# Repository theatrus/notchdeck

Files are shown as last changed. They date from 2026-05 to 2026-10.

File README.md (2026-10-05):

# NotchDeck



**NotchDeck One** is a BenchBits train controller project with USB HID and Bluetooth LE HID.
It supports our own Japanese-style **separate power lever and rotary brake**, or a
**combined mascon**. Each handle can use an AS5600 magnetic sensor or a Gray-code
contact cam. The goal is a driverless joystick with host-controlled lighting;
host/game compatibility has not yet been bench-tested.

## Current design: Rev G logic + Rev E button panel

| Assembly | Function | Provisional floorplan |
|---|---|---|
| [Logic / connectors](hardware/notchdeck-one/FLOORPLAN.md) | E73 nRF52840 module, USB/BLE, battery power, handle ports, Select/Start, two solenoids and buzzer | 115×90mm, four layers |
| [Button panel](hardware/notchdeck-buttons/README.md) | STM32G030, detachable 4×4 diode key matrix, 16 RGB LEDs | 86×120mm, two layers, 19mm key pitch |

A six-way 1mm FFC carries power, I²C and interrupt between boards. The selected cable
is Molex **0151670213** (DigiKey **WM13121-ND**); the panel guide records its reversed
connector numbering and remaining fit checks. The STM32G030 **C529330** was selected
from owned JLCPCB inventory.

The [actuator sheet](hardware/notchdeck-one/ACTUATORS.md) adds two PWM low-side
outputs, an active-buzzer output and 3.3V signals for an external 12V driver.
A TPS259461LRPWR electronic limiter protects the full battery input at 5.05A
nominal. The provisional target is two simultaneous 2A strikes of up to 100ms,
then lower PWM hold current. Use a protected ≥6A 1S pack for upstream shorts.
ACT_EN pauses charging during actuation; the PWM inputs default off.

Both hierarchical schematics are wired and pass strict ERC, complete net checks,
schematic/PCB parity and BOM audits. **Both PCBs are unrouted floorplans and are not
ready for fabrication.** The [hardware guide](hardware/README.md) tracks routing,
mechanical, power-budget and assembly work still required.

The nRF firmware builds against NCS v3.3.0, with host tests and six Rev C/D handle
profiles compiled in CI. **Panel firmware, main-board I²C integration and Rev G actuator control are
not implemented.** Keep loads disconnected when using old Rev C/D firmware.
Magnetic handles also require measured detent calibration. No production firmware,
bootloader integration or fabricated-controller validation is claimed.

## Handles and reports

Combined mode sends discrete notch values on HID **Y**: EB=`0x00`, N=`0x80`, P5=`0xFF`.
Separate-handle mode uses **Y=power, X=brake**, with brake priority and neutral
re-arming. Both magnetic and contact backends use absolute positions. See the
[handle interface](docs/06-handle-interfaces.md) for cam codes, calibration and
profiles, and the [own-build guide](docs/07-japanese-handle-build.md) for mechanisms
and the provisional panel layout.

## Checks and exports

Run from the repository root:

```sh
make -C firmware test             # host compiler only
make -C hardware verify           # KiCad 10 + Python with pcbnew
make -C hardware jlc              # separate logic and button assembly ZIPs
```

On Linux, pass `KICAD_PYTHON=python3` to hardware checks with KiCad's Python module
installed. The [hardware guide](hardware/README.md) covers setup and regeneration;
the [firmware guide](firmware/README.md) covers NCS builds and release commands.

Each hardware ZIP contains Gerbers, drill, BOM and pick-and-place (CPL) files.
Exports describe the current unfinished boards; exporting does not approve them
for manufacture. [Sourcing](docs/04-bom-sourcing.md) covers **five complete sets**:
213 installed parts and 44 JLCPCB codes per set, plus the separate cable. Stock
observations are dated snapshots, with private inventory retained outside Git.
The earlier Rev E parts order was placed; the Rev G actuator expansion still
needs a top-up for 20 sets plus 10% spares. See the sourcing guide.

[GitHub Actions](https://github.com/theatrus/notchdeck/actions/workflows/ci.yml)
publishes `notchdeck-boms` (both assembly BOMs) and `notchdeck-one-firmware`
(default nRF52840 DK bring-up UF2/HEX). Handle profiles are compile checks only;
there is no Rev E/F or STM32 image in those artifacts. CI checks floorplan DRC rules
and parity while allowing the documented unrouted connections.

## Documentation

| Guide | Contents |
|---|---|
| [Hardware](hardware/README.md) | KiCad projects, validation, manufacturing exports and open work |
| [Actuators](hardware/notchdeck-one/ACTUATORS.md) | Short protection, connectors, PWM limits and required firmware |
| [Firmware](firmware/README.md) | Build/test commands, CI artifacts and implementation status |
| [Architecture](docs/03-hardware-and-firmware-architecture.md) | Two-board design, buses, power and firmware responsibilities |
| [Sourcing](docs/04-bom-sourcing.md) | Assembly BOMs, five-set stock accounting and external parts |
| [Parts](hardware/PARTS.md) / [net plan](hardware/NETPLAN.md) | Exact selections, footprints, pad assignments and wiring |
| [Handle interfaces](docs/06-handle-interfaces.md) | Magnetic/Gray harnesses, codes, profiles and fault behavior |
| [Japanese-style handle build](docs/07-japanese-handle-build.md) | Own-build mechanics, provisional layout and cam targets |
| [Protocol](docs/02-emulation-protocol-spec.md) | HID reports, notch encoding and planned lighting features |
| [Firmware updates](docs/05-firmware-update.md) | Current artifacts, SWD access and proposed user-update path |
| [Research](docs/01-research-findings.md) | Original Zuiki/Densha de GO! protocol research and references |

## License

TBD; a project-wide license has not yet been selected. Third-party library sources
and licenses are recorded in [attributions](hardware/lib/ATTRIBUTIONS.md).

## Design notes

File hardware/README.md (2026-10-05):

# NotchDeck hardware

**Rev G logic and Rev E panel are two wired KiCad 10 assemblies:** `notchdeck-one` is the logic/handle board; `notchdeck-buttons` is the detachable 4×4 key/RGB board. The button board uses an owned **STM32G030F6P6TR / C529330** to scan a diode matrix and drive RGB locally. A six-way 1mm FFC carries I²C, interrupt and power. Select/Start remain direct inputs on the main board, alongside Reset.

| Project | Provisional PCB | Electrical components | Nets / endpoints | Assembly parts |
|---|---|---:|---|---:|
| [Logic](notchdeck-one/FLOORPLAN.md) | 115×90mm, four layers | 130 | 94 / 409 | 129 |
| [Buttons](notchdeck-buttons/README.md) | 86×120mm, two layers; 19mm key pitch | 85 | 56 / 235 | 84 |

Both have zero native ERC errors/warnings, complete independent net contracts, and matching PCB pad nets, schematic UUIDs and sourcing properties. Both are **unrouted floorplans**, with no tracks/vias/planes. Native DRC has no rule or schematic-parity violations; 323 logic and 211 button connections remain unrouted. Neither is ready to fabricate.

Open `notchdeck-one/notchdeck-one.kicad_pro` and
`notchdeck-buttons/notchdeck-buttons.kicad_pro` in KiCad 10 to inspect the complete
projects, then open each project's root schematic or PCB from its project manager.
The root schematics link the child sheets; symbols/footprints use standard KiCad
libraries plus the shared project-local `lib/` directory.

Magnetic and Gray-coded power/brake or combined mascon interfaces remain electrically unchanged. See [handle interfaces](../docs/06-handle-interfaces.md). U9 separates the two AS5600 address-0x36 channels; MAX17048 remains on another bus. Remove both R37/R38 before using an external power/combined sensor on J10.

Rev G adds [two solenoids, an active buzzer and external PWM](notchdeck-one/ACTUATORS.md). The actuator feed uses electronic current limiting, with no disposable fuse. A protected ≥6A 1S pack is mandatory for upstream battery-lead/PCB shorts. Full battery input protection is set to 5.05A nominal, with a 4.3A operating budget and two provisional 2A/100ms strikes. ACT_EN pauses charging; PWM pulldowns default the loads off.

## Source of truth and build

Edit `scripts/<project>.schgen.py` and each project's `bom/jlcpcb-parts.json`, then generate with the schematic editors closed. `notchdeck_capture.py` supplies shared wire/port capture; `kschgen.py` handles native files. Keep editor changes in those manifests before forcing regeneration. The saved PCBs become the source of truth once placement/routing proceeds; the seed floorplan script refuses to overwrite routed boards.

```sh
# From hardware/; <project> is notchdeck-one or notchdeck-buttons.
KSCHGEN_FORCE=1 make gen-notchdeck-one gen-notchdeck-buttons
make verify                     # both boards: net/ERC, PCB parity and BOM audits
make render-notchdeck-one render-notchdeck-buttons
make docs                       # both boards' images and BOMs
make jlc                        # two separate Gerber/drill/BOM/CPL ZIPs
make jlc-notchdeck-buttons       # or export one PCB
```

Pick-and-place files are `<project>/jlcpcb/<project>-CPL.csv`; ZIPs are `<project>/<project>-jlcpcb.zip`. These commands export the current design, including unfinished floorplans; they do not constitute a manufacturing release. Review rotations in JLCPCB before ordering. Generated exports are ignored by Git. CI audits both projects; on Linux pass `KICAD_PYTHON=python3` with `pcbnew` installed. See [script guide](scripts/README.md).

Use `KICAD_CLI=/Applications/KiCad/KiCad.app/Contents/MacOS/kicad-cli` on macOS
if the executable is not on PATH; the Makefile's native export targets need it.
The default `KICAD_PYTHON` points to KiCad's bundled macOS Python. Headless Linux
also needs the standard symbol/footprint tables installed, as shown in
[CI setup](../.github/workflows/ci.yml). Rendering PNG sheets requires an SVG
converter listed in the script guide.

CI publishes both generated BOM CSVs as `notchdeck-boms`; it does not publish
assembly ZIPs or CPLs. `make verify` does not include native DRC: CI runs that
separately, rejects rule/parity violations and reports unrouted counts. Before
manufacturing, all unintended unconnected items must also be resolved.

## Sourcing and remaining work

[PARTS.md](PARTS.md) maps all **213 installed parts / 44 JLCPCB codes** per set. [Five-set stock](jlcpcb-five-set-stock.csv) combines both boards’ usage: dated public availability or owned stock covers the five-set requirement; new C3662776 has 110 displayed in stock, with order allocation still to confirm. Private inventory balances remain outside Git. [System BOM](system-bom.csv) adds one DigiKey Molex 0151670213 cable per set. The user placed the earlier Rev E parts order; the shared CSV was refreshed afterward. Rev G additions need a separate top-up, recorded locally in `~/Dropbox-elec/github/notchdeck-actuator-expansion-2026-10-04.csv`. Stock observations do not reserve parts. Handle mechanisms, external sensor carriers, cell, keycaps and enclosure are not yet a sourced kit.

- Implement panel MCU firmware and main I²C integration. Existing Rev C/D direct-GPIO button/RGB firmware does **not** operate this Rev E panel. The [panel guide](notchdeck-buttons/README.md) records pin functions, scan behavior, address and programming requirements.
- Implement Rev G actuator startup/strike/hold, instantaneous current-budget scheduling, undervoltage shutdown, fault latching and timeout handling. No safe actuator image exists yet. Select actual coils/buzzer and a protected pack; qualify short behavior and temperature rise.
- Finalize enclosure, cable fit/retention and tolerances, mounting and connector access. The FFC is nominally compatible; its guaranteed thickness tolerance is wider than the connector drawing. Sample-fit or supplier approval remains required.
- Validate E73 land pattern/antenna region and MAX17048 exposed pad. Review final CPL orientation and assembly eligibility.
- Resolve USB source/current/inrush and the existing 500mA charger setting. RGB is USB-only; a ≤250mA total panel return target is below the 0.5A FFC-contact rating, but still needs firmware enforcement and a whole-system power budget. Review LDO margins and battery choice.
- Finish decoupling placement, USB/ESD routing, reference planes and ground stitching; route and run final DRC/DFM/EMC checks. Magnetic detents need measured calibration; handle hardware and power/thermal behavior need bench testing.

Connectivity and catalog checks establish internal consistency, not complete electrical, mechanical or production validation. No ERC exclusions were added.

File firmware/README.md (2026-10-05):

# NotchDeck One firmware

nRF52840 USB HID + BLE HOGP application using **nRF Connect SDK v3.3.0**, pinned in
[west.yml](west.yml). CI builds the nRF52840 DK bring-up image and six Rev C/D
handle profiles. Host tests exercise report layout and sensor-independent handle
behavior. The application has not been validated on a fabricated controller.

## Rev E panel / Rev G actuator support status

Rev G adds SOL1 P0.20, SOL2 P0.13, BUZZ P0.22, ACT_EN P0.24 and
BAT_nFAULT P1.00. ACT_EN inhibits charging only; stop PWM and keep charging inhibited on a fault. **No actuator backend is implemented.** Do not attach loads
when using the old Rev C/D overlays: these pins have different roles there.
Implement the default-off, strike/hold, 2A/100ms per-channel strike target and 4.3A total input budget, charger interlock/low
battery shutdown, watchdog and fault latch requirements in the
[actuator guide](../hardware/notchdeck-one/ACTUATORS.md) before energizing loads.

Rev E moves the 4×4 keys and RGB to an STM32G030 panel over I²C. **The existing
Rev C/D direct-GPIO overlay and LED driver do not operate that panel.** There is
no Rev E production image or STM32 firmware yet. The [panel guide](../hardware/notchdeck-buttons/README.md)
defines hardware pin functions and the interface requirements still to implement.

Handle decoding supports combined mascon or independent power/brake, with a
magnetic or Gray backend per handle, debounce/hysteresis, brake priority and
neutral re-arming. Magnetic calibration is deliberately empty until real detent
angles are measured. See [handle interfaces](../docs/06-handle-interfaces.md).

## Source layout

| Path | Responsibility |
|---|---|
| `src/hid_descriptor.h`, `src/report.h` | Shared HID descriptor and packed input/output reports |
| `src/handle_decode.c`, `src/handle_calibration.h` | Pure handle behavior and measured calibration inputs |
| `src/lever.c` | Sensor access and handle configuration |
| `src/report_engine.c` | Direct GPIO button input and report assembly; panel/nav/reverser integration pending |
| `src/transport_usb.c`, `src/transport_ble.c` | USB HID and BLE HIDS transports |
| `src/leds.c` | Legacy direct-strip lighting skeleton; Rev E panel backend pending |
| `src/main.c`, `src/dfu.c` | Boot-time transport choice, report loop and proposed bootloader-entry request |
| `boards/`, `configs/` | DK overlay and Rev C/D handle build profiles |
| `test/` | Host report and handle tests |

## Build

Use an NCS v3.3.0 toolchain environment with `west`, CMake/Ninja and the SDK's
Python dependencies installed. From the repository root, initialize a **new**
workspace with the local manifest if this checkout is not already in one:

```sh
west init -l firmware
west update
west zephyr-export
```

Do not reinitialize an existing SDK workspace. CI's exact environment is recorded
in [ci.yml](../.github/workflows/ci.yml). The default target is the DK bring-up
configuration, with placeholder peripheral pins and the DK flash layout:

```sh
# From the repository root:
make -C firmware test
make -C firmware build
make -C firmware uf2
make -C firmware release
```

The wrapper explicitly uses sysbuild. Default outputs are
`firmware/build/firmware/zephyr/zephyr.{uf2,hex}`; release copies them to
`firmware/dist/notchdeck-one-vX.Y.Z.{uf2,hex}`. Override `BOARD` or `BUILD` as needed;
relative `BUILD` paths are resolved from `firmware/`. Use a fresh build directory
when changing boards or moving an old non-sysbuild build to this wrapper.

Equivalent direct build from the repository root:

```sh
west build --sysbuild -b nrf52840dk/nrf52840 firmware -d build
# Outputs: build/firmware/zephyr/zephyr.uf2 and zephyr.hex
```

`make -C firmware flash` builds and flashes the selected target over SWD;
`make -C firmware menuconfig` opens the application's Kconfig. The default target
is for a connected DK, not a production Rev E flash recipe. For Rev C/D handle
compile profiles, use the [profile command](../docs/06-handle-interfaces.md#firmware-profiles-and-output).
Handle assignments survive into Rev E, but the panel needs a new integration.

## Tests and CI artifacts

`make -C firmware test` requires only a host C compiler. It checks seven-byte
report layouts, IDs, offsets and the DFU combo mask, plus Gray patterns,
calibration validation, angle wrapping, hysteresis, debounce, stale-input faults,
brake priority and re-arming.

[GitHub Actions](https://github.com/theatrus/notchdeck/actions/workflows/ci.yml) runs:

- `host-test`: both host tests and mechanical drawing/cam-table consistency.
- `firmware-build`: default DK sysbuild plus all six Rev C/D profiles.
- `hardware-checks`: both PCBs' net/ERC, schematic/PCB, BOM and floorplan DRC checks.

Download `notchdeck-one-firmware` for `notchdeck-one.uf2` and `notchdeck-one.hex`
from the **default DK build**. Profile builds are compile checks and are not
uploaded. `notchdeck-boms` contains both PCB assembly CSVs. Missing artifact files
fail CI; assembly ZIPs/CPLs are generated locally with `make -C hardware jlc`.

## Updates and versioning

UF2 output is enabled, but generating a UF2 file does **not** install or validate
an on-device bootloader. Double-tap Reset and Select+Start entry are proposed user
flows dependent on the final board/bootloader/flash layout. There is no OTA package
or tested update path yet; see [firmware updates](../docs/05-firmware-update.md).

`VERSION` supplies Zephyr's application version and release filenames.
`CONFIG_BT_DIS_FW_REV_STR` in `prj.conf` is currently a separate literal: update it
with `VERSION`. The release target copies files; it does not synchronize that
string, sign images, build a bootloader or publish a GitHub release.

## Remaining implementation

- Implement STM32 scanning/RGB firmware, a versioned I²C contract, and the main
  Rev E backend/overlay, including Select/Start merging and disconnect handling.
- Measure magnetic detent calibration and bench-test sensors, harnesses and faults.
- Implement panel navigation/hat conversion, reverser sampling and button debounce.
- Enforce the panel/USB current budget; finish output-report rendering and timeout
  behavior with the panel backend.
- Add live VBUS transport switching and MAX17048 battery-service updates.
- Finalize a production board definition, USB IDs, bootloader and flash partitions;
  implement feature-report handlers if retained. Validate USB/BLE behavior on hosts.

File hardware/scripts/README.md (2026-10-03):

# hardware/scripts

Tooling for the BenchBits KiCad projects. Driven via the `Makefile` (preferred)
or run directly. All locate `kicad-cli` via `$KICAD_CLI`, then `PATH`, then the
macOS app bundle (`/Applications/KiCad/KiCad.app/...`).

| Script | Make target | What it does |
|---|---|---|
| `<project>.schgen.py` | `make gen-<project>` | Regenerate the hierarchical schematic from a data manifest. |
| `kschgen.py` | — | Generic generation engine imported by the `*.schgen.py` manifests. |
| `kicad-sch-check.py` | `make check-<project>` | Sanity-check a schematic: component count, missing footprints, duplicate refs, ERC tally. Exits non-zero on a structural problem. |
| `kicad-sch-render.sh` | `make render-<project>` | Render schematic sheet(s) to PNG for a quick visual review. |
| `notchdeck-netcheck.py` | `make verify-notchdeck-one` | Independent complete pin/net contract and strict native ERC. |
| `notchdeck-panelcheck.py` | `make verify-notchdeck-buttons` | Complete panel pin/net contract, FFC reversal and strict ERC. |
| `notchdeck-boardcheck.py` | `make verify-pcb-<project>` | Compare every PCB pad, footprint identity and schematic UUID path to the native netlist. |
| `notchdeck-bomcheck.py` | `make verify-bom-<project>` | Compare native assembly BOM identity, quantities, footprints and exclusions to reviewed JLCPCB selections. |
| `notchdeck-floorplan.py` | — | Seed the selected board's provisional placement; subsequent edits belong in the saved PCB. |
| `jlcpcb-package.sh` | `make jlc-<project>` | Gerbers + drill + BOM + CPL → JLCPCB zip. |

## Generating a schematic from a manifest

`scripts/<project>.schgen.py` is **data**: it registers the symbol libraries the
board uses, lists the components per hierarchical sheet (ref / lib_id / value /
footprint / LCSC / MPN / ...), and adds a free-text wiring note per sheet. The
reusable logic lives in `kschgen.py`, which hand-authors KiCad-10 schematic files
in the format used across the BenchBits projects (root sheet of hierarchical
sheet symbols + one child `.kicad_sch` per block, every part resolving to a real
library symbol + footprint, `extends`-derived symbols handled).

```sh
# From hardware/; use either project name for individual targets.
make gen-notchdeck-one gen-notchdeck-buttons  # missing sheets only
make verify                                  # strict audits on both boards
make render-notchdeck-one render-notchdeck-buttons
```

NotchDeck's manifest now captures **components, wiring, hierarchical ports and
layout**. The `Capture` helper groups local circuits and checks that every pin is
wired or explicitly NC. The logic root connects MCU, Power, Lever and Controls; the button root connects Controller and Buttons. `notchdeck_capture.py` shares the Capture helper.
By default, `gen` keeps existing sheets intact. Close the NotchDeck schematic editor,
then use `KSCHGEN_FORCE=1 make gen-<project>` to apply manifest changes.
Manual editor changes must be reflected in the manifest before a forced rebuild.
The wired-sheet writer retains placed-symbol UUIDs by reference so forced rebuilds
keep existing PCB footprint associations. Root sheet instances include explicit
page numbers and the project records the actual root UUID.

`make verify-notchdeck-one` exports KiCad XML and compares **every endpoint** to
`scripts/notchdeck-netcheck.py`, then requires zero ERC violations. This independent
contract checks rail isolation, MCU pads, both I2C buses, USB pairs, the power path,
SWD/reset, all switches, reverser and the panel link; the panel contract covers the matrix and LEDs. Set `NETCHECK_OUT` to a
local directory to retain netlist/JSON reports. It checks both opens and extra pins
(shorts), not just whether an expected pair happens to share a net.

The engine supports component rotation and field offsets. Derived-library symbols
are flattened with property overrides, matching KiCad's library resolver.
Notes render in a fixed-width font; use `K.note_block()` and `K.pin_table()` in
manifests when writing pin maps or wiring tables that need alignment.

Each project’s `bom/jlcpcb-parts.json` holds reviewed sourcing assignments. The
manifest writes its LCSC/MPN/Manufacturer/Datasheet and hidden BOM review properties
onto each symbol; the engine also supports generic hidden `properties` dictionaries.
The assembly export groups by sourcing identity as well as value/footprint and
disables compressed reference ranges. `make verify-bom-<project>` checks this
native export; `--bom <csv>` can inspect a saved snapshot. It does not query live stock.
Refresh the tracked `bom/jlcpcb-bom.csv` and BOM-skill `bom/bom.csv` after sourcing
changes pass verification. PCB consistency also checks sourcing properties and
BOM/placement exclusions, including bare logic J4 and panel J2 programming contacts.

**A new board:** copy an existing `*.schgen.py`, change the `register_*` calls,
the component lists and the notes, then add the project to `PROJECTS` in the
`Makefile`. No engine changes needed.

## PCB placement and consistency

`make verify-pcb-notchdeck-one` requires a Python interpreter with KiCad's `pcbnew`
module. The Makefile defaults to the macOS KiCad bundled Python; override
`KICAD_PYTHON` elsewhere. Both new PCB tools respect `KICAD_CLI` (default
`kicad-cli` on PATH). The audit loads a temporary board copy to keep project
settings read-only. Native DRC remains a separate check:

```sh
make verify-pcb-notchdeck-one
kicad-cli pcb drc --schematic-parity notchdeck-one/notchdeck-one.kicad_pcb
```

`notchdeck-floorplan.py` is a seed script, **not a round-trip PCB generator**.
It refuses to overwrite a populated board unless explicitly passed
`--replace-unrouted`, and always refuses boards containing tracks, vias or copper
pours. Close the PCB editor before using it. SaveBoard runs in a temporary
directory and copies only the PCB back, preserving project design rules.
Normal `make gen` never runs it. Edit the saved board in KiCad from this point on.

## Notes

- `kicad-sch-render.sh` converts SVG→PNG with the first available of
  `rsvg-convert` / `inkscape` / `cairosvg` / macOS `qlmanage`. Output goes to a
  temp dir (override with `$RENDER_OUT`); pass sheet name(s) to render a subset.
- Derived symbols are now flattened correctly, including their overridden properties;
  no library-mismatch ERC warnings are expected for this project.

## Rev E two-board exports

`make verify` covers both projects. PCB/BOM audit scripts accept `--project notchdeck-one|notchdeck-buttons`. The floorplan script accepts the same selector. `make jlc` builds separate ZIPs, each with Gerbers, drill, BOM and `<project>-CPL.csv`. It does not gate fabrication readiness; both saved boards are still unrouted. One Molex FFC per system is listed separately in `hardware/system-bom.csv`. Consolidated stock in `hardware/jlcpcb-five-set-stock.csv` counts both boards.

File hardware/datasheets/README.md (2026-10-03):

# Local datasheet cache

`manifest.json` records manufacturer PDFs for the reviewed JLCPCB selections in
both projects’ `bom/jlcpcb-parts.json` files. Cached PDFs use their `C<number>.pdf`
catalog codes and remain git-ignored. References are board-qualified to avoid U1/J1 collisions. Download each manifest URL to its listed
filename to rebuild the cache.

Catalog matching and document drawing checks are described in
[`../notchdeck-one/bom/README.md`](../notchdeck-one/bom/README.md). A downloaded PDF
does not mean every electrical or mechanical parameter has been verified.

The initial automated MPN search returned unrelated parts for several connectors.
Those results were rejected; this manifest uses the exact selected catalog codes
and URLs instead. Do not accept a fuzzy distributor-search result without checking
its manufacturer, MPN and package. Older local PDFs outside this manifest are not
authoritative selections.

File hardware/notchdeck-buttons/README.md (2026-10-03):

# NotchDeck Buttons — Rev E

An independent 4×4 key/RGB assembly driven by **STM32G030F6P6TR (C529330)** from owned JLCPCB stock. It connects to the logic board through a six-conductor FFC. The schematic is wired and checked; the 86×120mm two-layer PCB is an **unrouted floorplan**. Panel firmware and main-controller integration are not implemented yet.

## Connector and cable

Both connectors are **JUSHUO AFA07-S06FCA-00 / C262712**, 6 contacts, 1mm pitch, bottom contact, nominal 0.30mm FFC ends. Use **Molex 0151670213**, DigiKey **WM13121-ND**, Type A same-side exposed contacts, 177.8mm long. Five cables are listed in the [system BOM](../system-bom.csv); the assembly BOMs contain only the PCB connectors.

Identical bottom-contact connectors at opposite ends of a Type A cable reverse connector numbering. The schematic compensates deliberately: **main pin n connects to button pin 7−n**. Insert exposed contacts toward each PCB; power off for insertion/removal. This is an internal enclosure interconnect.

| Main J15 | Signal | Button J1 |
|---:|---|---:|
| 1 | GND | 6 |
| 2 | 3V3 — MCU and keys, including battery operation | 5 |
| 3 | SDA — I2C0 on main, I2C1 PB7 AF6 on panel | 4 |
| 4 | SCL — I2C0 on main, I2C1 PB6 AF6 on panel | 3 |
| 5 | IRQ_N — PC15 open drain to E73 P1.11 | 2 |
| 6 | USB_VBUS — RGB only | 1 |

The [JUSHUO family specification](https://datasheet.lcsc.com/datasheet/pdf/8c3225c8bd3c5aba9addae56ddc79a88.pdf?productCode=C262714) explicitly covers AFA07-S**FCA-00 and rates contacts at 0.5A. The [Molex family specification](https://www.molex.com/content/dam/molex/molex-dot-com/products/automated/en-us/productspecificationpdf/151/15167/PS-15167-001-001.pdf) rates the cable at 0.8A per conductor at 23°C; the connector limits this link. Target **≤250mA total panel return current**, including 3V3 and LED loads, subject to the main USB/charger budget. This is a firmware/current-budget requirement, not an implemented hardware limit. Full-white unrestricted LEDs are not supported by this budget.

Pitch, contact side and nominal end thickness agree with the drawings. JUSHUO specifies 0.30±0.03mm cable thickness; Molex guarantees 0.30±0.05mm ends, so worst-case tolerance compatibility is **not established**. Validate insertion, retention and contact resistance on samples, or obtain supplier approval before production. Confirm end-to-end pin numbering with a continuity check before first power. Stock: JLCPCB 31,746 available connectors; DigiKey 139 cables on 2026-10-03, before reservations/attrition.

## MCU pin plan

| U1 pad | Selected GPIO/function | Net |
|---:|---|---|
| 1 | PB7 / I2C1_SDA AF6 | SDA |
| 3 | PC15 open drain | IRQ_N |
| 4 / 5 | VDD / VSS | 3V3 / GND |
| 6 | NRST | 10k pull-up, 100nF, J2 reset |
| 7–10 | PA0–PA3 | ROW0–ROW3 |
| 11–14 | PA4–PA7 | COL0–COL3, external 10k pull-ups |
| 15 | PA8 / TIM1_CH1 AF2 | RGB_PWM → AHCT U8 |
| 17 | PA12 / ADC_IN16 | VBUS_SENSE, 100k/100k divider and 100nF |
| 18 / 19 | PA13 / PA14 | SWDIO / SWCLK |
| 20 | PB6 / I2C1_SCL AF6 | SCL |

Pads 2 and 16 are intentionally unused. On internally bonded pads, leave the unused PB8, PB3/PB4/PB5, PB0/PB1/PB2, PA10 and PA15 aliases analog/high impedance. SWD must remain enabled, and boot option bytes must select user flash without sacrificing PA14 SWCLK. Use HSI/PLL; no crystal or external flash is required. Evidence: [ST DS12991](https://www.st.com/resource/en/datasheet/stm32g030f6.pdf), pin/alternate-function and package tables. Stock identity/footprint checked against the selected TSSOP-20 ordering code.

Each key has a 1N4148W: column → switch → diode anode → cathode → row. Pull one row low, leave the other rows high impedance, wait for settling, then read four active-low columns. This orientation supports simultaneous keys without ghost paths. SW1–SW12 retain BTN1–BTN12; SW13–SW16 are Up, Down, Left, Right. Physical button pitch is 19mm.

The local AHCT buffer and RGB chain use USB_VBUS. The MCU uses 3V3, so key input works on battery. Use the VBUS divider as an ADC input, not a digital threshold. Hold RGB_PWM low whenever USB is absent and at reset; R26 provides the default pull-down. J2 is bare TC2030-NL SWD access, excluded from assembly: 1=3V3, 2=SWDIO, 3=NRST, 4=SWCLK, 5=GND, 6=NC. Program the MCU via SWD; there is no panel USB connector or implemented I²C bootloader.

## Firmware interface to implement

Use I²C target address **0x20** on the upstream main I2C0 bus at 100kHz. Main R9/R10 provide its only pull-ups. The handle mux remains 0x70 and selected magnetic sensor 0x36; the fuel gauge remains on separate I2C1. Start with a 1kHz complete matrix scan, roughly 10ms stable-state debounce, and an atomic 16-bit pressed-key bitmap with a sequence counter. Assert IRQ until the latest stable state is acknowledged, avoiding a lost update when a key changes during a read. Retain a periodic poll as a fallback.

Define a versioned register/packet contract before implementing either side. Include LED frame/brightness commands and status (VBUS, firmware version, faults); use timer/DMA so RGB generation does not block I²C service. On communications loss, main releases panel keys and panel turns LEDs off. OR main SW18/SW19 into Select/Start so either physical location works. Define low-power scanning/wake behavior for BLE use and test rollover, debounce, reset during transfer, cable disconnect, brownout and USB removal. No wire protocol or executable panel firmware is claimed by this hardware revision.

## Checks

`make -C hardware verify` verifies both assemblies. Panel audit covers 85 components, 56 nets, 235 endpoints, four intentional NCs and every FFC conductor; native ERC has zero errors/warnings. BOM/CPL contains 84 parts (13 catalog codes). See [floorplan](FLOORPLAN.md) for placement/routing status.

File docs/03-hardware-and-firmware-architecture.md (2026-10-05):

# Hardware and firmware architecture — Rev G logic / Rev E panel

Rev E separates the controller's logic/handle connectors from its 4×4 button panel.
Both schematics are wired and checked; both PCBs remain unrouted. This describes
the captured design and identifies firmware that still needs implementing.
See [hardware status](../hardware/README.md) for validation and remaining work.

## Board responsibilities

| Logic: `notchdeck-one` | Panel: `notchdeck-buttons` |
|---|---|
| Ebyte E73-2G4M08S1C, nRF52840, JLCPCB C356849 | STM32G030F6P6TR, JLCPCB C529330 from owned inventory |
| USB HID and BLE HOGP, report engine and handle decoding | 4×4 diode matrix scan/debounce and local RGB generation |
| USB-C, charger, battery power path, 3V3 and fuel gauge | 3V3 MCU/key power and USB-only RGB power from FFC |
| Magnetic and Gray handle ports, optional reverser input | 16 keys at 19mm pitch and 16 addressable RGB LEDs |
| Local Select/Start plus Reset; SWD access | Separate TC2030 SWD access |
| 115×90mm, four layers | 86×120mm, two layers |

The nRF52840 supplies USB and BLE on one device. The second MCU keeps matrix/RGB
wiring local to the removable panel and reduces the interconnect to six conductors.
Its scan and I²C-target firmware is **not implemented yet**.

```text
USB host <--> E73 nRF52840 <--> BLE host
                  |
                  +-- I2C0 --+-- STM32 panel (planned address 0x20)
                  |          |      +-- 4x4 diode key matrix
                  |          |      +-- AHCT buffer --> 16 RGB LEDs
                  |          +-- TCA9543A mux (0x70)
                  |                 +-- channel 0: power / combined AS5600 (0x36)
                  |                 +-- channel 1: brake AS5600 (0x36)
                  +-- I2C1 ------ MAX17048 fuel gauge (0x36)
                  +-- GPIO ------ Gray handle ports, Select/Start, panel IRQ
                  +-- ADC ------- optional reverser
```

## Inputs and panel link

The [handle interface](06-handle-interfaces.md) supports a combined 15-position
mascon, or independent power Off/P1–P5 and brake Release/B1–B8/EB. Each active
handle independently selects magnetic or Gray-code sensing. Existing nRF code
implements calibrated angle hysteresis, Gray debounce, brake priority, stale-input
fault handling and neutral re-arming. Magnetic calibration arrays are intentionally
empty until actual detent angles are measured.

Both AS5600 channels use address 0x36. The mux selects one channel at a time;
the MAX17048 with the same address uses a separate nRF I²C controller. Remove
**both R37 and R38** to isolate onboard U5 before connecting an external
power/combined sensor at J10. J11 always needs an external brake sensor.

The six-way FFC carries GND, 3V3, SDA, SCL, IRQ and USB_VBUS. Two identical
bottom-contact connectors and the specified Type A cable use **main J15 pin n →
panel J1 pin 7−n**. The [panel guide](../hardware/notchdeck-buttons/README.md)
defines the exact cable, connector pinout, MCU aliases and scan requirements.
I²C runs at 100kHz; its versioned panel register/packet protocol remains to be
defined. The main firmware must merge panel input with local Select/Start,
release panel keys on communications loss, and send bounded RGB commands.

Rev G assigns five of the former direct button/RGB GPIOs to actuators and leaves nine spare GPIOs, including NFC pins. No external LF
crystal is populated; retain the nRF RC LFCLK and P0.18 reset/UICR configuration.
The [net plan](../hardware/NETPLAN.md) is the pad-level reference. Rev C/D firmware
overlays do not support the new panel despite unchanged handle pin assignments.

## HID and transport behavior

USB and BLE use the same descriptor and seven-byte input/output payloads; USB
includes a report-ID prefix. Combined handles emit the canonical Y-notch values;
dual profiles use Y=power and X=brake, or can select combined output with brake
priority. See the [protocol spec](02-emulation-protocol-spec.md).

Current `main.c` selects USB when VBUS is present **at boot**, otherwise BLE.
Live USB plug/unplug arbitration is still TODO. BLE includes HIDS, Battery Service,
Device Information and settings/bond storage, but live fuel-gauge updates are not
implemented. Host/game compatibility needs device testing. Feature report 3 is
declared in the descriptor without implemented handlers or a finalized layout.

## Power and lighting

USB_VBUS feeds the USB regulator, MCP73832 charger and panel RGB rail. A Schottky
USB feed and AO3401A battery power path supply VSYS, then AP2112K-3.3 supplies both
MCUs and key/sensor circuitry. MAX17048 monitors BAT+. This is the discrete power
path captured in the schematics; the earlier nPM1300 proposal is not populated.

The RGB chain and SN74AHCT1G125 level shifter are on the button board and powered
only from USB. The STM32 must hold RGB output low without VBUS and use timer/DMA
to avoid blocking I²C. Target **≤250mA total panel return current**, including
3V3 and LED loads. This limit is not yet enforced. The existing 500mA charger
setting, USB source allowance/inrush, battery choice and LDO margins require a
complete power review before fabrication. USB presence does not authorize
unrestricted full-white LEDs.

The current nRF `leds.c` is an older direct-strip skeleton: its host override,
warning lamps, speed/status rendering and timeout behavior are incomplete. Rev E
needs a panel transport backend. There is no selected display. Rev G provides an external active-buzzer driver, but the buzzer and solenoid assemblies are not yet selected.

## Rev G actuators and protection

Two battery-voltage solenoids and an active buzzer use owned ZXMS6005DGTA
low-side drivers and B360A flyback diodes. J19 provides 3.3V commands for an
external 12V booster/driver. Rev G puts TPS259461LRPWR protection ahead of
**all battery-fed functional branches**, with 5.05A nominal current limiting
and latched thermal shutdown. Two simultaneous 2A strikes (≤100ms provisional)
fit a 4.3A input budget; hold current is lower and calibrated. J2 is an owned
Micro-Fit 2+2 battery inlet. ACT_EN operates Q5/Q6 charger inhibit only; on a
fault firmware must stop PWM while keeping charging inhibited. A protected
≥6A 1S pack is required for upstream shorts. No disposable fuse is used.

Actuator firmware is pending. The [actuator guide](../hardware/notchdeck-one/ACTUATORS.md) defines pinouts, protection boundaries, timed strike/500Hz hold PWM, fault behavior and bench checks. Duty control does not measure individual coil current; external 12V drivers need their own protection.

## Implementation and validation

NCS is pinned to v3.3.0 in `firmware/west.yml`. CI runs host report/handle tests,
checks generated mechanical drawings, and compiles the DK bring-up image plus six
Rev C/D handle profiles. The [firmware guide](../firmware/README.md) documents
commands and exact artifact paths. These checks do not establish Rev E firmware
support or a production bootloader/flash layout.

Hardware CI verifies both schematics' nets/ERC, PCB identity/pad nets, BOMs and
native DRC. Unconnected items are allowed only because the saved PCBs are
floorplans. Routing, final mechanical fit, power/thermal review, assembly checks
and bench validation remain open. Current selections and dated stock records
are linked from [sourcing](04-bom-sourcing.md).

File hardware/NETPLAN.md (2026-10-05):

# NotchDeck One — net plan (E73 pad → peripheral)

Pad-level reference for the captured schematic. Pad numbers are the
**E73-2G4M08S1C** module pads (per `lib/symbols/notchdeck:E73-2G4M08S1C`, confirmed against
Ebyte's pin table). Parts/refs follow [`PARTS.md`](PARTS.md). GPIO assignments are the captured Rev G
default; change the manifest, independent net contract, saved PCB and firmware
together when reassigning them.

> **Two design constraints baked in here:**
> 1. **AS5600 and MAX17048 share I²C address `0x36`** → they go on **two separate I²C buses**
>    (nRF52840 TWIM0 + TWIM1), not one shared bus.
> 2. **P0.18** remains nRESET; enable reset in UICR. No LF crystal is populated, so retain RC LFCLK. Rev E frees the former NFC/LFXO button pins; old Rev C/D GPIO button firmware does not apply to the split panel.

## Full E73 pad assignment

| Pad | E73 signal | Net / function | Notes |
|---|---|---|---|
| 19 | VDD | **+3V3** | main supply |
| 23 | VDDH | **+3V3** | tie to VDD (normal-voltage mode) |
| 25 | DCCH | **NC** | high-voltage DC/DC node — leave open when VDD=VDDH=3V3 |
| 27 | VBUS | **USB_VBUS (5V)** | feeds nRF USB regulator + on-chip VBUS-detect (no GPIO needed) |
| 5, 21, 24 | GND | **GND** | |
| 29 | USB_D− | **USB_DM** | to USB-C D− pair |
| 31 | USB_D+ | **USB_DP** | to USB-C D+ pair |
| 26 | P0.18/RESET | **nRESET** | RESET button + SWD; double-tap DFU requires the planned bootloader |
| 37 | SWDIO | **SWDIO** | SWD header |
| 39 | SWDCLK | **SWDCLK** | SWD header |
| 12 | P0.26 | **I2C0_SDA** | → handle mux + button panel (bus 0) |
| 14 | P0.06 | **I2C0_SCL** | → handle mux + button panel (bus 0) |
| 20 | P0.12 | **I2C1_SDA** | → MAX17048 (bus 1) |
| 22 | P0.07 | **I2C1_SCL** | → MAX17048 (bus 1) |
| 16 | P0.08 | **NC** | Former direct button/RGB input; intentionally unused in Rev E |
| 7 | P0.02/AIN0 | **REVERSER_AIN** | 3-pos reverser via resistor divider (ADC); or 2 GPIO |
| 28 | P0.15 | **FG_ALRT** | MAX17048 ALRT (open-drain in, pull-up) |
| 30 | P0.17 | **CHG_STAT** | MCP73832 STAT (open-drain in / LED) |
| 1 | P1.11 | **PANEL_INT** | Button-board IRQ_N, active-low open drain; R42 10k pull-up |
| 2 | P1.10 | **NC** | Former direct button/RGB input; intentionally unused in Rev E |
| 6 | P1.13 | **NC** | Former direct button/RGB input; intentionally unused in Rev E |
| 17 | P1.09 | **NC** | Former direct button/RGB input; intentionally unused in Rev E |
| 32 | P0.20 | **SOL1_PWM** | Q2 solenoid 1 input and J19.2 via series resistors |
| 33 | P0.13 | **SOL2_PWM** | Q3 solenoid 2 input and J19.3 via series resistors |
| 40 | P1.04 | BTN7 select | |
| 42 | P1.06 | BTN8 start | |
| 34 | P0.22 | **BUZZ_PWM** | Q4 active buzzer input and J19.4 via series resistors |
| 35 | P0.24 | **ACT_EN** | Charger inhibit only; high pauses charging; keep high on a fault |
| 36 | P1.00 | **BAT_nFAULT** | U13 overcurrent/thermal fault, active-low open drain; 10k pull-up |
| 38 | P1.02 | **NC** | Former direct button/RGB input; intentionally unused in Rev E |
| 41 | P0.09/NFC1 | **NC** | Former direct button/RGB input; intentionally unused in Rev E |
| 43 | P0.10/NFC2 | **NC** | Former direct button/RGB input; intentionally unused in Rev E |
| 11 | P0.00/XL1 | **NC** | Former direct button/RGB input; intentionally unused in Rev E |
| 13 | P0.01/XL2 | **NC** | Former direct button/RGB input; intentionally unused in Rev E |
| 3 | P0.03/AIN1 | **LEVER_S0** | coded-switch bit 0 (J5.2); GPIO in, ext 10k pull-up + RC debounce |
| 4 | P0.28/AIN4 | **LEVER_S1** | coded-switch bit 1 (J5.3); GPIO in, ext 10k pull-up + RC debounce |
| 8 | P0.29/AIN5 | **POWER_S0** | power Gray bit 0, J12.2, external pull-up + RC |
| 9 | P0.31/AIN7 | **POWER_S1** | power Gray bit 1, J12.3, external pull-up + RC |
| 10 | P0.30/AIN6 | **POWER_S2** | power Gray bit 2, J12.4, external pull-up + RC |
| 15 | P0.05/AIN3 | **LEVER_S3** | coded-switch bit 3 (J5.5); GPIO in, ext 10k pull-up + RC debounce |
| 18 | P0.04/AIN2 | **LEVER_S2** | coded-switch bit 2 (J5.4); GPIO in, ext 10k pull-up + RC debounce |

Rev E moves all 16 panel keys and RGB output to the button MCU. Main retains BTN7 (SW18 Select) and BTN8 (SW19 Start); future firmware must combine the panel's corresponding keys with these. Rev G reuses five former GPIOs for the actuator bank, leaving nine spare GPIOs intentionally NC. Gray handle inputs and magnetic buses remain independent and unchanged.

## Rev E button interconnect

Main J15 is a six-way 1mm FFC, using Molex 0151670213 Type A. Pin1 GND, pin2 3V3, pin3 I2C0_SDA, pin4 I2C0_SCL, pin5 PANEL_INT, pin6 USB_VBUS. Button J1 reverses the assignment: **main n → button 7−n**. R42 pulls IRQ up; U12 protects SDA/SCL and C44 bypasses 3V3. Existing R9/R10 are the only upstream I²C pull-ups. Use 100kHz; panel target address is 0x20. The main logic board remains the I²C controller.

Button U1 is STM32G030F6P6TR, scanning PA0–3 rows and PA4–7 columns with one isolation diode per key. PB6/PB7 AF6 provide I2C1; PC15 is open-drain IRQ; PA8 TIM1_CH1 AF2 drives local U8 AHCT and the RGB chain; PA12 ADC_IN16 measures divided VBUS. Key power is 3V3 including battery; RGB is USB-only. See [panel pin plan, cable ratings and firmware requirements](notchdeck-buttons/README.md). Both MCUs require separately programmed firmware; the Rev C/D overlay is not a Rev E firmware solution.

## Power architecture

```
USB-C VBUS (5V) ──[TVS/ESD]──┬─────────────► E73 VBUS (pad 27)   ; USB regulator + VBUS-detect
                             │
                             ├─► MCP73832 VDD (charge in)
                             │      MCP73832 VBAT ─► BAT_PROT   ; PROG R sets I_chg
                             │      MCP73832 STAT ─► CHG_STAT (P0.17) + LED
                             │
                             └─► [power-path OR-ing] ─► VSYS ─► AP2112K-3.3 ─► +3V3
   BAT → U13 → BAT_PROT ───────► [power-path OR-ing] ─┘                        │
                                                                    ┌──────────┴───────────┐
                                                            E73 VDD (19) + VDDH (23)   panel MCU / sensors
```

- **+3V3 rail:** AP2112K-3.3 LDO from `VSYS`. Feeds E73 `VDD`(19) **and** `VDDH`(23) tied
  together (normal-voltage mode — the module's internal DC/DC inductor handles REG1; `DCCH`(25)
  stays open). Decouple VDD/VDDH with 100 nF + 1 µF each, plus a 4.7–10 µF bulk on +3V3.
  AP2112K `EN` → tie to `VIN` (always-on); 1 µF in/out caps.
- **VBUS to the module:** USB-C `VBUS` → E73 `VBUS`(27). The nRF52840's internal USB regulator
  uses this, and firmware reads VBUS-present from it (no GPIO needed — `vbus_present()` in
  `main.c`).
- **Charger:** MCP73832-2-OT, 1-cell Li-ion. `PROG` resistor sets charge current (e.g. 2 kΩ ≈
  500 mA, 10 kΩ ≈ 100 mA — match the battery). Rev G places Q6 in R3's return so the actuator-enable interlock can float PROG and suspend charging. `STAT` → CHG_STAT (P0.17) + a charge LED.
- **Power-path:** Q1 AO3401A **drain (3) → BAT_PROT, source (2) → VSYS**;
  its body diode conducts BAT_PROT toward VSYS and blocks VSYS-to-battery backfeed.
  Gate (1) → R4 100k → GND, and USB_VBUS → R5 1k → gate. D19 B5819W anode (2)
  → USB_VBUS, cathode (1) → VSYS. USB raises the gate and disconnects the battery
  from the load; R4 turns Q1 on when USB is absent.
- **Fuel gauge:** MAX17048 `VDD`(3) → BAT_PROT (it senses its own supply); `CELL`(2) → BAT_PROT per the ADI pin table (internally unconnected in MAX17048); `CTG`(1), `GND`(4), `EP`(9), `QSTRT`(6) → GND; `ALRT`(5) → FG_ALRT
  (P0.15) with pull-up. See the verified sources below.

## Rev G battery protection and actuators

BAT_RAW is local to the battery-protection sheet. J2 is now a Molex Micro-Fit
430450401, pins 1+2 positive and 3+4 GND. U13 TPS259461LRPWR has IN5 on
BAT_RAW and OUT6 on BAT_PROT. **All battery-fed functional branches** connect
to BAT_PROT: Q1 logic path, U3 charger, U4 gauge and the three actuator ports.
R52/R53 bias EN1 from BAT_RAW; OVLO2 and GND8 are grounded. FLT4 goes to
P1.00 as BAT_nFAULT; SPLYGD3 and ITIMER10 are intentionally NC. ILM9 sees
R56+R58=660Ω, setting 5.05A nominal; DVDT7 sees R60=100Ω then C48=100nF.
D24 has cathode at BAT_RAW and anode at BAT_PROT for charge recovery; it cannot
bypass protection in the battery-discharge direction. Normal charging returns
through U13's bidirectional on-state path. ACT_EN drives Q5/Q6 charger inhibit
only; individual 100k input pulldowns keep drivers off during reset.

J16/J17/J18 pin1 is BAT_PROT and pin2 is the low-side switched return. J19
pins1–4 are GND, SOL1_PWM_EXT, SOL2_PWM_EXT, BUZZ_PWM_EXT, **3.3V logic only**.
Target two simultaneous 2A strikes, ≤100ms initially, with a 4.3A total input
budget and calibrated lower PWM hold current. See [actuator and full-input
protection requirements](notchdeck-one/ACTUATORS.md). A protected ≥6A pack
handles raw-input and battery-lead shorts; no disposable fuse is used.

## USB-C (J1, HRO TYPE-C-31-M-12)

- `VBUS` (A4/A9/B4/B9) → USB_VBUS net.
- `CC1`, `CC2` → 5.1 kΩ each to GND (UFP/sink — device role).
- `D+` (A6/B6 tied) → USB_DP → E73 pad 31; `D−` (A7/B7 tied) → USB_DM → E73 pad 29.
- `SBU1/SBU2` → NC. `Shield` → GND (optionally via a 1 MΩ ∥ 4.7 nF / bead).
- **ESD:** add a low-cap TVS array on D+/D−/VBUS (e.g. USBLC6-2 / SRV05 class) near the
  connector. (U7 is populated.)

## I²C buses and independent handle inputs (Rev E)

- **TWIM0:** SDA=P0.26 (pad12), SCL=P0.06 (pad14), R9/R10 4.7k pull-ups. Button MCU target 0x20 shares this upstream bus.
  U9 TCA9543APWR at 0x70 isolates two AS5600 address-0x36 channels. A0/A1 are
  grounded, RESET follows nRESET with R39 10k pull-up; INT0/INT1 have 10k pull-ups
  and INT output is deliberately unconnected. C38 bypasses its 3V3 supply.
- **Channel 0:** POWER_MAG_SDA/SCL, R27/R28 4.7k pull-ups, J10 power/combined
  sensor. Onboard U5 connects through R37/R38 (0Ω0603). **Remove BOTH links before
  attaching an external AS5600 to J10.** U5 remains powered but isolated.
- **Channel 1:** BRAKE_MAG_SDA/SCL, R29/R30 4.7k pull-ups, J11 external brake sensor.
- **J10/J11:** pin1=3V3, pin2=GND, pin3=SDA, pin4=SCL. U10/U11 USBLC6-2SC6
  protect data lines; C39/C40 bypass the ports. Use 3.3V sensors with local
  decoupling, short internal harnesses (≤20cm target), 100kHz and verify rise times.
  Do not hot-plug or add harness pull-ups without recalculating bus loading.
- **U5:** VDD5V(1)+VDD3V3(2) to3V3, C11/C12 local decoupling, DIR(8) and GND(4)
  grounded, OUT(3)/PGO(5) deliberately NC. Diametric magnet above package center.
- **TWIM1:** MAX17048 U4 at 0x36, SDA=P0.12 (pad20), SCL=P0.07 (pad22).
  It remains physically independent of both magnetic handles.

Firmware enables only one U9 channel at a time (write 0x01 or 0x02), reads the
sensor, then deselects both (0x00). Never select 0x03: identical sensor addresses
would collide. A stuck downstream bus may still require reset or power cycling;
this is an internal harness interface, not an industrial long-cable link.

Rev E retains the Rev D Gray inputs on J5 (six pins) and J12 (five pins). Pin1=GND, then
S0 upward; the final pin is 3V3 and is left unwired in passive contact harnesses.
This consolidates seven Rev C connectors without changing any MCU assignments:

| Role | Connectors | Nets / GPIOs | Input circuits |
|---|---|---|---|
| Brake or combined | J5.2–J5.5, S0–S3 | LEVER_S0–S3; P0.03/P0.28/P0.04/P0.05 | R14–17 10k pull-ups, R18–21 1k series, C14–17 100nF |
| Power | J12.2–J12.4, S0–S2 | POWER_S0–S2; P0.29/P0.31/P0.30 | R31–33 10k pull-ups, R34–36 1k series, C41–43 100nF |

Use contacts rated for microloads around **3.3V / 0.33mA**. A high-current switch
may not reliably conduct such a small current. RC time constants are about1.1ms
on release and0.1ms on closure; firmware adds16ms stability filtering. Open=1,
closed=0. The new cam maps reserve all-open as invalid and **supersede the earlier
Rev B table**. See [handle guide](../docs/06-handle-interfaces.md) for every pattern,
calibration, profile selection and fault behavior. External cams/switches/sensor
boards and harnesses are separate from the main PCB assembly BOM.

## Programming / reset (see `../docs/05-firmware-update.md`)

- **Main SWD**: SWDIO(37), SWDCLK(39), nRESET(26/P0.18), +3V3, GND at
  J3 keyed 2×5 header and bare J4 TC2030 contacts; use only one probe connection.
- **RESET SW17** → nRESET (P0.18) to GND; 100nF on nRESET. Double-tap DFU
  requires a compatible bootloader, which is not integrated yet.
- **Panel SWD** is separate at bare J2 TC2030. No panel USB or I²C updater exists.
- USB-C UF2 mass-storage is the proposed main-board user-upgrade path; see
  [update status](../docs/05-firmware-update.md) before using build artifacts.

## Decoupling & misc

- Per-supply: 100 nF close to each VDD/VDDH pad; 1 µF + 4.7–10 µF bulk on +3V3.
- **On the button board**, RGB array D1–D16: VDD → USB_VBUS, GND → GND. It is **USB-powered only**.
  U8 SN74AHCT1G125DBVR: VCC→VBUS, /OE→GND, input→RGB_PWM (STM32 PA8), output→R11 330Ω→D1 DIN.
  DOUT chains to the next DIN; D16 DOUT is NC. R26 100k holds DIN low during MCU reset.
  C20 is the buffer bypass; C21–C36 are 100nF per LED. C13 is 1uF bulk (10V or higher).
  Firmware must hold DIN low without USB and cap brightness to the source-current budget.
- Reverser J9: pin 1→3V3, pin 2→external SPDT common, pin 3→GND. The switch is
  center-off. R23/R24 (100k each) bias common to 1.65V in neutral. R25 (1k) feeds
  REVERSER_AIN; C37 (100nF) filters at the ADC. Forward/reverse select 3.3V/0V.
- D17/R12 show 3V3 power; D18/R13 run from 3V3 to CHG_STAT (active-low). R22 100k
  pulls CHG_STAT up to 3V3. U3 must be the open-drain MCP73832 variant.
- LFXO note: P0.00/P0.01 are now intentionally NC; no crystal is populated. Keep internal RC LFCLK unless hardware and firmware are deliberately revised together.

## Support parts (now specified in PARTS.md)

The power-path P-FET (AO3401A) + Schottky (B5819W), USB ESD (USBLC6-2SC6), reset button, SWD
header, populated WS2812 level shifter (74AHCT1G125), and the pull-up/gate/decoupling passives are
all listed in [`PARTS.md`](PARTS.md), with exact catalog codes and footprints.
Some parts use project-local symbols/footprints and lack dedicated 3D models;
see [attributions](lib/ATTRIBUTIONS.md). Stock observations are dated in the BOM files.

## Verified capture references (2026-10-02)

- [Microchip AN1149](https://ww1.microchip.com/downloads/en/AppNotes/01149c.pdf),
  load-sharing PMOS and Schottky topology.
- [Microchip MCP73831/2 datasheet](https://ww1.microchip.com/downloads/en/DeviceDoc/20001984g.pdf),
  STAT behavior: MCP73831 drives high at charge completion; MCP73832 releases its open drain.
- [ADI MAX17048/49 datasheet](https://www.analog.com/media/en/technical-documentation/data-sheets/max17048-max17049.pdf),
  pin table: CELL and VDD to the positive battery terminal; CTG/QSTRT/EP to ground.
- [TI SN74AHCT1G125](https://www.ti.com/lit/ds/symlink/sn74ahct1g125.pdf),
  4.5–5.5V supply and TTL-compatible input threshold.
- [ams AS5600 datasheet](https://look.ams-osram.com/m/7059eac7531a86fd/original/AS5600-DS000365.pdf),
  3.3V supply mode and sensor pinout.

Run `make verify` from `hardware/` for a strict net and ERC check.
The expected endpoint sets live in `scripts/notchdeck-netcheck.py`, independently
of the wiring manifest. See `README.md` for remaining pre-fabrication checks.

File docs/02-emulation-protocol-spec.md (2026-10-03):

# Emulation Protocol Spec — NotchDeck

Defines the on-wire HID contract our device presents over **both** transports. Design goals:

1. **Driverless** standard HID joystick on Windows / macOS / Linux / Android / iOS.
2. **One report descriptor** shared by USB and BLE; only framing differs (report-ID prefix).
3. **Lever = one 8-bit axis** carrying discrete notch bytes — bit-compatible with the Zuiki/SDL
   convention (lever on **Y**), so existing tooling (BRMascon, SDL passthrough, sim native support)
   can map the same notch values. Actual host/game compatibility needs testing.
4. A clean **host→device output report** for LEDs / lamps / instrument data.

**Implementation status (Rev E):** input/output report layouts exist in firmware,
and six handle profiles compile. Dual handles use the same report with Y=power
and X=brake. Panel key/nav integration and most lighting behavior remain unfinished.
Feature report 3 is declared in the descriptor but has no implemented handlers;
its layout below is reserved. See [firmware status](../firmware/README.md).

## 0. Identity

| Field | USB | BLE |
|---|---|---|
| Vendor/Product ID | **allocate our own** — e.g. [pid.codes](https://pid.codes) test VID `0x1209` + a sub-PID, or a real assigned VID. **Never** ship Zuiki's `0x33DD`. | n/a (GATT) |
| Product string | `NotchDeck One` | same, as GAP Device Name |
| Appearance | — | `0x03C4` (Gamepad) |
| HID version | `bcdHID 0x0111` | HID Information char |

> Compatibility note: if you *deliberately* want SDL's dedicated `SDL_HIDAPI_DriverZUIKI` to bind
> (rather than generic HID parsing), you must advertise `0x33DD/0x0006` *and* match the USB
> "old state packet" offsets exactly (no report ID). We **do not** do this by default — generic HID
> parsing uses our own descriptor. No Zuiki-identity compatibility profile is
> implemented; shipping IDs must be allocated to this project.

## 1. Unified HID Report Descriptor

One Application Collection (Joystick). **Input = Report ID 1**, **LED/lamp Output = Report ID 2**,
optional **instrument Feature = Report ID 3**.

```c
static const uint8_t HID_REPORT_DESCRIPTOR[] = {
    0x05, 0x01,        // Usage Page (Generic Desktop)
    0x09, 0x04,        // Usage (Joystick)
    0xA1, 0x01,        // Collection (Application)

    // ---------- INPUT REPORT (ID 1) ----------
    0x85, 0x01,        //   Report ID (1)

    // 16 buttons
    0x05, 0x09,        //   Usage Page (Button)
    0x19, 0x01,        //   Usage Minimum (Button 1)
    0x29, 0x10,        //   Usage Maximum (Button 16)
    0x15, 0x00,        //   Logical Minimum (0)
    0x25, 0x01,        //   Logical Maximum (1)
    0x75, 0x01,        //   Report Size (1)
    0x95, 0x10,        //   Report Count (16)
    0x81, 0x02,        //   Input (Data,Var,Abs)            -> 2 bytes

    // Hat switch (4-bit) + 4-bit padding
    0x05, 0x01,        //   Usage Page (Generic Desktop)
    0x09, 0x39,        //   Usage (Hat switch)
    0x15, 0x00,        //   Logical Minimum (0)
    0x25, 0x07,        //   Logical Maximum (7)
    0x35, 0x00,        //   Physical Minimum (0)
    0x46, 0x3B, 0x01,  //   Physical Maximum (315)
    0x65, 0x14,        //   Unit (Eng Rot: Degrees)
    0x75, 0x04,        //   Report Size (4)
    0x95, 0x01,        //   Report Count (1)
    0x81, 0x42,        //   Input (Data,Var,Abs,Null)       -> 0.5 byte
    0x65, 0x00,        //   Unit (None)
    0x75, 0x04,        //   Report Size (4)
    0x95, 0x01,        //   Report Count (1)
    0x81, 0x03,        //   Input (Const,Var,Abs) padding   -> 0.5 byte

    // 4 axes: X, Y(=lever), Z, Rz  each 0..255
    0x05, 0x01,        //   Usage Page (Generic Desktop)
    0x09, 0x30,        //   Usage (X)
    0x09, 0x31,        //   Usage (Y)        <-- POWER/BRAKE LEVER (notch axis)
    0x09, 0x32,        //   Usage (Z)        <-- reserved (reverser, optional)
    0x09, 0x35,        //   Usage (Rz)       <-- reserved (aux dial, optional)
    0x15, 0x00,        //   Logical Minimum (0)
    0x26, 0xFF, 0x00,  //   Logical Maximum (255)
    0x75, 0x08,        //   Report Size (8)
    0x95, 0x04,        //   Report Count (4)
    0x81, 0x02,        //   Input (Data,Var,Abs)            -> 4 bytes

    // ---------- OUTPUT REPORT (ID 2): LEDs / lamps ----------
    0x85, 0x02,        //   Report ID (2)
    // 8 standard indicator bits (notch/usage LEDs)
    0x05, 0x08,        //   Usage Page (LEDs)
    0x19, 0x01,        //   Usage Minimum (1)
    0x29, 0x08,        //   Usage Maximum (8)
    0x75, 0x01,        //   Report Size (1)
    0x95, 0x08,        //   Report Count (8)
    0x91, 0x02,        //   Output (Data,Var,Abs)           -> 1 byte
    // Vendor block: RGB status (R,G,B) + master brightness + speed + flags + warn
    0x06, 0x00, 0xFF,  //   Usage Page (Vendor-Defined 0xFF00)
    0x09, 0x01,        //   Usage (vendor)
    0x15, 0x00,        //   Logical Minimum (0)
    0x26, 0xFF, 0x00,  //   Logical Maximum (255)
    0x75, 0x08,        //   Report Size (8)
    0x95, 0x06,        //   Report Count (6)
    0x91, 0x02,        //   Output (Data,Var,Abs)           -> 6 bytes

    // ---------- FEATURE REPORT (ID 3): instrument / config (optional) ----------
    0x85, 0x03,        //   Report ID (3)
    0x06, 0x00, 0xFF,  //   Usage Page (Vendor-Defined)
    0x09, 0x02,        //   Usage (vendor)
    0x75, 0x08,        //   Report Size (8)
    0x95, 0x07,        //   Report Count (7)
    0xB1, 0x02,        //   Feature (Data,Var,Abs)          -> 7 bytes

    0xC0               // End Collection
};
```

## 2. INPUT report (device → host), Report ID 1

**7 payload bytes.** Offsets shown two ways because the report-ID prefix differs by transport.

| Payload byte / BLE value offset | USB report offset (including ID) | Field | Notes |
|---|---|---|---|
| 0 | byte 1 | Buttons 1–8 | bit0=B1 … bit7=B8 |
| 1 | byte 2 | Buttons 9–16 | |
| 2 | byte 3 | Hat (low nibble) + pad | `0..7` = N,NE,E,SE,S,SW,W,NW; `0x0F`/`8` = centered (null) |
| 3 | byte 4 | **X** axis | combined: center `0x80`; dual: brake `0..255` |
| **4** | byte 5 | **Y axis** | combined: discrete notch bytes (§4); dual: power `0..255` |
| 5 | byte 6 | **Z** axis | reserved: reverser (3-pos) or center `0x80` |
| 6 | byte 7 | **Rz** axis | reserved: aux dial or center `0x80` |

The current USB implementation prefixes the seven-byte payload with report ID 1.
BLE HIDS identifies it through the Report Reference and sends the seven-byte
payload without that prefix. Payload offsets remain identical. This is not the
Zuiki USB packet without report IDs; its notch values inform our encoding.

## 3. Button & hat map

Mirror the SDL/Zuiki gamepad-button assignment so existing remappers line up, then extend.

| Button | Suggested cab function | Maps to (gamepad sense) |
|---|---|---|
| 1 | Confirm / Horn-high | South (A) |
| 2 | Horn-low / Bell | East (B) |
| 3 | Door close | West (X) |
| 4 | Door open | North (Y) |
| 5 | ATS / ATC reset | L-shoulder |
| 6 | Cab / view | R-shoulder |
| 7 | Select | Back |
| 8 | Start / Pause | Start |
| 9–16 | Pantograph, headlight, sander, wiper, etc. | extension |
| Hat | Menu / camera / lookaround | D-pad |

Buttons are momentary (1=pressed). The host (or an adapter like BRMascon) decides whether to treat
them as held or as edge-triggered taps.

Rev E physically provides panel keys BTN1–BTN12 plus Up/Down/Left/Right; the last
four feed the hat once panel integration is implemented. Main Select/Start must
be ORed with panel buttons 7/8. HID button slots 13–16 remain available for future
inputs; the descriptor capacity is not a count of dedicated button switches.

## 4. Notch-lever axis encoding (Y axis) — **canonical**

Combined mode adopts the Zuiki ZKNS-001 notch values. This alone does not establish
drop-in compatibility with host software. **Snap directly between values — emit
no transition bytes.** The implemented Gray backend uses 16ms stable-state debounce;
magnetic sensing uses calibrated centers and hysteresis.

| Notch | Y byte | Normalized (host, [−1,+1]) |
|---|---|---|
| Emergency (EB) | `0x00` | −1.00 |
| B8 | `0x05` | −0.96 |
| B7 | `0x13` | −0.85 |
| B6 | `0x20` | −0.75 |
| B5 | `0x2E` | −0.64 |
| B4 | `0x3C` | −0.53 |
| B3 | `0x49` | −0.43 |
| B2 | `0x57` | −0.32 |
| B1 | `0x65` | −0.21 |
| **Neutral (N)** | `0x80` | 0.00 |
| P1 | `0x9F` | +0.24 |
| P2 | `0xB7` | +0.43 |
| P3 | `0xCE` | +0.61 |
| P4 | `0xE6` | +0.80 |
| P5 | `0xFF` | +1.00 |

Notes:
- 15 positions = EB + B8…B1 + N + P1…P5. Runtime notch-count selection is not
  implemented; current profiles use the documented P5/B8 baseline.
- Center: hardware-native neutral is `0x80`; the SDL driver centers at `0x7f`. The 1-LSB difference
  is cosmetic. **Pick `0x80` for neutral** (matches Zuiki docs); hosts that recenter at `0x7f` will
  read neutral as ≈+0.004, negligible.
- **Implemented dual mode:** Y=power Off…P5 and X=brake Release…EB, each scaled
  `0..255`, with brake suppressing power. There are no DGC-255 transition markers
  or runtime profile selector. Build-time `CONFIG_NOTCHDECK_SPLIT_AXES=n` selects
  combined Y encoding. See [handle profiles](06-handle-interfaces.md#firmware-profiles-and-output).

## 5. OUTPUT report (host → device), Report ID 2 — LEDs / lamps

The table defines intended behavior. Transport reception and partial brightness/
ownership logic exist; status overrides, speed/indicator rendering and host timeout
remain TODO. Rev E also needs the I²C panel backend and enforced current limits.

7 payload bytes. This is how a simulator drives our lights (the same role Zuiki's repurposed
"rumble/effect" packet plays — the sim writes an output report; over BLE the host writes the HID
Output Report characteristic; over USB it's a SET_REPORT / interrupt-OUT).

| Payload byte | Field | Meaning |
|---|---|---|
| 0 | Indicator bits | bit0 ATS lamp · bit1 door-open lamp · bit2 EB/buzzer lamp · bit3 overspeed · bit4–7 spare |
| 1 | Status R | RGB status LED red 0–255 (overrides local state color while non-zero, see §7) |
| 2 | Status G | green |
| 3 | Status B | blue |
| 4 | Master brightness | global LED brightness 0–255 (host can dim) |
| 5 | Speed | current train speed, scaled 0–255 → 0–`SPEED_FULL` km/h, drives meter/bargraph |
| 6 | Flags | bit0 notch-bar follow-host · bit1 sleep LEDs · bit2 demo · bit3–7 spare |

If the host never sends an output report, the device runs its **local default** lighting (notch bar
follows the lever, status LED shows connection/battery). Host writes take priority while present and
fall back to local defaults after a timeout.

## 6. FEATURE report (Report ID 3) — config / instrument (optional)

Bidirectional GET/SET for things that aren't per-frame: notch-count profile select, brightness
limits, calibration, firmware/protocol version, display page select. 7 bytes, vendor-defined; layout
TBD as features land.

## 7. Lights & LEDs we can offer

These are proposed behaviors, not completed features. Rev E has a 16-pixel panel
chain; there is no separate display, buzzer or warning-lamp assembly selected.

1. **Notch position indicator** — a linear bar (addressable WS2812B strip, or discrete/charlieplexed
   LEDs) mirroring the lever: brake notches one color (e.g. amber→red toward EB), power another
   (green), neutral a single center pip. Local by default; host can take it over (`flags bit0`).
2. **RGB status LED** — connection/power state: USB-attached = steady cyan; BLE advertising = slow
   blue blink; BLE connected = green; pairing = white blink; battery low = amber; charging = pulsing.
   Host can override color (bytes 1–3) for in-sim signalling.
3. **Instrument / speed display** — host pushes `speed` (byte 5) to drive an LED ring/bargraph
   "speedometer," or (MasconPro-style) a small **SPI OLED/TFT** showing speed + current notch. The
   display is fed by the output (or feature) report; no extra USB/BLE plumbing.
4. **Warning lamps** — discrete ATS/ATC, door-open, EB, overspeed lamps from §5 byte 0 indicator bits
   (plus an optional piezo for the ATS/EB buzzer).
5. **Backlight** — lever scale / button legends, brightness from byte 4.

**Rev E power behavior:** the panel RGB supply is USB-only; keys remain powered
on battery. Firmware must keep RGB output low without VBUS and enforce the panel
return-current target (≤250mA) within the total USB/charger budget. A host brightness
request must not override that limit. See power budget in
[`03-hardware-and-firmware-architecture.md`](03-hardware-and-firmware-architecture.md).

## 8. Report size summary (on the wire)

| Report | ID | Dir | Payload | +ID = total |
|---|---|---|---|---|
| Joystick state | 1 | IN | 7 B | 8 B |
| LED/lamp | 2 | OUT | 7 B | 8 B |
| Config/instrument | 3 | FEATURE | 7 B | 8 B |

The +ID column is the USB report length; BLE input/output characteristic values
carry the seven-byte payload. Feature report 3 remains reserved and unimplemented.

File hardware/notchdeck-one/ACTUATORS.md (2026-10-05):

# Battery protection and impulse outputs — Rev G

Two solenoid outputs target **2A strikes per channel, simultaneously**, followed
by a calibrated lower PWM hold current. This is a schematic and unrouted
floorplan, not a qualified 2A driver or working actuator firmware. No coils,
buzzer or battery pack have been selected. Keep loads disconnected until the
firmware and bench qualification below are complete.

## Full battery input protection

```text
protected 1S pack → J2 / BAT_RAW → U13 → BAT_PROT → Q1 / logic supply
                                          ├────→ fuel gauge
                                          └────→ J16/J17/J18 → loads → Q2/Q3/Q4 → GND
USB → MCP73832 charger ─────────────────────────→ BAT_PROT
                           charging returns through U13 to the battery
BAT_PROT → D24 (anode to cathode) → BAT_RAW: charge recovery while U13 is off
```

U13 is **TPS259461LRPWR / C3662776**, a bidirectional eFuse with a latched
thermal shutdown. **Every battery-fed functional branch is downstream of it**,
including logic, gauge and actuators. Only the input bypass C47, enable divider
and D24 cathode connect to BAT_RAW. D24 is reverse-biased during battery
discharge, so it cannot bypass the battery short protection. No disposable fuse
is fitted. USB VBUS is a separate source and is not protected by U13.

R56+R58 = **330Ω+330Ω = 660Ω** sets `3334/660 = 5.05A` nominal forward
current limit. The estimated range is **4.50–5.61A**, using ±10% IC accuracy and
1% resistors. Normal battery input demand must stay **≤4.3A**: two 2A strikes,
100mA buzzer and 200mA logic/panel/sensor allowance. This is a budget to measure,
not an instantaneous hard ceiling. U13's continuous operating rating is 5.5A;
its fast short threshold is about twice the set limit and brief overshoot is
possible before limiting. Leave ITIMER open for the fastest overcurrent response.

A severe short first triggers fast turn-off, followed by a current-limited
attempt after approximately 30µs. A persistent fault heats the eFuse until it
**latches off thermally**; it does not latch immediately at 5.05A. FLT asserts
for persistent forward overcurrent and thermal faults. Remove the fault, then
disconnect **both battery and USB** to reset the latch. There is no automatic
MCU power-cycling path. R52/R53 bias EN from the raw battery independently of
the MCU, avoiding a startup deadlock. OVLO is grounded; this circuit does not
provide reverse-battery protection or a separate adjustable overvoltage cutoff.

Use a **protected 1S pack rated for at least 6A discharge**, with a protection
cutoff and harness compatible with this load. Pack protection remains essential
for shorts in its leads, J2 and the short raw-input section before U13. Neither
the MCP73832 charger nor MAX17048 gauge supplies cell protection. Require a
usable protected-pack output ≥2.7V; actuator operation has a higher provisional
loaded-battery cutoff of 3.6V.

C47 is 1µF input bypass. C48=100nF with R60=100Ω follows TI's recommendation
for a DVDT capacitor above 10nF; nominal rise time is **210ms at 4.2V**. C45/C46
provide 44µF nominal bulk, reduced by voltage bias. D23 clamps negative output
excursions. The output capacitors can still discharge briefly into a short.
Keep battery leads short (≤10cm target) and qualify input overshoot and output
undershoot with the actual pack and harness.

## Charging and control

The eFuse conducts in both directions when enabled; its overcurrent protection
acts only from IN to OUT. MCP73832 limits charging current nominally to 500mA.
D24, a B360A Schottky, permits limited charging of a depleted/disabled pack until
U13 can turn on. It also means USB can back-power BAT_RAW while the eFuse is off.
Do not treat a latched eFuse as full electrical isolation with USB attached.

**ACT_EN now inhibits charging only. It does not switch U13 or remove voltage
from the actuator connectors.** Q5 pulls CHARGE_ENABLE low, Q6 opens the charger
PROG resistor return, and charging pauses. With ACT_EN low, R59 biases Q6 on
for normal charging. R46–48 hold the individual driver inputs off during reset.
Use ACT_EN for an entire actuation session, not as PWM. Check PROG leakage and
the actual charge current through Q6 on the bench.

Firmware must initialize PWM low, validate the battery and load profile, assert
ACT_EN, allow charging to stop, then permit strikes/hold. On BAT_nFAULT, stop all
PWM and **keep ACT_EN high to inhibit USB charging into the fault**; require an
explicit user reset. On battery-only faults the MCU may lose power, so firmware
cannot replace U13's hardware limiting/latch behavior. J19 follows raw MCU PWM.

The charger and MAX17048 connect to BAT_PROT. The eFuse drop slightly reduces
actual cell charging voltage and biases loaded gauge voltage; take rested
readings for calibration rather than interpreting a strike sag as cell SOC.

## Ports and GPIOs

| Port | Pins | Intended load |
|---|---|---|
| J2 | **1+2 BAT_RAW, 3+4 GND** | Owned Molex **430450401 / C585880** Micro-Fit 3.0, both contacts wired per polarity |
| J16 | 1 BAT_PROT, 2 SOL1_LOW | 1S solenoid 1, 2A strike target |
| J17 | 1 BAT_PROT, 2 SOL2_LOW | 1S solenoid 2, 2A strike target |
| J18 | 1 BAT_PROT, 2 BUZZ_LOW | 1S-rated active buzzer, ≤100mA |
| J19 | 1 GND, 2 SOL1_PWM_EXT, 3 SOL2_PWM_EXT, 4 BUZZ_PWM_EXT | High-impedance 3.3V inputs for a separate driver |

J2 uses the standard 43045-0400 footprint, compatible with the selected -0401
contact finish. Use the matching 43025-series four-circuit receptacle and
appropriate 20AWG crimp contacts; fit both positive and both return wires.
Mating parts remain a harness sourcing item. J16–18 remain JST PH C295747;
2A is the PH contact rating with 24AWG wire, so do not exceed it. J19 is JST PH
C265102. The larger battery connector prevents confusing it with a load port.

| E73 pad / GPIO | Signal | Circuit |
|---|---|---|
| 32 / P0.20 | SOL1_PWM | R43 330Ω → Q2 IN; R46 100kΩ to ground |
| 33 / P0.13 | SOL2_PWM | R44 330Ω → Q3 IN; R47 100kΩ to ground |
| 34 / P0.22 | BUZZ_PWM | R45 330Ω → Q4 IN; R48 100kΩ to ground |
| 35 / P0.24 | ACT_EN | R54 → Q5/Q6 charger inhibit; no connection to U13 EN |
| 36 / P1.00 | BAT_nFAULT | U13 FLT4, open drain; R57 10kΩ pull-up to 3V3 |

J19 branches through R49–51, 1kΩ each. A 12V booster/driver needs its own
supply protection, current control, flyback and default-off inputs. Use common
ground; no 5V/12V pull-ups or 12V on J16–19. These are short internal harnesses,
not qualified hot-plug ports.

## Provisional strike and hold profile

Q2–4 remain owned **ZXMS6005DGTA / C174045**: IN1, drain2/tab, source3. The
3V-input specification includes a 2.2A minimum internal limiting threshold and
250mΩ maximum RDS(on) at 1A/25°C. Its published 5A pulsed absolute maximum at
3.3V is not a continuous rating. A 2A pulse suggests approximately 1W conduction
loss using 250mΩ; resistance increases with temperature and the 1A test point
is not a guarantee of that loss at 2A. Thermal/SOA qualification is required.

Initial bench profile: **2A peak target, ≤100ms strike, no more than one full
100ms strike per second per channel**, then hold at **≤0.7A average and ≤1A RMS**
per coil. Apply the repetition limit to sliding one-second windows. Start at a
shorter pulse and increase only as measurements justify. These are provisional
limits, not implemented firmware settings. Two simultaneous strikes fit the
4.3A input budget; stagger them if battery sag or measured demand requires it.

Start hold PWM at **500Hz**. The FET's switching delays make 20kHz a poor default.
Duty cycle alone does not regulate current: select and measure each coil at
maximum battery voltage/cold resistance, calibrate strike and hold profiles,
and include flyback-current decay. There is no per-channel current sensor.
Enforce pulse duration, RMS/average hold budgets, maximum session duration,
watchdog, communication timeout and fault shutdown. Confirm driver IN ≥3.0V
using suitable nRF GPIO drive strength and the loaded 3.6V actuation cutoff.

D20–22 are B360A flyback diodes, cathodes on BAT_PROT and anodes on switched
returns. Measure release time; a simple freewheel diode slows mechanical release.
Q4 drives an active buzzer on/off, not an unspecified passive audio transducer.

## Layout and validation

Reserve substantial drain-tab copper for Q2/Q3; the datasheet's 1.4A continuous
rating at 3V/25°C assumes 15×15mm of 1oz copper and derates with temperature.
Use short flyback loops and battery returns away from sensor/radio paths.
The provisional Battery net class uses 2mm tracks and Actuator branches use 1mm;
route planes/pours and verify temperature rise and fault capacity before fab.

U13 uses project-authored **TI_RPW0010A**, transcribed from TI's 4225183/A
land/stencil drawings. Pins 5/6 are the long IN/OUT power bars; **there is no
central ground EP**. Do not put ground vias through those bars. Corner lands
use joined pad sections. Final paste, rotation and thermal copper need assembler
review. J2's 3mm grid, 1.02mm signal drills and 3mm locating hole match Molex's
SD-43045-001 drawing; -0400/-0401 differ in finish.

KiCad 10.0.6: **zero ERC errors/warnings**, independent contract for **130
components, 94 nets, 409 endpoints and 22 intentional NCs**. PCB nets, UUID paths
and BOM fields agree. Native DRC has **zero rule/parity issues and 323 unrouted
connections**. These are consistency checks, not measured electrical performance.
The schematic/PCB analyzers and EMC screen were rerun. Remaining layout findings
include no ground planes/stitching, USB bypass placement, fiducials and test
access. The schematic analyzer reports missing U5 pull-ups across R37/R38 and
split 3V3 rails; the independent KiCad netlist verifies those 0Ω links and the
single sourced global 3V3 net. These analyzer findings are not additional ERC
failures. Manufacturer pin/land checks above are manual, datasheet-backed;
current/pulse/thermal limits remain engineering estimates pending measurement.

Qualification still includes startup/running shorts at battery extremes, USB
insertion, charging recovery/interlock, latch reset, temperature, coil release,
and EMC. No SPICE simulator or coil R/L model is available locally.

Sources: [TI TPS25946, sections 8.3/9 and RPW drawings](https://www.ti.com/lit/ds/symlink/tps25946.pdf),
[Diodes ZXMS6005DG](https://www.diodes.com/datasheet/download/ZXMS6005DG.pdf),
[Microchip MCP73831/2](https://ww1.microchip.com/downloads/en/DeviceDoc/20001984g.pdf),
[Molex 43045 drawing](https://datasheet.lcsc.com/datasheet/pdf/b6e3df063c26f8567b294b4b1d02bfdf.pdf?productCode=C585880),
[JST PH rating](https://www.jst-mfg.com/product/pdf/eng/ePH.pdf).

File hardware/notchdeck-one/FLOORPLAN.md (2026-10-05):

# Logic board — Rev G floorplan

2026-10-04, KiCad 10.0.6. **Unrouted placement study**, 115×90mm from (50,50) to (165,140), four copper layers, provisional 1.6mm thickness. All parts are on top; four 3.2mm mounting holes are 5mm from the corners. There are 130 electrical footprints and four board-only holes.

The button matrix, RGB LEDs, AHCT buffer and their local passives moved to [notchdeck-buttons](../notchdeck-buttons/FLOORPLAN.md). Main SW18 Select at (130,104) and SW19 Start at (147,104) retain direct BTN7/BTN8 inputs; SW17 remains Reset. J15 FFC at (135,54.2), facing the top, connects the button MCU; U12/C44 protect and bypass its I²C/3V3 port. R42 pulls IRQ up.

USB and power remain upper left. E73 is at (93,66), rotated 90°, antenna overhanging the top edge by about 2mm. The all-layer rule area at x81…105/y43…51.3 prohibits copper/pads/vias; enclosure-metal clearance and exact module footprint remain review items. Main SWD and Tag-Connect remain below the radio. J12 power Gray faces left at (55.8,115); J5 brake/mascon Gray faces right at (159.2,109). J10/J11 magnetic ports face down at (119,134.2)/(145,134.2); J9 reverser is at (79,134.2). U5 remains at (81,113), with both R37/R38 removable for an external J10 sensor. No shaft hole or validated magnet envelope is provided.

Rev G adds J16/J17 solenoid connectors on the right edge, J18 buzzer on top and J19 external 3.3V PWM on the left. Q2/Q3 sit near the solenoid ports with D20/D21 and C45/C46; Q4/D22 sit below the buzzer. U13 electronic current limiter, Q5/Q6 charger interlock, C47/C48 and R52–60 occupy the battery/SWD region. See [actuator limits, protection and routing requirements](ACTUATORS.md). J2 is replaced with a larger Micro-Fit at (60,79), facing left. C19 and the fuel-gauge cluster move to make room; D24 provides charging recovery and R60 is the DVDT series resistor. Other existing positions are retained.

Native checks: **zero ERC violations**, complete 409-endpoint/94-net contract including 22 intentional NCs, all schematic/PCB nets and UUID paths match, **zero DRC rule/parity issues and 323 unconnected items**. Sourcing fields, 129 assembly parts and bare J4 exclusion match. These checks do not verify routing, mechanical fit or electrical/thermal margins.

The saved PCB is editable in KiCad. `scripts/notchdeck-floorplan.py --project notchdeck-one` records the provisional seed geometry; `--replace-unrouted` is intentionally explicit and must not overwrite subsequent placement work. Do not use it once routing begins.

Before fabrication, resolve [hardware open work](../README.md#sourcing-and-remaining-work), exact E73/MAX17048 land patterns, magnet/handle mechanics, USB/current budget and local decoupling. Route uninterrupted reference planes, USB via its ESD array with short ground return, and keep RGB return current separate from sensor return paths. Add test access, fiducials and ground stitching as needed. Historical Rev B analyzer results are not a Rev G EMC/thermal/DFM approval.

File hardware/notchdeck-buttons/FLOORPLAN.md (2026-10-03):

# Button board — Rev E floorplan

**86×120mm**, two layers, provisional 1.6mm thickness; outline (50,50)…(136,170). All components are on top. Four 3.2mm NPTH holes at (55,55), (131,55), (131,165), (55,165) require enclosure boss/keycap clearance review. There are 85 electrical footprints plus four board-only holes. No tracks, vias or planes are present.

SW1–SW16 are a 4×4 grid on **19mm pitch**: x64.5/83.5/102.5/121.5 and y72/91/110/129. Each RGB LED is 7mm above its switch, with local 100nF. D1–D16 form a serpentine chain; LED ordering by row is `1 2 3 4 / 8 7 6 5 / 9 10 11 12 / 16 15 14 13`. Isolation diodes D20–D35 sit beside their switches. PCB spacing is provisional; keycaps and stems are not selected.

U1 STM32G030 is at (94,147), rotated 90°. Its decoupling, reset, column pull-ups and VBUS divider occupy the lower electronics strip. U8 AHCT at (118,151) drives RGB. J2 Tag-Connect at (66,154) needs unobstructed probe access. J1 six-way FFC at (93,165) faces the lower edge; U2 protects SDA/SCL. Route C1/VDD/GND as a short loop, keep LED return current out of the I²C/MCU reference path, and add ground fill/stitching after signal routing.

Native checks: **zero ERC violations**, 56 nets/235 endpoints/four intentional NCs, all schematic/PCB nets and UUIDs match, **zero DRC rule/parity violations and 211 unconnected items**. The assembly BOM/CPL has 84 parts; bare J2 is excluded. The independent panel audit checks every matrix diode, LED link and the Type A FFC reversal.

See [panel interface](README.md) for the exact cable, pinout, stock, ratings, tolerance caveat and firmware requirements. This is a floorplan, not a production release. Final enclosure/cable fit, current budget, firmware, component orientation and complete routing remain open.

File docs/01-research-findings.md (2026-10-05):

# Research Findings — Zuiki Mascon, MasconPro & the Densha de GO! lineage

Captured from a multi-source, adversarially-verified research pass (24/25 claims confirmed) plus a
direct read of the SDL driver source. This is the factual basis for our emulation spec in
[`02-emulation-protocol-spec.md`](02-emulation-protocol-spec.md).

This records research on commercial controllers, not verified NotchDeck host
support. For the current Rev G logic / Rev E panel design and implementation limits, start with the
[project README](../README.md) and [firmware guide](../firmware/README.md).

## TL;DR

- The Zuiki controllers are **plain USB HID joysticks** — *not* XInput, *not* Switch Pro Controller
  emulation, *not* a custom/vendor protocol. No driver required on Windows / macOS / Linux.
- The **power/brake lever is one 8-bit analog axis** with discrete per-notch byte values and **no
  transition values**. Everything else (buttons, hat) is conventional.
- USB VID/PID is **edition/mode-dependent** — a single unit may enumerate under more than one ID.
- The newer **MasconPro** got a **vendor-authored SDL driver** (`SDL_hidapi_zuiki.c`,
  `Copyright (C) 2025 Zuiki Inc.`) that exposes it on the *joystick* API — SDL maintainers
  explicitly declined to register it under the *gamepad* API ("this isn't a gamepad style
  controller").

## 1. Device class & USB IDs

| Device / edition | VID | PID | Notes |
|---|---|---|---|
| ZKNS-001, Densha de GO! edition | `0x0F0D` (HORI) | `0x00C1` | HORI = licensed Switch peripheral maker; product strings contain "for Nintendo Switch" |
| ZUIKI Switch edition / PC DInput mode | `0x33DD` (ZUIKI) | `0x0001` | |
| 1st Anniversary translucent | `0x33DD` | `0x0002` | |
| Mascon Red / Blue / Black | `0x33DD` | `0x0003` / `0x0004` / `0x0005` | |
| **MasconPro** | `0x33DD` | `0x0006` | wired USB, PC-focused, has an instrument-cluster screen |
| ZUIKI EVOTOP (PC/UWB/BT) | `0x33DD` | (EVOTOP PIDs) | a *conventional gamepad* w/ gyro+accel; the only **Bluetooth** Zuiki HID device |

The ZKNS-001 enumerates as **"HID-compliant joystick: 14 buttons, a hat switch, 4 axes."** On Windows
it is additionally a DirectInput controller (matched by ProductGuid prefix `000133dd` or product
name containing "mascon"). Older Switch variants appear in SDL's `controller_list.h` as
`k_eControllerType_SwitchInputOnlyController`.

> **Do not squat `0x33DD`** for our clone — that's Zuiki's vendor ID. We allocate our own (see spec).

## 2. The notch lever — single-axis encoding (ZKNS-001, native bytes)

Lever = HID **"Axis 2" = Switch left-stick Y (`SWITCH_LY`)**. The other three axes sit fixed at `0x80`.
**No transition values between notches** — it snaps directly to the next discrete value.

| Notch | Byte | | Notch | Byte |
|---|---|---|---|---|
| Emergency (EB) | `0x00` | | Neutral (N) | `0x80` |
| B8 | `0x05` | | P1 | `0x9F` |
| B7 | `0x13` | | P2 | `0xB7` |
| B6 | `0x20` | | P3 | `0xCE` |
| B5 | `0x2E` | | P4 | `0xE6` |
| B4 | `0x3C` | | P5 | `0xFF` |
| B3 | `0x49` | | | |
| B2 | `0x57` | | | |
| B1 | `0x65` | | | |

15 discrete positions (EB + B8..B1 + N + P1..P5). Software re-scales these raw bytes for its own use:
- **pygame**: floats on axis 1 — EB=−1.00, B1=−0.21, N=0.00, P1=+0.24, P5=+1.00
- **wesalvaro gist**: −100..+100 scale
- **BRMascon**: DirectInput 0–65535 thresholds — EB≈640, B8≈3072, N≈36668, P5=65535

⚠️ The 0–65535 / float / ±100 ranges are **software-side rescalings**. The native authoritative
values are the single bytes above. (A claim that the native values were *signed* — P5=−32768,
EB=+32767 — was **refuted** during verification; do not use it.)

## 3. The SDL MasconPro driver (`SDL_hidapi_zuiki.c`) — authoritative wire format

Vendor-contributed (`Copyright (C) 2025 Zuiki Inc.`). Key facts read directly from source:

- MasconPro → `HIDAPI_DriverZUIKI_HandleOldStatePacket`. **`joystick->nbuttons = 11`**, 1 hat, full
  axis set, **no sensors** (only the EVOTOP variants set `sensors_supported`).
- **The driver does NOT decode notches.** The lever is just read as a normal stick axis and
  forwarded; notch interpretation is left to the application.

**USB "old state packet" layout** (offsets are from the start of the report, *no* report-ID prefix):

| Byte | Meaning |
|---|---|
| `data[0]` | Button bitmask #1 — `0x01`=North `0x02`=East `0x04`=South `0x08`=West `0x10`=L-shoulder `0x20`=R-shoulder `0x40`=L-trigger(digital) `0x80`=R-trigger(digital) |
| `data[1]` | Button bitmask #2 — `0x01`=Back `0x02`=Start `0x04`=L-stick `0x08`=R-stick `0x10`=Guide `0x20`=Misc1 |
| `data[2]` | Hat / D-pad: `0..7` → 8 directions, else centered |
| `data[3]` | Left stick **X** |
| `data[4]` | Left stick **Y** ← **the power/brake lever** |
| `data[5]` | Right stick X |
| `data[6]` | Right stick Y |

Axis conversion macro (note the center is **`0x7f`** here, vs the `0x80` neutral in the ZKNS-001
docs — a 1-LSB discrepancy to be aware of):

```c
#define READ_STICK_AXIS(offset) \
    (data[offset] == 0x7f ? 0 : (Sint16)HIDAPI_RemapVal((float)((int)data[offset] - 0x7f), \
        -0x7f, 0xff - 0x7f, SDL_MIN_SINT16, SDL_MAX_SINT16))
```

**Effects / LEDs:** `SetJoystickLED` and sensors return `SDL_Unsupported()` for the MasconPro.
Rumble is an 8-byte packet, `rumble_packet[4]=low>>8, [5]=high>>8`, and `SendJoystickEffect`
forwards raw bytes via `SDL_HIDAPI_SendRumble`. This "repurpose the rumble/effect channel for raw
output packets (LED control)" path is the maintainer-blessed way to push data *to* the device.

**Bluetooth uses a DIFFERENT layout.** The same driver's `Handle_EVOTOP_PCBT_StatePacket` (for the
Bluetooth EVOTOP) shows the BT report is *not* byte-identical to USB: 16-bit little-endian axes at
`data[1..8]`, 10-bit analog triggers at `data[9..12]`, hat at `data[13]`, buttons at `data[14]/[15]`.
Two reasons: a report-ID/framing prefix shifts offsets, and they widened the payload. **Lesson for
us:** the *semantic* protocol transfers cleanly to BLE; exact byte offsets do not — budget for a
report-ID prefix.

## 4. Densha de GO! lineage (for context / optional compat modes)

- **DGC-255** one-handle USB PC controller (Taito `0x0AE4`/`0x0003`): HID joystick, 2 axes, 6 buttons,
  hat. Unlike the Zuiki it **splits brake and power onto two separate axes** and reports **`0xFF`
  during transitions** between notches. Brake axis: EB `0xB9` → B1 `0x8A`; power axis: N `0x81` →
  P5 `0x00`.
- **Classic console controllers** (N64/PS1/Saturn/Dreamcast): native per-console controller protocol,
  notches encoded as **multi-bit button combinations** — 3 bits power, 4 bits brake (Emergency = all
  brake bits released). Not an axis.
- **`ddgo-pnp-controller`** (Marc Riera, Rust): converts the Densha de GO! Plug & Play into a USB
  controller emulating many profiles (Switch one-handle, two-handle PC/PS1/N64/Saturn/Dreamcast/PS2,
  Shinkansen, Multi Train Controller). Shinkansen mode maps power to P2-P4-P7-P10-P13.

## 5. What consuming software does (why notch→axis matters)

- **BRMascon** (C#/.NET 9): reads the mascon over DirectInput (SharpDX), thresholds the Y-axis into
  notches, and emulates a **virtual Xbox 360 pad via ViGEmBus**, translating lever *motion* into
  trigger/bumper **taps** (games expect incremental presses, not absolute notch). Per-train profiles
  for 4–7 power-notch classes. ~100 ms tap-queue latency.
- **ZUIKI_to_JRE** (C#/WinForms, cracrayol): adapts the Switch mascon to *JR EAST Train Simulator*;
  INI-configurable bindings, notch-count profiles ("B1 mode" KiHa 54 vs "B6 mode"). **Now
  deprecated** — JRETS added native Zuiki support.

Common thread: hardware emits the lever as one discrete-byte axis; every consumer (a) thresholds it
back into named notches and (b) re-expresses it (incremental taps / configurable keys / passthrough).

## Sources

- Marc Riera — **Train Controller Database** & **ddgo-controller-docs** (canonical reverse-engineering reference):
  - https://traincontrollerdb.marcriera.cat/hardware/zkns001/
  - https://marcriera.github.io/ddgo-controller-docs/controllers/usb/zkns001/
  - https://marcriera.github.io/ddgo-controller-docs/controllers/usb/dgc255/
  - https://marcriera.github.io/ddgo-controller-docs/controllers/classic/tech/
- **SDL** MasconPro driver: PR https://github.com/libsdl-org/SDL/pull/13770 ·
  source https://github.com/libsdl-org/SDL/blob/main/src/joystick/hidapi/SDL_hidapi_zuiki.c
- GitHub: https://github.com/lmaodick1239/BRMascon · https://github.com/cracrayol/ZUIKI_to_JRE ·
  https://github.com/cracrayol/ConToJREts · https://github.com/marcriera/ddgo-pnp-controller
- Gist (SWITCH_LY mapping): https://gist.github.com/wesalvaro/a4a21fc3d1eebe58878b6516d9357245

## Open questions

- Exact HID report descriptor of the real MasconPro (its lever almost certainly uses the same
  single-byte Y-axis encoding, per the SDL passthrough, but not independently dumped).
- macOS IOKit / Game Controller framework enumeration quirks (inferred from HID-class, not tested).
- Full functional meaning of the 14 ZKNS-001 buttons (only "A = horn" confirmed).

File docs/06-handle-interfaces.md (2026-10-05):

# Magnetic and Gray-coded handles (Rev E/F)

The same PCB supports a combined 15-position mascon, or separate power and brake
handles. Each handle independently uses an AS5600 magnetic sensor or Gray-coded
contacts. Dual-handle ranges are power Off/P1–P5 and brake Release/B1–B8/EB.
Both types are absolute: there is no incremental position count to lose at startup.
Mechanical detents establish the feel and stable positions in either case.
See the [own-build Japanese-style handle plan](07-japanese-handle-build.md) for
mechanical arrangement, harness construction and provisional detent/cam targets.

## Connections

| Handle | Magnetic | Gray contacts |
|---|---|---|
| Power (dual) | J10, mux channel 0; onboard U5 is the default sensor | J12: pins2–4=S0–S2 |
| Brake (dual) | J11, mux channel 1; requires an external sensor board | J5: pins2–5=S0–S3 |
| Combined mascon | J10/U5, mux channel 0 | J5 as above |

J10/J11 are keyed four-pin JST PH: **1=3V3, 2=GND, 3=SDA, 4=SCL**. Use a 3.3V
AS5600 board with local decoupling and no additional pull-ups. This is a short
internal harness interface (≤20cm initial target), operated at 100kHz; measure bus
rise times and noise on the assembled wiring. Power off before changing cables.

**Remove both R37 and R38 before connecting an external power/combined sensor at
J10.** They isolate onboard U5; leaving either connected can interfere with that
bus. Only one AS5600 per mux channel is permitted. J11 has no onboard sensor.
Firmware selects channel 0 (0x01) or channel 1 (0x02) on the TCA9543A at 0x70,
reads status/raw angle at 0x36, then deselects both. The fuel gauge at 0x36 remains
on the independent I2C1 controller. Do not enable both mux channels simultaneously.

Rev E retains the Rev D connector per cam: **J12 power: 1=GND, 2–4=S0–S2, 5=3V3**;
**J5 brake/mascon: 1=GND, 2–5=S0–S3, 6=3V3**. Leave the supply cavity
empty for passive switch harnesses. These replace J5–J8/J12–J14 in Rev C; the
MCU pin map is unchanged. A closed switch pulls its bit low;
open is high. External 10k pull-ups, 1k series resistors and 100nF capacitors are
already populated. Select gold/microload contacts qualified at 3.3V and roughly
0.33mA, or revise the circuit for the selected switch's required current. Do not
assume a mains-rated contact works reliably at this load. Mount and adjust cams
so each detent has a stable code well away from its switching boundary.

## Gray patterns for our cams

These are **electrical voltage levels**, not closure masks: 1=open,0=closed.
Read S3…S0 or S2…S0 left to right. Adjacent detents change exactly one bit. These
are bounded cams with end stops; the last-to-first transition is not supported.
All-open is reserved so an unplugged harness does not decode as a valid notch.
The maps supersede the earlier Rev B table, which used all-open as P1.

| Power position | S2 S1 S0 | Brake position | S3 S2 S1 S0 |
|---|---|---|---|
| Off | 001 | Release | 0000 |
| P1 | 011 | B1 | 0001 |
| P2 | 010 | B2 | 0011 |
| P3 | 110 | B3 | 0010 |
| P4 | 100 | B4 | 0110 |
| P5 | 101 | B5 | 0111 |
| — | — | B6 | 0101 |
| — | — | B7 | 0100 |
| — | — | B8 | 1100 |
| — | — | EB | 1101 |

| Combined position | S3 S2 S1 S0 |
|---|---|
| EB | 1110 |
| B8 | 1010 |
| B7 | 1011 |
| B6 | 1001 |
| B5 | 1000 |
| B4 | 0000 |
| B3 | 0001 |
| B2 | 0011 |
| B1 | 0010 |
| N | 0110 |
| P1 | 0111 |
| P2 | 0101 |
| P3 | 0100 |
| P4 | 1100 |
| P5 | 1101 |

The power map's unused patterns are 000 and 111.
For brake, unused patterns are 1000,1001,1010,1011,1110,1111. Combined reserves1111.
A broken individual wire can still turn one valid code into another; this wiring
is not redundant fault detection. Gray coding reduces ambiguous transitions,
but software debouncing and correct cam geometry are still required.

## Magnetic calibration

Magnetic sensing avoids contact wear, but magnet alignment, gap and mechanical
movement still affect the measured angle. Use a diametrically magnetized magnet
centered on the shaft; check the AS5600 field-status flags throughout travel.

Measure raw 12-bit angles at every assembled detent and populate
[`handle_calibration.h`](../firmware/src/handle_calibration.h). Centers follow
logical order: combined EB through P5, power Off through P5, brake Release through
EB. Decreasing angles and a 4095→0 seam are supported. Set hysteresis in raw counts
(4096 counts per turn); adjacent centers must remain more than twice the hysteresis
apart. Validate margins under shaft load, vibration and temperature before choosing
that value. Do not use invented equally spaced centers for a real handle.

The supplied arrays intentionally have `count=0`: magnetic output stays faulted
until measured calibration is supplied. `lever_set_calibration()` also accepts
validated values for a future UI/persistence layer; no calibration UI or persistent
storage is implemented yet. Calls must be serialized with the report loop.

## Firmware profiles and output

From the repository root in an initialized NCS v3.3.0 workspace. This compiles
the Rev C/D handle configuration; it does not provide Rev E panel support:

```sh
west build --sysbuild -b nrf52840dk/nrf52840 firmware -d build-dual-gray -- \
  -DDTC_OVERLAY_FILE=boards/notchdeck_rev_c.overlay \
  '-DEXTRA_CONF_FILE=configs/rev_c.conf;configs/dual_gray.conf'
```

Replace the final profile with one of:

| Profile | Power/first | Brake |
|---|---|---|
| `combined_magnetic.conf` | Combined magnetic | unused |
| `combined_gray.conf` | Combined Gray | unused |
| `dual_magnetic.conf` | Magnetic | Magnetic |
| `dual_gray.conf` | Gray | Gray |
| `dual_mixed.conf` | Magnetic | Gray |
| `dual_gray_power.conf` | Gray | Magnetic |

The Rev C overlay also applies to Rev D (identical GPIO assignments). It replaces DK pin assignments, disables conflicting DK peripherals,
configures NFC pins as GPIO, reset in UICR and calibrated RC LFCLK. It still uses
the DK platform/flash layout for SDK bring-up, not a production board/bootloader.
The default build without that overlay remains the direct-I2C DK test setup.
Outputs for this example are `build-dual-gray/firmware/zephyr/zephyr.{uf2,hex}`.
Rev E retains these handle assignments, but frees the direct panel GPIOs and
requires new STM32 firmware, a main I²C backend and a matching overlay. See the
[firmware guide](../firmware/README.md) and [panel interface](../hardware/notchdeck-buttons/README.md).

Dual mode defaults to generic HID **Y=power (0…255)**, **X=brake (0…255)**.
Z remains reserved for the reverser. The seven-byte report layout is unchanged.
This is not a claim of exact DGC-255 emulation. Set
`CONFIG_NOTCHDECK_SPLIT_AXES=n` to use the existing combined Y-notch encoding,
with brake taking priority over power. Combined mode retains the original
EB=0x00/N=0x80/P5=0xFF mapping.

Gray samples must be stable for 16ms. Magnetic readings use nearest calibrated
centers with hysteresis; missing/weak/strong-field status is invalid. An invalid
sample holds the last accepted position for less than 100ms; on the next poll at
or beyond that limit, either failed handle produces power-off/emergency-brake
output and clears the arm state. I2C transfer timeouts can delay that poll.
Startup and fault recovery require both handles at neutral (or combined N) before
power is enabled. Any brake notch suppresses traction. Sensor type is explicit;
an unplugged sensor never causes automatic fallback to another backend.

## Verification and remaining work

`make -C firmware test` checks all cam patterns/adjacent transitions, angle wrap and
reversed travel, calibration rejection, hysteresis, debounce, uptime wrap, stale
input, brake priority and neutral re-arming. CI compiles all six profiles using the shared Rev C/D pin map.
Rev G logic / Rev E panel native checks cover both assemblies: logic 130 components/409 endpoints and
panel 85 components/235 endpoints, with 129 and 84 assembly placements respectively.
Both have zero ERC errors/warnings and no DRC rule or parity violations;
323 logic and 211 panel connections remain unrouted. See [hardware status](../hardware/README.md).

Before hardware use: build the cams or sensor carriers, measure/calibrate magnetic
handles, scope the harness signals, verify unplug/reconnect and startup behavior,
and test actual HID mappings. Nav/reverser scanning, RGB power limits, final
bootloader/USB IDs and the broader power/layout reviews remain open. External
sensor boards, magnets, microload switches, cams and mating harnesses are outside
the two PCB assembly BOMs and their five-set stock check.

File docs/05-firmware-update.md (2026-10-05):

# Firmware updates — implementation status and plan

**There is no production update flow yet.** CI emits UF2 and HEX files for the
nRF52840 DK bring-up application. The repository does not build a NotchDeck
bootloader, OTA package or STM32 panel image. Rev E/F needs two separately programmed
MCUs; the existing nRF direct-GPIO application does not operate its panel.

## Current build outputs

See the [firmware guide](../firmware/README.md) for NCS v3.3.0 workspace setup.
From the repository root:

```sh
make -C firmware build
make -C firmware uf2
make -C firmware release
```

| Output | Meaning |
|---|---|
| `firmware/build/firmware/zephyr/zephyr.uf2` | Application UF2 generated by NCS sysbuild with `CONFIG_BUILD_OUTPUT_UF2=y` |
| `firmware/build/firmware/zephyr/zephyr.hex` | Application HEX for the selected build target |
| `firmware/dist/notchdeck-one-vX.Y.Z.{uf2,hex}` | Versioned copies made by `make release` |
| CI `notchdeck-one-firmware` | Default DK build, named `notchdeck-one.uf2` and `.hex`; not a Rev E release |

`VERSION` controls Zephyr's application version and the release filenames.
The BLE DIS revision in `prj.conf` is maintained separately. No target currently
signs images, creates an OTA ZIP or bundles a bootloader. A valid UF2 container
does not establish that its flash addresses match a future production bootloader.

## Main-board user-update plan

The proposed primary experience is USB drag-and-drop: enter a UF2 bootloader,
mount a drive, copy the matching application image, then reboot. An Adafruit
nRF52 bootloader port is a candidate; MCUboot with a suitable update transport
is another option if signed images/recovery slots are required. Neither is
integrated or validated for this board.

The current `dfu.c` writes GPREGRET `0x57` and resets, and `main.c` checks the
Select+Start mask at startup. That is only an entry request for a compatible
bootloader. Double-tap Reset behavior belongs to the bootloader. Rev E must first
implement and verify its local/panel button mapping; an ordinary DK application
build does not create a `NOTCHDECK` USB drive.

Before documenting a user procedure, choose and test the bootloader, board port,
flash partitions/application address, reset behavior and USB identity. Verify a
complete SWD installation, repeated updates, interrupted updates and recovery.
Choose signing and authorization behavior for each enabled update transport.
UF2 is a container format, not itself an authentication policy. BLE OTA remains
future work; HOGP support alone does not provide it.

## Programming access on both boards

| MCU | Access | Signals |
|---|---|---|
| Logic E73 nRF52840 | J3 keyed 10-pin SWD header or bare J4 TC2030 | SWDIO E73 pad37, SWDCLK pad39, reset pad26/P0.18, 3V3 reference, GND |
| Panel STM32G030 | Bare J2 TC2030 | 1=3V3, 2=SWDIO, 3=NRST, 4=SWCLK, 5=GND, 6=NC |

Use one main-board debug connection at a time, observe pin 1 and the target's
3.3V reference, and establish the power/probe setup before flashing. The nRF
requires P0.18 reset configured in UICR and RC LFCLK with the current hardware.
The STM32 must retain SWD and the correct user-flash boot option bytes; see the
[panel pin plan](../hardware/notchdeck-buttons/README.md#mcu-pin-plan).

SWD is the planned development, factory programming and recovery interface.
Recovery depends on the device protection/configuration state and may require
an erase. The panel has no USB connector and no implemented I²C bootloader.
A future coordinated update feature must define panel image compatibility and
recovery before assuming the main USB update also updates the panel.

The [net plan](../hardware/NETPLAN.md) records captured programming/reset wiring.
Both boards remain unrouted; bootloader behavior and hardware access still need
validation on assembled boards.

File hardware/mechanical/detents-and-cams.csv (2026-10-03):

handle | position | provisional_angle_deg | levels_msb_first | switches_closed_to_ground | header | header_pins_connected_to_pin1
power | Off | 0 | 001 | S1 S2 | J12 | 3 4
power | P1 | 10 | 011 | S2 | J12 | 4
power | P2 | 20 | 010 | S0 S2 | J12 | 2 4
power | P3 | 30 | 110 | S0 | J12 | 2
power | P4 | 40 | 100 | S0 S1 | J12 | 2 3
power | P5 | 50 | 101 | S1 | J12 | 3
brake | Release | 0 | 0000 | S0 S1 S2 S3 | J5 | 2 3 4 5
brake | B1 | 12 | 0001 | S1 S2 S3 | J5 | 3 4 5
brake | B2 | 24 | 0011 | S2 S3 | J5 | 4 5
brake | B3 | 36 | 0010 | S0 S2 S3 | J5 | 2 4 5
brake | B4 | 48 | 0110 | S0 S3 | J5 | 2 5
brake | B5 | 60 | 0111 | S3 | J5 | 5
brake | B6 | 72 | 0101 | S1 S3 | J5 | 3 5
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

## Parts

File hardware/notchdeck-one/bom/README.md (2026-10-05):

# notchdeck-one — Rev G sourcing

The logic/actuator board has **129 installed components across 39 JLCPCB codes**.
The [native BOM](jlcpcb-bom.csv), [tracking BOM](bom.csv), [selection JSON](jlcpcb-parts.json)
and [stock observations](jlcpcb-stock.csv) describe the captured schematic. The
JSON drives each symbol's MPN, manufacturer, LCSC code, datasheet and notes.

Use the [combined five-set report](../../jlcpcb-five-set-stock.csv) to avoid
counting shared parts independently on each board. A complete set contains
213 assembly components and 44 JLCPCB codes. Private balances remain in the
shared CSV outside Git. The user placed the earlier Rev E order; Rev G adds
parts that were not included in that order.

The 2026-10-04 PDT JLCPCB checks show 110 C3662776 TPS259461LRPWR
protectors in stock; exact order allocation was not checked. Earlier live checks
show 1,716 orderable C174045 FETs, 17,404 C295747 two-pin connectors and
18,511 C265102 four-pin connectors. J2 uses owned C585880 Micro-Fit stock;
R60 uses C22775; its existing stock is reserved for Tenkiro, so buy 100 for a sensible passive price break. Older rows retain their observation dates. Catalog
category/price snapshots are estimates, not live quotes.

For 20 sets plus 10% spares, the top-up is **36 FETs, 22 C3662776 protectors,
44 C295747 two-pin and 16 C265102 four-pin connectors**. The previous C2155674
protector is no longer selected. C22775 also needs 22 pieces (recommend buying 100); the existing stock is reserved. Other additions fit recorded owned stock after
Tenkiro's allocation. See the local
`~/Dropbox-elec/github/notchdeck-actuator-expansion-2026-10-04.csv` for balances
and source links. No top-up cart or order has been made. Shared inventory does
not expose all live reservations; confirm free allocation before assembly.

[Actuator documentation](../ACTUATORS.md) covers the electronic short limiter,
protected-pack requirement, pin mappings, PWM limits and pending firmware/bench
work. No one-time fuse is selected. Both PCBs remain unrouted placement studies.

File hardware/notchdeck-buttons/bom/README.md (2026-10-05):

# notchdeck-buttons — Rev E sourcing

Checked 2026-10-03. This board has **84 installed components across 13 JLCPCB codes**. The [native BOM](jlcpcb-bom.csv), [tracking BOM](bom.csv), [selection JSON](jlcpcb-parts.json), and [stock observations](jlcpcb-stock.csv) agree with the schematic. The JSON drives the MPN, manufacturer, LCSC, datasheet and notes on each symbol.

Use the [combined five-set stock report](../../jlcpcb-five-set-stock.csv) for purchasing: parts shared between the two boards must be counted together. Public quantities use JLCPCB’s **Available Order Qty** from direct page checks on 2026-10-03. The STM32G030 uses owned private inventory from the shared local CSV; its balance is not published. The shared inventory is a snapshot, with allocation/reservation breakdown unavailable. Confirm allocation and assembly attrition before ordering. The earlier Rev E order was placed and the shared inventory refreshed afterward; the Rev F actuator top-up is separate.

The button MCU is C529330; the new FFC connectors are C262712 (31,746 public available, ten needed), and key isolation diodes are C81598 (4,858,639 available, eighty needed). Older part observations retain their actual timestamps. Public availability covers the combined build; the MCU is covered by the local owned balance. The community JSON category/price snapshots are not live quotes and must not be mistaken for LCSC warehouse stock.

The [Molex cable](../../system-bom.csv) is bought once per complete set from DigiKey, not included in either PCB assembly BOM. Bare programming contacts and mounting holes are excluded from both BOM and CPL. External handle hardware, sensor carriers and enclosure parts are not a complete sourced kit.

Both PCBs are unrouted. Native net/ERC, PCB pad/UUID, BOM identity and package BOM/CPL consistency checks verify the saved design and exports. They do not validate PCB routing, CPL rotation at JLCPCB, electrical/thermal margins or cable/enclosure fit. See [hardware status](../../README.md) and [part constraints](../../PARTS.md). PDFs are cached locally; [manifest](../../datasheets/manifest.json) records sources and board-qualified references.

```sh
make -C hardware verify-notchdeck-buttons verify-pcb-notchdeck-buttons verify-bom-notchdeck-buttons
make -C hardware jlc-notchdeck-buttons
```

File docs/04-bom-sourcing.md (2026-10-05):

# BOM and sourcing — Rev G logic / Rev E panel

The controller has **two separately assembled PCBs**. All installed board components have
selected JLCPCB catalog codes. The following counts and stock observations are
dated in the CSV rows (actuator additions: **2026-10-04 PDT**), not reservations.

| Assembly | Installed parts per board | Unique JLCPCB codes | Tracked assembly BOM |
|---|---:|---:|---|
| Logic / handles / actuators | 129 | 39 | [notchdeck-one](../hardware/notchdeck-one/bom/jlcpcb-bom.csv) |
| Button / RGB panel | 84 | 13 | [notchdeck-buttons](../hardware/notchdeck-buttons/bom/jlcpcb-bom.csv) |
| Complete set | 213 | 44 across both boards | [Five-set stock requirements](../hardware/jlcpcb-five-set-stock.csv) |

Five sets need **1,065 installed parts before assembly attrition**, plus five
interconnect cables. Bare programming contacts and mounting holes are excluded
from BOM/CPL. Shared catalog codes are counted across both boards in the five-set
report; do not independently allocate the same stock balance to each board.

## Selected parts and inventory

The [part map](../hardware/PARTS.md) lists every exact MPN, JLCPCB code and KiCad
footprint. Each project's `bom/jlcpcb-parts.json` drives schematic sourcing
properties; `bom/bom.csv` tracks sourcing and `bom/jlcpcb-stock.csv` records dated
observations. See the [logic BOM notes](../hardware/notchdeck-one/bom/README.md)
and [panel BOM notes](../hardware/notchdeck-buttons/bom/README.md).

- **Main MCU:** Ebyte E73-2G4M08S1C / C356849, with onboard antenna.
- **Panel MCU:** STM32G030F6P6TR / C529330, selected from owned private inventory;
  five required. Its recorded community catalog estimate of about $0.80 is not
  a current quote or the cost paid for owned stock.
- **Power:** MCP73832 / C38066, AP2112K / C51118, MAX17048 / C2682616,
  AO3401A / C15127 and B5819W / C8598. The earlier nPM1300 and MCP73831 options
  are not selected; MCP73832's open-drain STAT matters to this circuit.
- **Panel link:** two JUSHUO AFA07-S06FCA-00 / C262712 connectors per set;
  ten needed for five sets. The snapshot records 31,746 publicly available.
- **Keys:** sixteen 1N4148W / C81598 isolation diodes per panel, with an
  STM32-scanned matrix; two functional buttons and Reset remain on the main PCB.

Dated public availability or owned stock covers five sets. The new C3662776
protector has 110 displayed in stock; exact order allocation remains to confirm.
Private inventory is at `~/Dropbox-elec/github/jlcpcb-private-inventory.csv`,
outside Git. Balances are snapshots; confirm free allocation, attrition and fees
before ordering. Do not count incoming quantities again when already credited.

## Rev G actuator top-up for 20 sets

With 10% spares (22 board-equivalents) and Tenkiro targets held aside, the local
reconciliation currently needs **36 C174045 FETs, 22 C3662776 electronic limiters,
44 C295747 two-pin connectors and 16 C265102 four-pin connectors**. C22775 needs 22 more (recommend buying 100), preserving Tenkiro's reservation. Other added
parts fit the owned balance, including the five B360A diodes per main board and
two 22µF capacitors and the C585880 Micro-Fit inlet. Exact private balances and dated public observations are
in `~/Dropbox-elec/github/notchdeck-actuator-expansion-2026-10-04.csv`, outside Git.
No actuator top-up has been added to a cart or purchased. These are assembly
components only; coils, buzzer, pack and harnesses remain separate.

## Cable and external parts

The [system BOM](../hardware/system-bom.csv) lists one **Molex 0151670213**, DigiKey
**WM13121-ND**, per set: six conductors, 1mm pitch, Type A, 177.8mm. The dated
DigiKey observation was 139 available. It is purchased separately and does not
belong in either PCB assembly BOM.

The [panel guide](../hardware/notchdeck-buttons/README.md) records contact-side
orientation, reversed connector numbering, current limits and the end-thickness
tolerance mismatch still requiring sample-fit or supplier approval. Nominal
dimensions alone do not establish production fit.

Mating handle housings/crimps, external AS5600 carriers, microload switches,
magnets/cams, protected cell, solenoids, active buzzer, keycaps and enclosure are **not a fully sourced kit**.
The PCB stock report does not cover these items. Select exact parts and check
their availability when the mechanical design is finalized.

## Manufacturing exports

From the repository root, with KiCad 10 available:

```sh
make -C hardware verify
make -C hardware jlc
```

Each project produces `<project>/<project>-jlcpcb.zip` under `hardware/`, containing
Gerbers, drill, BOM and `<project>-CPL.csv`. The unzipped files are in
`hardware/<project>/jlcpcb/`. The package script checks that BOM and CPL reference
sets agree. Generated exports are ignored by Git; reviewed BOM snapshots remain
tracked in each `bom/` directory.

**Both boards remain unrouted.** Exporting these files does not release them for
fabrication. Finish the [hardware open work](../hardware/README.md#sourcing-and-remaining-work),
then inspect final assembly eligibility and CPL rotations at JLCPCB. The earlier
May 2026 component-option research has been superseded by these captured selections
and dated stock files; it is not an ordering BOM.

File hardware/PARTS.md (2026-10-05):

# NotchDeck Rev G logic / Rev E panel — selected JLCPCB parts

The logic and button assemblies contain **213 installed parts across 44 JLCPCB codes** per complete set. Stock rows retain their observation dates; actuator additions were checked on **2026-10-04 PDT**; five sets need **1,065 installed parts**, before attrition.

The button MCU is **STM32G030F6P6TR / C529330**, selected from the shared private inventory. Its small TSSOP-20 package, internal oscillator, I²C target and timer/DMA support fit the scanner without external flash or a crystal. The community catalog estimate was about $0.80; owned-stock purchase cost is not recorded. Private balances stay outside this repository.

- [Logic assembly BOM](notchdeck-one/bom/jlcpcb-bom.csv) and [button assembly BOM](notchdeck-buttons/bom/jlcpcb-bom.csv).
- [Combined stock requirement for five sets](jlcpcb-five-set-stock.csv), counting shared parts on both boards.
- [System BOM](system-bom.csv): one DigiKey Molex 0151670213 FFC per set, excluded from PCB assembly BOMs.
- Part selection JSON under each board’s `bom/` drives schematic properties. Dated public stock and tracking exports live beside it.

## Exact selections

References are prefixed L (logic) or B (button). Quantities are per complete set.

| References | Qty | MPN | Manufacturer | JLCPCB | Footprint |
|---|---:|---|---|---|---|
| L: C1… (18; exact list in CSV); B: C21… (21; exact list in CSV) | 39 | CL05B104KO5NNNC | Samsung Electro-Mechanics | [C1525](https://jlcpcb.com/partdetail/C1525) | `Capacitor_SMD:C_0402_1005Metric` |
| L: C18, C19; B: C2 | 3 | CL21A475KAQNNNE | Samsung Electro-Mechanics | [C1779](https://jlcpcb.com/partdetail/C1779) | `Capacitor_SMD:C_0805_2012Metric` |
| L: D18 | 1 | KT-0603R | Hubei KENTO Elec | [C2286](https://jlcpcb.com/partdetail/C2286) | `LED_SMD:LED_0603_1608Metric` |
| L: R3 | 1 | 0402WGF2001TCE | UNI-ROYAL | [C4109](https://jlcpcb.com/partdetail/C4109) | `Resistor_SMD:R_0402_1005Metric` |
| B: U8 | 1 | SN74AHCT1G125DBVR | TI | [C7484](https://jlcpcb.com/partdetail/C7484) | `Package_TO_SOT_SMD:SOT-23-5` |
| L: U7, U10, U11, U12; B: U2 | 5 | USBLC6-2SC6 | ST | [C7519](https://jlcpcb.com/partdetail/C7519) | `Package_TO_SOT_SMD:SOT-23-6` |
| L: Q5, Q6 | 2 | 2N7002 | JSCJ | [C8545](https://jlcpcb.com/partdetail/C8545) | `Package_TO_SOT_SMD:SOT-23` |
| L: D19 | 1 | B5819W SL | JSCJ | [C8598](https://jlcpcb.com/partdetail/C8598) | `Diode_SMD:D_SOD-123` |
| L: R5… (15; exact list in CSV) | 15 | 0402WGF1001TCE | UNI-ROYAL | [C11702](https://jlcpcb.com/partdetail/C11702) | `Resistor_SMD:R_0402_1005Metric` |
| L: Q1 | 1 | AO3401A | AOS | [C15127](https://jlcpcb.com/partdetail/C15127) | `Package_TO_SOT_SMD:SOT-23` |
| L: C5, C9 | 2 | CL21A106KAYNNNE | Samsung Electro-Mechanics | [C15850](https://jlcpcb.com/partdetail/C15850) | `Capacitor_SMD:C_0805_2012Metric` |
| L: R37, R38 | 2 | 0603WAF0000T5E | UNI-ROYAL | [C21189](https://jlcpcb.com/partdetail/C21189) | `Resistor_SMD:R_0603_1608Metric` |
| L: R60 | 1 | 0603WAF1000T5E | UNI-ROYAL | [C22775](https://jlcpcb.com/partdetail/C22775) | `Resistor_SMD:R_0603_1608Metric` |
| L: R43, R44, R45, R58, R56; B: R11 | 6 | 0402WGF3300TCE | UNI-ROYAL | [C25104](https://jlcpcb.com/partdetail/C25104) | `Resistor_SMD:R_0402_1005Metric` |
| L: R4… (12; exact list in CSV); B: R26, R6, R7 | 15 | 0402WGF1003TCE | UNI-ROYAL | [C25741](https://jlcpcb.com/partdetail/C25741) | `Resistor_SMD:R_0402_1005Metric` |
| L: R14… (12; exact list in CSV); B: R1, R2, R3, R4, R5 | 17 | 0402WGF1002TCE | UNI-ROYAL | [C25744](https://jlcpcb.com/partdetail/C25744) | `Resistor_SMD:R_0402_1005Metric` |
| L: R6, R7, R9, R10, R27, R28, R29, R30 | 8 | 0402WGF4701TCE | UNI-ROYAL | [C25900](https://jlcpcb.com/partdetail/C25900) | `Resistor_SMD:R_0402_1005Metric` |
| L: R1, R2 | 2 | 0402WGF5101TCE | UNI-ROYAL | [C25905](https://jlcpcb.com/partdetail/C25905) | `Resistor_SMD:R_0402_1005Metric` |
| B: C13 | 1 | CL21B105KBFNNNE | Samsung Electro-Mechanics | [C28323](https://jlcpcb.com/partdetail/C28323) | `Capacitor_SMD:C_0805_2012Metric` |
| L: U3 | 1 | MCP73832T-2ACI/OT | MICROCHIP | [C38066](https://jlcpcb.com/partdetail/C38066) | `Package_TO_SOT_SMD:SOT-23-5` |
| L: U2 | 1 | AP2112K-3.3TRG1 | DIODES | [C51118](https://jlcpcb.com/partdetail/C51118) | `Package_TO_SOT_SMD:SOT-23-5` |
| L: C3, C4, C7, C8, C12, C47 | 6 | CL05A105KA5NQNC | Samsung Electro-Mechanics | [C52923](https://jlcpcb.com/partdetail/C52923) | `Capacitor_SMD:C_0402_1005Metric` |
| B: D20… (16; exact list in CSV) | 16 | 1N4148W | ST(Semtech) | [C81598](https://jlcpcb.com/partdetail/C81598) | `Diode_SMD:D_SOD-123` |
| L: J1 | 1 | TYPE-C-31-M-12 | Korean Hroparts Elec | [C165948](https://jlcpcb.com/partdetail/C165948) | `Connector_USB:USB_C_Receptacle_HRO_TYPE-C-31-M-12` |
| L: Q2, Q3, Q4 | 3 | ZXMS6005DGTA | DIODES | [C174045](https://jlcpcb.com/partdetail/C174045) | `Package_TO_SOT_SMD:SOT-223-3_TabPin2` |
| L: J15; B: J1 | 2 | AFA07-S06FCA-00 | JUSHUO | [C262712](https://jlcpcb.com/partdetail/C262712) | `Connector_FFC-FPC:JUSHUO_AFA07-S06FCA-00_1x6-1MP_P1.0mm_Horizontal` |
| L: J9 | 1 | S3B-PH-SM4-TB(LF)(SN) | JST | [C265101](https://jlcpcb.com/partdetail/C265101) | `Connector_JST:JST_PH_S3B-PH-SM4-TB_1x03-1MP_P2.00mm_Horizontal` |
| L: J10, J11, J19 | 3 | S4B-PH-SM4-TB(LF)(SN) | JST | [C265102](https://jlcpcb.com/partdetail/C265102) | `Connector_JST:JST_PH_S4B-PH-SM4-TB_1x04-1MP_P2.00mm_Horizontal` |
| L: J12 | 1 | S5B-PH-SM4-TB(LF)(SN) | JST | [C265104](https://jlcpcb.com/partdetail/C265104) | `Connector_JST:JST_PH_S5B-PH-SM4-TB_1x05-1MP_P2.00mm_Horizontal` |
| L: J5 | 1 | S6B-PH-SM4-TB(LF)(SN) | JST | [C265405](https://jlcpcb.com/partdetail/C265405) | `Connector_JST:JST_PH_S6B-PH-SM4-TB_1x06-1MP_P2.00mm_Horizontal` |
| L: J16, J17, J18 | 3 | S2B-PH-SM4-TB(LF)(SN) | JST | [C295747](https://jlcpcb.com/partdetail/C295747) | `Connector_JST:JST_PH_S2B-PH-SM4-TB_1x02-1MP_P2.00mm_Horizontal` |
| L: C45, C46 | 2 | CL32B226KAJNNNE | Samsung Electro-Mechanics | [C309062](https://jlcpcb.com/partdetail/C309062) | `Capacitor_SMD:C_1210_3225Metric` |
| L: SW17, SW18, SW19; B: SW1… (16; exact list in CSV) | 19 | TS-1187A-B-A-B | XKB Connection | [C318884](https://jlcpcb.com/partdetail/C318884) | `Button_Switch_SMD:SW_Push_1P1T_XKB_TS-1187A` |
| L: U1 | 1 | E73-2G4M08S1C | Ebyte | [C356849](https://jlcpcb.com/partdetail/C356849) | `notchdeck:EBYTE_E73-2G4M08S1C` |
| L: J3 | 1 | FTSH-105-01-L-DV-K-TR | Samtec | [C448647](https://jlcpcb.com/partdetail/C448647) | `notchdeck:Samtec_FTSH-105-01-L-DV-K` |
| L: U5 | 1 | AS5600-ASOT | ams | [C499458](https://jlcpcb.com/partdetail/C499458) | `Package_SO:SOIC-8_3.9x4.9mm_P1.27mm` |
| B: U1 | 1 | STM32G030F6P6TR | ST | [C529330](https://jlcpcb.com/partdetail/C529330) | `Package_SO:TSSOP-20_4.4x6.5mm_P0.65mm` |
| L: J2 | 1 | 430450401 | Molex | [C585880](https://jlcpcb.com/partdetail/C585880) | `Connector_Molex:Molex_Micro-Fit_3.0_43045-0400_2x02_P3.00mm_Horizontal` |
| L: D17 | 1 | XL-1608SYGC-06 | XINGLIGHT | [C965805](https://jlcpcb.com/partdetail/C965805) | `LED_SMD:LED_0603_1608Metric` |
| L: U9 | 1 | TCA9543APWR | TI | [C2653307](https://jlcpcb.com/partdetail/C2653307) | `Package_SO:TSSOP-14_4.4x5mm_P0.65mm` |
| L: U4 | 1 | MAX17048G+T10 | MAXIM | [C2682616](https://jlcpcb.com/partdetail/C2682616) | `Package_DFN_QFN:TDFN-8-1EP_2x2mm_P0.5mm_EP0.8x1.2mm` |
| B: D1… (16; exact list in CSV) | 16 | XL-5050RGBC-2812B | XINGLIGHT | [C2843785](https://jlcpcb.com/partdetail/C2843785) | `notchdeck:LED_XINGLIGHT_XL-5050RGBC-2812B` |
| L: U13 | 1 | TPS259461LRPWR | Texas Instruments | [C3662776](https://jlcpcb.com/partdetail/C3662776) | `notchdeck:TI_RPW0010A` |
| L: D20, D21, D22, D23, D24 | 5 | B360A | FUXINSEMI | [C6807778](https://jlcpcb.com/partdetail/C6807778) | `Diode_SMD:D_SMA` |

## Selection constraints

Actuator Q2–4 use owned ZXMS6005DGTA; U13 is TPS259461LRPWR (full battery-input electronic limiter, latched thermal shutdown). No disposable fuse is selected. Five B360A diodes and two 22µF/25V capacitors also use owned stock. See [actuator protection and limits](notchdeck-one/ACTUATORS.md).

Use MCP73832 open-drain STAT, not MCP73831. Retain TI AHCT for the 3V3-to-USB5V RGB buffer; AHC/HC is not equivalent. RGB C2843785 and the keyed Samtec SWD header use project-local footprints transcribed from manufacturer drawings; see [attributions](lib/ATTRIBUTIONS.md). The E73 footprint/antenna clearance and MAX17048 exposed pad still need final package review.

Button U1 uses internally bonded pins in TSSOP-20; configure only the chosen alias and leave other aliases high impedance. See [button-board interface](notchdeck-buttons/README.md). FFC J15/J1 use identical bottom-contact connectors with reversed pin assignment for the specified Type A cable.

Logic J4 and button J2 are bare Tag-Connect contacts, excluded from BOM and CPL. Both boards have four PCB-only holes. External handle mechanisms, magnetic sensor carriers, harnesses, protected battery, keycaps and enclosure remain separate unsourced items.

Run `make -C hardware verify` after changing selections. Both PCBs are unrouted; available parts and clean ERC do not establish fabrication readiness.

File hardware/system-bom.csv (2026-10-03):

Item | Manufacturer | MPN | Distributor | Distributor PN | Qty per set | Build sets | Qty for build | Stock snapshot | Unit price USD snapshot | Checked UTC | URL | Notes
Main-to-button FFC cable | Molex | 0151670213 | DigiKey | WM13121-ND | 1 | 5 | 5 | 139 | 2.31 | 2026-10-03 | https://www.digikey.com/en/products/detail/molex/0151670213/3281466 | 6-way 1mm pitch Type A same-side; 177.8mm; 0.30mm reinforced ends. Main J15 pin n -> button J1 pin 7-n. Separate purchase, excluded from both PCB assembly BOMs.

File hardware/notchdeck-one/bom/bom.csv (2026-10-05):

Reference | Qty | Value | Footprint | MPN | Manufacturer | LCSC | LC_Stock | Chosen_Distributor | Datasheet | Validated | DNP | Notes
C1,C2,C6,C10,C11,C14,C15,C16,C17,C37,C38,C39,C40,C41,C42,C43,C44,C48 | 18 | 100nF | 0402 | CL05B104KO5NNNC | Samsung Electro-Mechanics | C1525 |  | JLCPCB | https://datasheet.lcsc.com/datasheet/pdf/02336ea48ea44ca18c72517dd3cb7b47.pdf?productCode=C1525 | Yes |  | 100nF 16V X7R ±10% 0402 Multilayer Ceramic Capacitors MLCC - SMD/SMT ROHS
C3,C4,C7,C8,C12,C47 | 6 | 1uF | 0402 | CL05A105KA5NQNC | Samsung Electro-Mechanics | C52923 |  | JLCPCB | https://datasheet.lcsc.com/datasheet/pdf/02336ea48ea44ca18c72517dd3cb7b47.pdf?productCode=C52923 | Yes |  | 1uF 25V X5R ±10% 0402 Multilayer Ceramic Capacitors MLCC - SMD/SMT ROHS
C5,C9 | 2 | 10uF | 0805 | CL21A106KAYNNNE | Samsung Electro-Mechanics | C15850 |  | JLCPCB | https://datasheet.lcsc.com/datasheet/pdf/02336ea48ea44ca18c72517dd3cb7b47.pdf?productCode=C15850 | Yes |  | 10uF 25V X5R ±10% 0805 Multilayer Ceramic Capacitors MLCC - SMD/SMT ROHS
C18,C19 | 2 | 4.7uF | 0805 | CL21A475KAQNNNE | Samsung Electro-Mechanics | C1779 |  | JLCPCB | https://datasheet.lcsc.com/datasheet/pdf/02336ea48ea44ca18c72517dd3cb7b47.pdf?productCode=C1779 | Yes |  | 25V 4.7uF X5R ±10% 0805 Multilayer Ceramic Capacitors MLCC - SMD/SMT ROHS
C45,C46 | 2 | 22uF | 1210 | CL32B226KAJNNNE | Samsung Electro-Mechanics | C309062 |  | JLCPCB | https://datasheet.lcsc.com/datasheet/pdf/02336ea48ea44ca18c72517dd3cb7b47.pdf?productCode=C309062 | Yes |  | 22uF/25V X7R bulk; allow DC-bias derating; near actuator connectors.
D17 | 1 | LED | 0603 | XL-1608SYGC-06 | XINGLIGHT | C965805 |  | JLCPCB | https://datasheet.lcsc.com/datasheet/pdf/db39074692074ba57d43d76e9fc6dbf2.pdf?productCode=C965805 | Yes
D18 | 1 | LED | 0603 | KT-0603R | Hubei KENTO Elec | C2286 |  | JLCPCB | https://datasheet.lcsc.com/datasheet/pdf/011ec3e8cb1e825f6961d29bc4db4c7a.pdf?productCode=C2286 | Yes
D19 | 1 | B5819W | SOD-123 | B5819W SL | JSCJ | C8598 |  | JLCPCB | https://datasheet.lcsc.com/datasheet/pdf/4ac2c059be7c462694ab0715ce987a85.pdf?productCode=C8598 | Yes
D20,D21,D22,D23,D24 | 5 | B360A | SMA(DO-214AC) | B360A | FUXINSEMI | C6807778 |  | JLCPCB | https://datasheet.lcsc.com/datasheet/pdf/4341698a2794575dc7c94af0a06dfb39.pdf?productCode=C6807778 | Yes |  | D20-D22 flyback K=BAT_PROT/A=load return; D23 clamp K=BAT_PROT/A=GND; D24 charging recovery K=BAT_RAW/A=BAT_PROT.
J1 | 1 | USB-C | SMD | TYPE-C-31-M-12 | Korean Hroparts Elec | C165948 |  | JLCPCB | https://datasheet.lcsc.com/datasheet/pdf/9e56b777c022540fcce7c7f67825f55e.pdf?productCode=C165948 | Yes
J2 | 1 | BAT 1S / 2+2 | THT right-angle 2x2 3mm | 430450401 | Molex | C585880 |  | JLCPCB | https://datasheet.lcsc.com/datasheet/pdf/b6e3df063c26f8567b294b4b1d02bfdf.pdf?productCode=C585880 | Yes |  | Owned Micro-Fit battery inlet: 1+2 positive, 3+4 GND. Populate both contacts per polarity with 20AWG leads. THT assembly.
J3 | 1 | SWD | SMD,P=1.27mm | FTSH-105-01-L-DV-K-TR | Samtec | C448647 |  | JLCPCB | https://datasheet.lcsc.com/datasheet/pdf/75565f450863f224a13c3fa6d9c6afc1.pdf?productCode=C448647 | Yes |  | Samtec keyed shroud; manufacturer land pattern. Check JLCPCB fixture requirement and CPL rotation.
J5 | 1 | BRAKE / MASCON GRAY | SMD,P=2mm,Right Angle | S6B-PH-SM4-TB(LF)(SN) | JST | C265405 |  | JLCPCB | https://datasheet.lcsc.com/datasheet/pdf/fd6b0599884a99953f02d32fdcec9311.pdf?productCode=C265405 | Yes |  | Rev D brake/mascon Gray harness: pin1=GND, pins2..5=S0..S3, pin6=3V3. Passive cams leave supply cavity empty. Mating PHR-6 housing/crimps separate.
J9 | 1 | REV F-N-R | SMD,P=2mm,卧贴 | S3B-PH-SM4-TB(LF)(SN) | JST | C265101 |  | JLCPCB | https://datasheet.lcsc.com/datasheet/pdf/6c6fce4367275d84ec6a99bf09f1250f.pdf?productCode=C265101 | Yes |  | External center-off reverser and mating harness not included.
J10 | 1 | POWER MAG | SMD,P=2mm,卧贴 | S4B-PH-SM4-TB(LF)(SN) | JST | C265102 |  | JLCPCB | https://datasheet.lcsc.com/datasheet/pdf/6c6fce4367275d84ec6a99bf09f1250f.pdf?productCode=C265102 | Yes |  | 3.3V magnetic handle: pin 1=3V3, 2=GND, 3=SDA, 4=SCL. Mating harness/sensor separate.
J11 | 1 | BRAKE MAG | SMD,P=2mm,卧贴 | S4B-PH-SM4-TB(LF)(SN) | JST | C265102 |  | JLCPCB | https://datasheet.lcsc.com/datasheet/pdf/6c6fce4367275d84ec6a99bf09f1250f.pdf?productCode=C265102 | Yes |  | 3.3V magnetic handle: pin 1=3V3, 2=GND, 3=SDA, 4=SCL. Mating harness/sensor separate.
J12 | 1 | POWER GRAY | SMD,P=2mm,Right Angle | S5B-PH-SM4-TB(LF)(SN) | JST | C265104 |  | JLCPCB | https://datasheet.lcsc.com/datasheet/pdf/d87682fbfaf1a1bc6a21af6a6a17fd27.pdf?productCode=C265104 | Yes |  | Rev D power Gray harness: pin1=GND, pins2..4=S0..S2, pin5=3V3. Passive cams leave supply cavity empty. Mating PHR-5 housing/crimps separate.
J15 | 1 | BUTTON MCU FFC | SMD,P=1mm,卧贴 | AFA07-S06FCA-00 | JUSHUO | C262712 |  | JLCPCB | https://datasheet.lcsc.com/datasheet/pdf/b01391708457137d9b8d8b493bdc4f0c.pdf?productCode=C262712 | Yes |  | 6-way 1mm bottom-contact FFC. Molex 0151670213 Type A cable: main J15 pin n -> button J1 pin 7-n. Cable bought once per set from DigiKey; power off to insert.
J16 | 1 | SOLENOID 1 | SMD,P=2mm,卧贴 | S2B-PH-SM4-TB(LF)(SN) | JST | C295747 |  | JLCPCB | https://datasheet.lcsc.com/datasheet/pdf/2474e9261ed7c5f86b55d373e724589d.pdf?productCode=C295747 | Yes |  | Two-pin JST PH battery connector. Pin1=BAT+, pin2=GND. Mating harness separate.
J17 | 1 | SOLENOID 2 | SMD,P=2mm,卧贴 | S2B-PH-SM4-TB(LF)(SN) | JST | C295747 |  | JLCPCB | https://datasheet.lcsc.com/datasheet/pdf/2474e9261ed7c5f86b55d373e724589d.pdf?productCode=C295747 | Yes |  | Two-pin JST PH battery connector. Pin1=BAT+, pin2=GND. Mating harness separate.
J18 | 1 | ACTIVE BUZZER | SMD,P=2mm,卧贴 | S2B-PH-SM4-TB(LF)(SN) | JST | C295747 |  | JLCPCB | https://datasheet.lcsc.com/datasheet/pdf/2474e9261ed7c5f86b55d373e724589d.pdf?productCode=C295747 | Yes |  | Two-pin JST PH battery connector. Pin1=BAT+, pin2=GND. Mating harness separate.
J19 | 1 | EXTERNAL PWM 3V3 | SMD,P=2mm,卧贴 | S4B-PH-SM4-TB(LF)(SN) | JST | C265102 |  | JLCPCB | https://datasheet.lcsc.com/datasheet/pdf/6c6fce4367275d84ec6a99bf09f1250f.pdf?productCode=C265102 | Yes |  | 3.3V magnetic handle: pin 1=3V3, 2=GND, 3=SDA, 4=SCL. Mating harness/sensor separate.
Q1 | 1 | AO3401A | SOT-23 | AO3401A | AOS | C15127 |  | JLCPCB | https://datasheet.lcsc.com/datasheet/pdf/fee353dd1e9e0bc90b295f14f381aa4c.pdf?productCode=C15127 | Yes
Q2,Q3,Q4 | 3 | ZXMS6005DGTA | SOT-223-3 | ZXMS6005DGTA | DIODES | C174045 |  | JLCPCB | https://datasheet.lcsc.com/datasheet/pdf/f028d27543061fafe3ef0d34478a3c92.pdf?productCode=C174045 | Yes |  | Protected low-side FET; pin 1 IN, pin 2/tab D, pin 3 S. 3V minimum input; 500Hz solenoid PWM target; qualify low-battery drive and thermal margins.
Q5,Q6 | 2 | 2N7002 | SOT-23 | 2N7002 | JSCJ | C8545 |  | JLCPCB | https://datasheet.lcsc.com/datasheet/pdf/a141b8bd86b14475955ac8c4d3eea0a8.pdf?productCode=C8545 | Yes |  | Charger PROG interlock: suspend charging while actuator bank is enabled
R1,R2 | 2 | 5.1k | 0402 | 0402WGF5101TCE | UNI-ROYAL | C25905 |  | JLCPCB | https://datasheet.lcsc.com/datasheet/pdf/0a975aaa49b7c97f38a963127be4a823.pdf?productCode=C25905 | Yes |  | -55℃~+155℃ 5.1kΩ 50V 62.5mW Thick Film Resistor ±1% ±100ppm/℃ 0402 Chip Resistor - Surface Mount ROHS
R3 | 1 | 2k | 0402 | 0402WGF2001TCE | UNI-ROYAL | C4109 |  | JLCPCB | https://datasheet.lcsc.com/datasheet/pdf/0a975aaa49b7c97f38a963127be4a823.pdf?productCode=C4109 | Yes |  | -55℃~+155℃ 2kΩ 50V 62.5mW Thick Film Resistor ±1% ±100ppm/℃ 0402 Chip Resistor - Surface Mount ROHS
R4,R8,R22,R23,R24,R46,R47,R48,R52,R53,R55,R59 | 12 | 100k | 0402 | 0402WGF1003TCE | UNI-ROYAL | C25741 |  | JLCPCB | https://datasheet.lcsc.com/datasheet/pdf/0a975aaa49b7c97f38a963127be4a823.pdf?productCode=C25741 | Yes |  | -55℃~+155℃ 100kΩ 50V 62.5mW Thick Film Resistor ±1% ±100ppm/℃ 0402 Chip Resistor - Surface Mount ROHS
R5,R12,R13,R18,R19,R20,R21,R25,R34,R35,R36,R49,R50,R51,R54 | 15 | 1k | 0402 | 0402WGF1001TCE | UNI-ROYAL | C11702 |  | JLCPCB | https://datasheet.lcsc.com/datasheet/pdf/0a975aaa49b7c97f38a963127be4a823.pdf?productCode=C11702 | Yes |  | -55℃~+155℃ 1kΩ 50V 62.5mW Thick Film Resistor ±1% ±100ppm/℃ 0402 Chip Resistor - Surface Mount ROHS
R6,R7,R9,R10,R27,R28,R29,R30 | 8 | 4.7k | 0402 | 0402WGF4701TCE | UNI-ROYAL | C25900 |  | JLCPCB | https://datasheet.lcsc.com/datasheet/pdf/0a975aaa49b7c97f38a963127be4a823.pdf?productCode=C25900 | Yes |  | -55℃~+155℃ 4.7kΩ 50V 62.5mW Thick Film Resistor ±1% ±100ppm/℃ 0402 Chip Resistor - Surface Mount ROHS
R14,R15,R16,R17,R31,R32,R33,R39,R40,R41,R42,R57 | 12 | 10k | 0402 | 0402WGF1002TCE | UNI-ROYAL | C25744 |  | JLCPCB | https://datasheet.lcsc.com/datasheet/pdf/0a975aaa49b7c97f38a963127be4a823.pdf?productCode=C25744 | Yes |  | -55℃~+155℃ 10kΩ 50V 62.5mW Thick Film Resistor ±1% ±100ppm/℃ 0402 Chip Resistor - Surface Mount ROHS
R37,R38 | 2 | 0 | 0603 | 0603WAF0000T5E | UNI-ROYAL | C21189 |  | JLCPCB | https://datasheet.lcsc.com/datasheet/pdf/f42da6c80a0747bae77c2f98f4e46d1d.pdf?productCode=C21189 | Yes |  | Remove BOTH R37/R38 before connecting an external power AS5600 to J10; isolates onboard U5.
R43,R44,R45,R56,R58 | 5 | 330 | 0402 | 0402WGF3300TCE | UNI-ROYAL | C25104 |  | JLCPCB | https://datasheet.lcsc.com/datasheet/pdf/0a975aaa49b7c97f38a963127be4a823.pdf?productCode=C25104 | Yes |  | -55℃~+155℃ 330Ω 50V 62.5mW Thick Film Resistor ±1% ±100ppm/℃ 0402 Chip Resistor - Surface Mount ROHS
R60 | 1 | 100 | 0603 | 0603WAF1000T5E | UNI-ROYAL | C22775 |  | JLCPCB | https://datasheet.lcsc.com/datasheet/pdf/0a975aaa49b7c97f38a963127be4a823.pdf?productCode=C22775 | Yes |  | 100 ohm resistor in series with 100nF DVDT capacitor as TI recommends for >10nF. Existing private stock is reserved; top-up required.
SW17 | 1 | RESET | SMD-4P,5.1x5.1mm | TS-1187A-B-A-B | XKB Connection | C318884 |  | JLCPCB | https://datasheet.lcsc.com/datasheet/pdf/56c8799ae5193945a16a1ffbe378246a.pdf?productCode=C318884 | Yes
SW18 | 1 | SELECT | SMD-4P,5.1x5.1mm | TS-1187A-B-A-B | XKB Connection | C318884 |  | JLCPCB | https://datasheet.lcsc.com/datasheet/pdf/56c8799ae5193945a16a1ffbe378246a.pdf?productCode=C318884 | Yes
SW19 | 1 | START | SMD-4P,5.1x5.1mm | TS-1187A-B-A-B | XKB Connection | C318884 |  | JLCPCB | https://datasheet.lcsc.com/datasheet/pdf/56c8799ae5193945a16a1ffbe378246a.pdf?productCode=C318884 | Yes
U1 | 1 | E73-2G4M08S1C | SMD,18x13mm | E73-2G4M08S1C | Ebyte | C356849 |  | JLCPCB | https://devzone.nordicsemi.com/cfs-file/__key/support-attachments/beef5d1b77644c448dabff31668f3a47-501ceb3d34d541b591f720b20ce1b1ba/E73_2D00_2G4M08S1C_5F00_Us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 | Yes |  | Ebyte module with onboard antenna; preserve antenna clearance. No substitute without pinout/RF review.
U2 | 1 | AP2112K-3.3 | SOT-25-5 | AP2112K-3.3TRG1 | DIODES | C51118 |  | JLCPCB | https://datasheet.lcsc.com/datasheet/pdf/5b29baebdc4332b382a530ff21092301.pdf?productCode=C51118 | Yes
U3 | 1 | MCP73832-2-OT | SOT-23-5 | MCP73832T-2ACI/OT | MICROCHIP | C38066 |  | JLCPCB | https://datasheet.lcsc.com/datasheet/pdf/852a87d0adc246b1ba9a5a84f9d77888.pdf?productCode=C38066 | Yes |  | MCP73832 open-drain STAT required; do not substitute MCP73831. Check 500 mA charging against battery and USB budget.
U4 | 1 | MAX17048 | DFN-8-EP(2x2) | MAX17048G+T10 | MAXIM | C2682616 |  | JLCPCB | https://datasheet.lcsc.com/datasheet/pdf/6ea2434b9fcbd476e93afe7bcb1f53c0.pdf?productCode=C2682616 | Yes |  | Exact MAX17048G+T10 TDFN variant; land-pattern review remains open.
U5 | 1 | AS5600 | SOIC-8 | AS5600-ASOT | ams | C499458 |  | JLCPCB | https://datasheet.lcsc.com/datasheet/pdf/0163ccf74074c4b353a988081c09f0dd.pdf?productCode=C499458 | Yes |  | Onboard power/combined magnetic sensor. Remove R37/R38 for external power sensor on J10.
U7,U10,U11,U12 | 4 | USBLC6-2SC6 | SOT-23-6L | USBLC6-2SC6 | ST | C7519 |  | JLCPCB | https://datasheet.lcsc.com/datasheet/pdf/0d3a2ab954b34651a0695e7ccf534db0.pdf?productCode=C7519 | Yes
U9 | 1 | TCA9543APWR | TSSOP-14 | TCA9543APWR | TI | C2653307 |  | JLCPCB | https://datasheet.lcsc.com/datasheet/pdf/4107098bf2c5ce9d0a240a1c4ceb8054.pdf?productCode=C2653307 | Yes |  | Address 0x70. Enable only one downstream channel at a time; RESET follows board nRESET.
U13 | 1 | TPS259461LRPWR | VQFN-HR-10 2x2mm RPW | TPS259461LRPWR | Texas Instruments | C3662776 |  | JLCPCB | https://www.ti.com/lit/ds/symlink/tps25946.pdf | Yes |  | Full battery input electronic limit 5.05A nominal; bidirectional when on, latch-off after thermal fault. 660 ohm ILM; ITIMER open.

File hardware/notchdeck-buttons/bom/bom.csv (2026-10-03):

Reference | Qty | Value | Footprint | MPN | Manufacturer | LCSC | LC_Stock | Chosen_Distributor | Datasheet | Validated | DNP | Notes
C1,C3,C4,C5,C20,C21,C22,C23,C24,C25,C26,C27,C28,C29,C30,C31,C32,C33,C34,C35,C36 | 21 | 100nF | 0402 | CL05B104KO5NNNC | Samsung Electro-Mechanics | C1525 |  | LCSC | https://datasheet.lcsc.com/datasheet/pdf/02336ea48ea44ca18c72517dd3cb7b47.pdf?productCode=C1525 | Yes |  | 100nF 16V X7R ±10% 0402 Multilayer Ceramic Capacitors MLCC - SMD/SMT ROHS
C2 | 1 | 4.7uF | 0805 | CL21A475KAQNNNE | Samsung Electro-Mechanics | C1779 |  | LCSC | https://datasheet.lcsc.com/datasheet/pdf/02336ea48ea44ca18c72517dd3cb7b47.pdf?productCode=C1779 | Yes |  | 25V 4.7uF X5R ±10% 0805 Multilayer Ceramic Capacitors MLCC - SMD/SMT ROHS
C13 | 1 | 1uF | 0805 | CL21B105KBFNNNE | Samsung Electro-Mechanics | C28323 |  | LCSC | https://datasheet.lcsc.com/datasheet/pdf/02336ea48ea44ca18c72517dd3cb7b47.pdf?productCode=C28323 | Yes |  | 1uF 50V X7R ±10% 0805 Multilayer Ceramic Capacitors MLCC - SMD/SMT ROHS
D1,D2,D3,D4,D5,D6,D7,D8,D9,D10,D11,D12,D13,D14,D15,D16 | 16 | WS2812B | SMD5050-4P | XL-5050RGBC-2812B | XINGLIGHT | C2843785 |  | LCSC | https://datasheet.lcsc.com/datasheet/pdf/40b65f6fea0587c0483bbbd4496835fd.pdf?productCode=C2843785 | Yes |  | Same RGB part for D1-D16. Check pin 1 and polarity in CPL preview; firmware brightness/current limit required.
D20,D21,D22,D23,D24,D25,D26,D27,D28,D29,D30,D31,D32,D33,D34,D35 | 16 | 1N4148W | SOD-123 | 1N4148W | ST(Semtech) | C81598 |  | LCSC | https://datasheet.lcsc.com/datasheet/pdf/8abd7fc00ebe41ffb03ad1383c10753b.pdf?productCode=C81598 | Yes |  | Matrix isolation: cathode (pad1) to row; anode to switch, then column. Scan one row low, others high impedance.
J1 | 1 | TO MAIN J15 / FFC | SMD,P=1mm,卧贴 | AFA07-S06FCA-00 | JUSHUO | C262712 |  | LCSC | https://datasheet.lcsc.com/datasheet/pdf/b01391708457137d9b8d8b493bdc4f0c.pdf?productCode=C262712 | Yes |  | 6-way 1mm bottom-contact FFC. Molex 0151670213 Type A cable: main J15 pin n -> button J1 pin 7-n. Cable bought once per set from DigiKey; power off to insert.
R1,R2,R3,R4,R5 | 5 | 10k | 0402 | 0402WGF1002TCE | UNI-ROYAL | C25744 |  | LCSC | https://datasheet.lcsc.com/datasheet/pdf/0a975aaa49b7c97f38a963127be4a823.pdf?productCode=C25744 | Yes |  | -55℃~+155℃ 10kΩ 50V 62.5mW Thick Film Resistor ±1% ±100ppm/℃ 0402 Chip Resistor - Surface Mount ROHS
R6,R7,R26 | 3 | 100k | 0402 | 0402WGF1003TCE | UNI-ROYAL | C25741 |  | LCSC | https://datasheet.lcsc.com/datasheet/pdf/0a975aaa49b7c97f38a963127be4a823.pdf?productCode=C25741 | Yes |  | -55℃~+155℃ 100kΩ 50V 62.5mW Thick Film Resistor ±1% ±100ppm/℃ 0402 Chip Resistor - Surface Mount ROHS
R11 | 1 | 330 | 0402 | 0402WGF3300TCE | UNI-ROYAL | C25104 |  | LCSC | https://datasheet.lcsc.com/datasheet/pdf/0a975aaa49b7c97f38a963127be4a823.pdf?productCode=C25104 | Yes |  | -55℃~+155℃ 330Ω 50V 62.5mW Thick Film Resistor ±1% ±100ppm/℃ 0402 Chip Resistor - Surface Mount ROHS
SW1,SW2,SW3,SW4,SW5,SW6,SW7,SW8,SW9,SW10,SW11,SW12,SW13,SW14,SW15,SW16 | 16 | SW_Push | SMD-4P,5.1x5.1mm | TS-1187A-B-A-B | XKB Connection | C318884 |  | LCSC | https://datasheet.lcsc.com/datasheet/pdf/56c8799ae5193945a16a1ffbe378246a.pdf?productCode=C318884 | Yes
U1 | 1 | STM32G030F6P6TR | TSSOP-20 | STM32G030F6P6TR | ST | C529330 |  | LCSC | https://datasheet.lcsc.com/datasheet/pdf/753f35401d4598e355b1dd55569495e1.pdf?productCode=C529330 | Yes |  | Use owned JLCPCB private stock for five button boards. I2C target 0x20; requires separate button-board firmware and SWD programming.
U2 | 1 | USBLC6-2SC6 | SOT-23-6L | USBLC6-2SC6 | ST | C7519 |  | LCSC | https://datasheet.lcsc.com/datasheet/pdf/0d3a2ab954b34651a0695e7ccf534db0.pdf?productCode=C7519 | Yes
U8 | 1 | 74AHCT1G125 | SOT-23-5 | SN74AHCT1G125DBVR | TI | C7484 |  | LCSC | https://datasheet.lcsc.com/datasheet/pdf/74b1f7dfbe12452e8a365e0596ae902b.pdf?productCode=C7484 | Yes |  | AHCT with TTL-compatible input at 5 V required; do not substitute AHC/HC.

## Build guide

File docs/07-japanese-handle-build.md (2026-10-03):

# Japanese-style handles on the Rev E controller

Build either a left-hand power lever and a right-hand rotary brake, or a combined
mascon, around the same NotchDeck One PCB. The mechanisms are chassis mounted;
the sensor boards and main PCB do not carry handle, bearing or end-stop loads.
Each active handle independently selects magnetic sensing or a Gray-code cam.

This is our own-build interface, not a plug-compatible railway controller.
JR East describes its 211-series two-handle arrangement as left-hand power and
right-hand brake ([operator reference](https://media.jreast.co.jp/articles/4293)).
That establishes the arrangement, not universal notch counts, shaft dimensions or
connector wiring. Our P5/B8 baseline also supports the combined 15-position
layout described by [ZUIKI](https://www.zuiki.co.jp/topics_customer/news-article16/).
Automatic-air-brake positions such as running/lap/service are not implemented.

## Mechanism contract

| Assembly | Travel and detents | Sensor connection |
|---|---|---|
| Left power lever | Off, P1–P5; six stops, positive end stops. Provisional fore/aft mechanism, pull toward driver for power. | AS5600 at J10, or three contact cam tracks at J12 |
| Right rotary brake | Release, B1–B8, EB; ten stops on a bounded rotation. Provisional clockwise rotation increases braking. | AS5600 at J11, or four contact cam tracks at J5 |
| Combined mascon | EB, B8–B1, N, P1–P5; fifteen stops. Provisional fore/aft mechanism, forward for braking, toward driver for power. | AS5600 at J10, or four contact cam tracks at J5; J11 and J12 unused |

Use a separate detent plate and spring-loaded follower for feel. The sensing
mechanism reads the shaft position; it does not create the detents or take stop
loads. Give N/Off/Release an identifiable detent. Provide a distinct mechanical
barrier or higher effort between maximum service braking and EB; the provisional
geometry leaves a larger angular interval there. Select the actual spring forces,
release mechanism, shaft, bearings and fasteners during the mechanical prototype.

A magnetic carrier puts a diametrically magnetized magnet on the shaft end and an
AS5600 board centered below it. On a fore/aft lever, the sensor follows the
horizontal pivot axis; on the rotary brake, it follows the vertical axis. Use an
adjustable carrier to set the magnet gap and alignment. For Gray sensing, replace
the magnet/carrier with three or four coaxial cam tracks and stationary microload
switches. Both sensor options use the same detent plate and mechanical stops.
The AS5600 carrier PCB and cam/switch brackets remain to be detailed.

## Harnesses

Rev E retains Rev D's keyed harness per cam, replacing the individual Rev C bit plugs:

| Pin | J12 POWER GRAY, PHR-5 housing | J5 BRAKE / MASCON GRAY, PHR-6 housing |
|---|---|---|
| 1 | GND, all switch common terminals | GND, all switch common terminals |
| 2 | S0 | S0 |
| 3 | S1 | S1 |
| 4 | S2 | S2 |
| 5 | 3V3; leave cavity empty for passive contacts | S3 |
| 6 | — | 3V3; leave cavity empty for passive contacts |

Connect normally-open microload contacts between the indicated bit and GND.
A cam lobe closes the contact where the CSV says `switches_closed_to_ground`.
Read pin numbers from the PCB/header drawing; do not infer numbering from wire
colors or an assumed cable view. Check continuity before plugging in. The 3V3
pins allow an externally designed active Gray sensor with 3.3V open-drain outputs;
its load, local decoupling and output behavior must be reviewed before use. Do
not feed voltage into any port. Rev C individual contact cables do not fit this
new pinout.

Magnetic ports J10/J11 retain PHR-4 housings: **1=3V3, 2=GND, 3=SDA, 4=SCL**.
For this panel layout, use external sensor boards and remove **both R37 and R38**
to isolate onboard U5 from J10. Keep cables short, initially ≤20cm for I²C,
strain-relieved and inside the enclosure; verify rise time at 100kHz. The layout's
dashed paths show connection choices, not measured harness lengths. Reposition
the PCB if the actual route cannot meet the cable target. Power down to change
harnesses. Detailed circuit behavior is in the [interface guide](06-handle-interfaces.md).

## Adjustable layout and cam targets

Provisional dual and combined panel arrangements

- [`handle-layout.json`](../hardware/mechanical/handle-layout.json) records the
  provisional 400×220mm panel, module envelopes and target detent angles.
- [`handle-layout.svg`](../hardware/mechanical/handle-layout.svg) shows the actual
  115×90mm logic PCB and separate 86×120mm 4×4 button board within those envelopes. It is an integration
  drawing, not a cutting template or an enclosure fit check.
- [`detents-and-cams.csv`](../hardware/mechanical/detents-and-cams.csv) gives all
  31 targets across the three assemblies, electrical Gray levels, contacts that
  close and connector pins. Codes are read directly from `handle_decode.c`.

Regenerate after changing the provisional geometry:

```sh
python3 hardware/scripts/notchdeck-handle-layout.py
```

The target angles are design inputs for a mock-up, **not magnetic calibration**.
Place cam transitions halfway between adjacent detent centers, with generous
stable regions around each detent; adjust ramp shape for the selected follower's
travel and hysteresis. For magnetic builds, measure each assembled detent's raw
angle and populate `handle_calibration.h`; uncalibrated magnetic profiles remain
faulted. No complete cam, shaft, bearing carrier or production cutout CAD is
implied by this layout study.

## Build selection and bring-up

Use `dual_gray.conf`, `dual_magnetic.conf`, or either mixed profile for the separate
handles. Use `combined_gray.conf` or `combined_magnetic.conf` for the mascon.
Handle GPIO assignments, sensor channels and cam maps remain unchanged in Rev E. The old Rev C/D direct button/RGB overlay does not support the new STM32 panel; its firmware and main I²C integration remain required. See [button interface](../hardware/notchdeck-buttons/README.md).
The [interface guide](06-handle-interfaces.md#firmware-profiles-and-output) has the
build command and complete output/fault behavior.

On a mock-up, verify every detent and every transition in both directions. Check
Off/Release or N is required at startup, brake suppresses traction, and disconnecting
either active sensor eventually commands power off and EB. All-open Gray patterns
are invalid; individual broken/shorted wires can still resemble valid positions.
Measure magnetic margins and signal quality with the handles under load. Only
then freeze the panel openings, bearings, stops and spring settings.

Both PCB BOMs use JLCPCB catalog parts. The dated stock check covers five complete
sets, using owned private stock for the STM32 and public availability for the other
selections; see [sourcing](04-bom-sourcing.md). Mating housings/crimps, external AS5600 carrier boards, microload
switches, magnets and mechanical hardware are **not yet a sourced assembly kit**.
Their stock must be checked once those exact parts are selected; private inventory
can be used where available. No parts have been ordered.

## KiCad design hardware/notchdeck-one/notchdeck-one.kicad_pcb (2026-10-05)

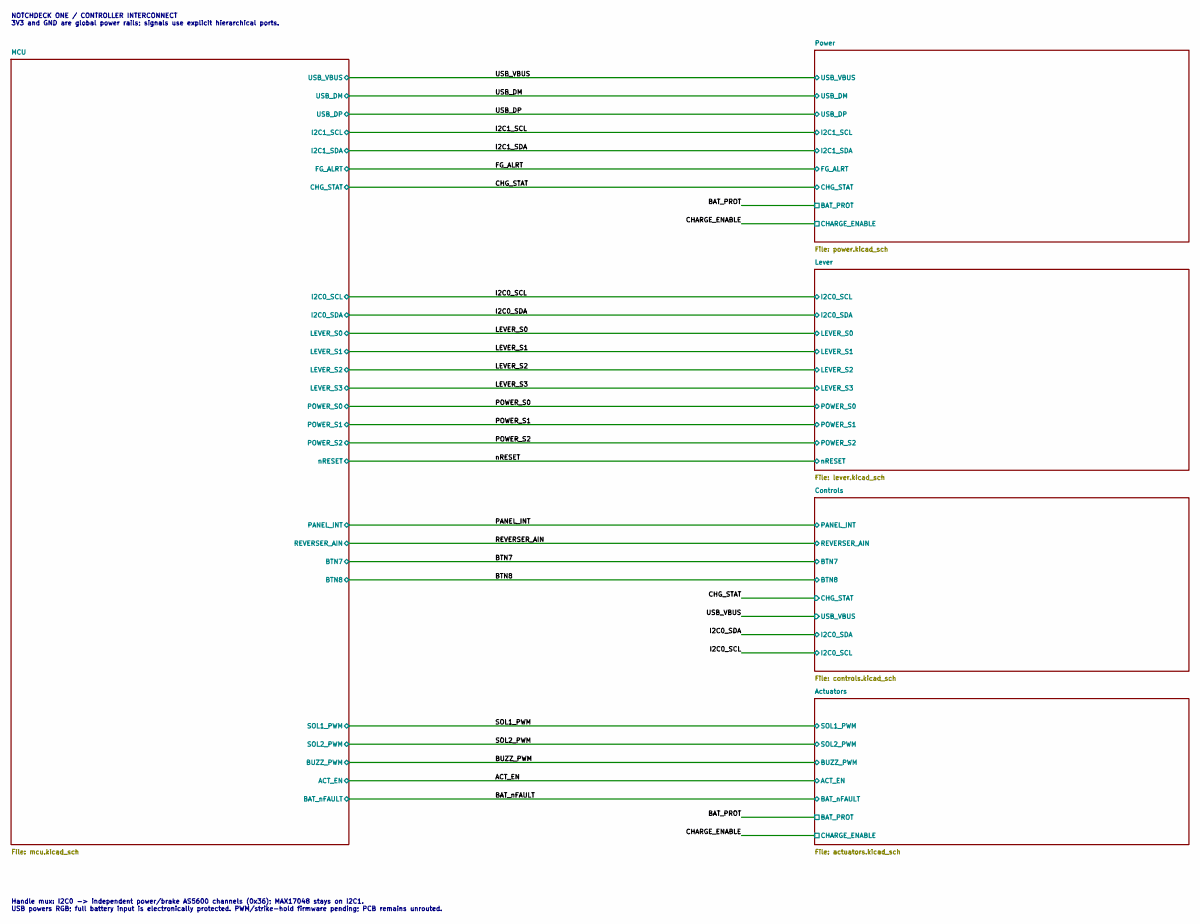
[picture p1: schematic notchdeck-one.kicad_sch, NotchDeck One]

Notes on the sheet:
NOTCHDECK ONE / CONTROLLER INTERCONNECT 3V3 and GND are global power rails; signals use explicit hierarchical ports.
Handle mux: I2C0 -> independent power/brake AS5600 channels (0x36); MAX17048 stays on I2C1. USB powers RGB; full battery input is electronically protected. PWM/strike-hold firmware pending; PCB remains unrouted.

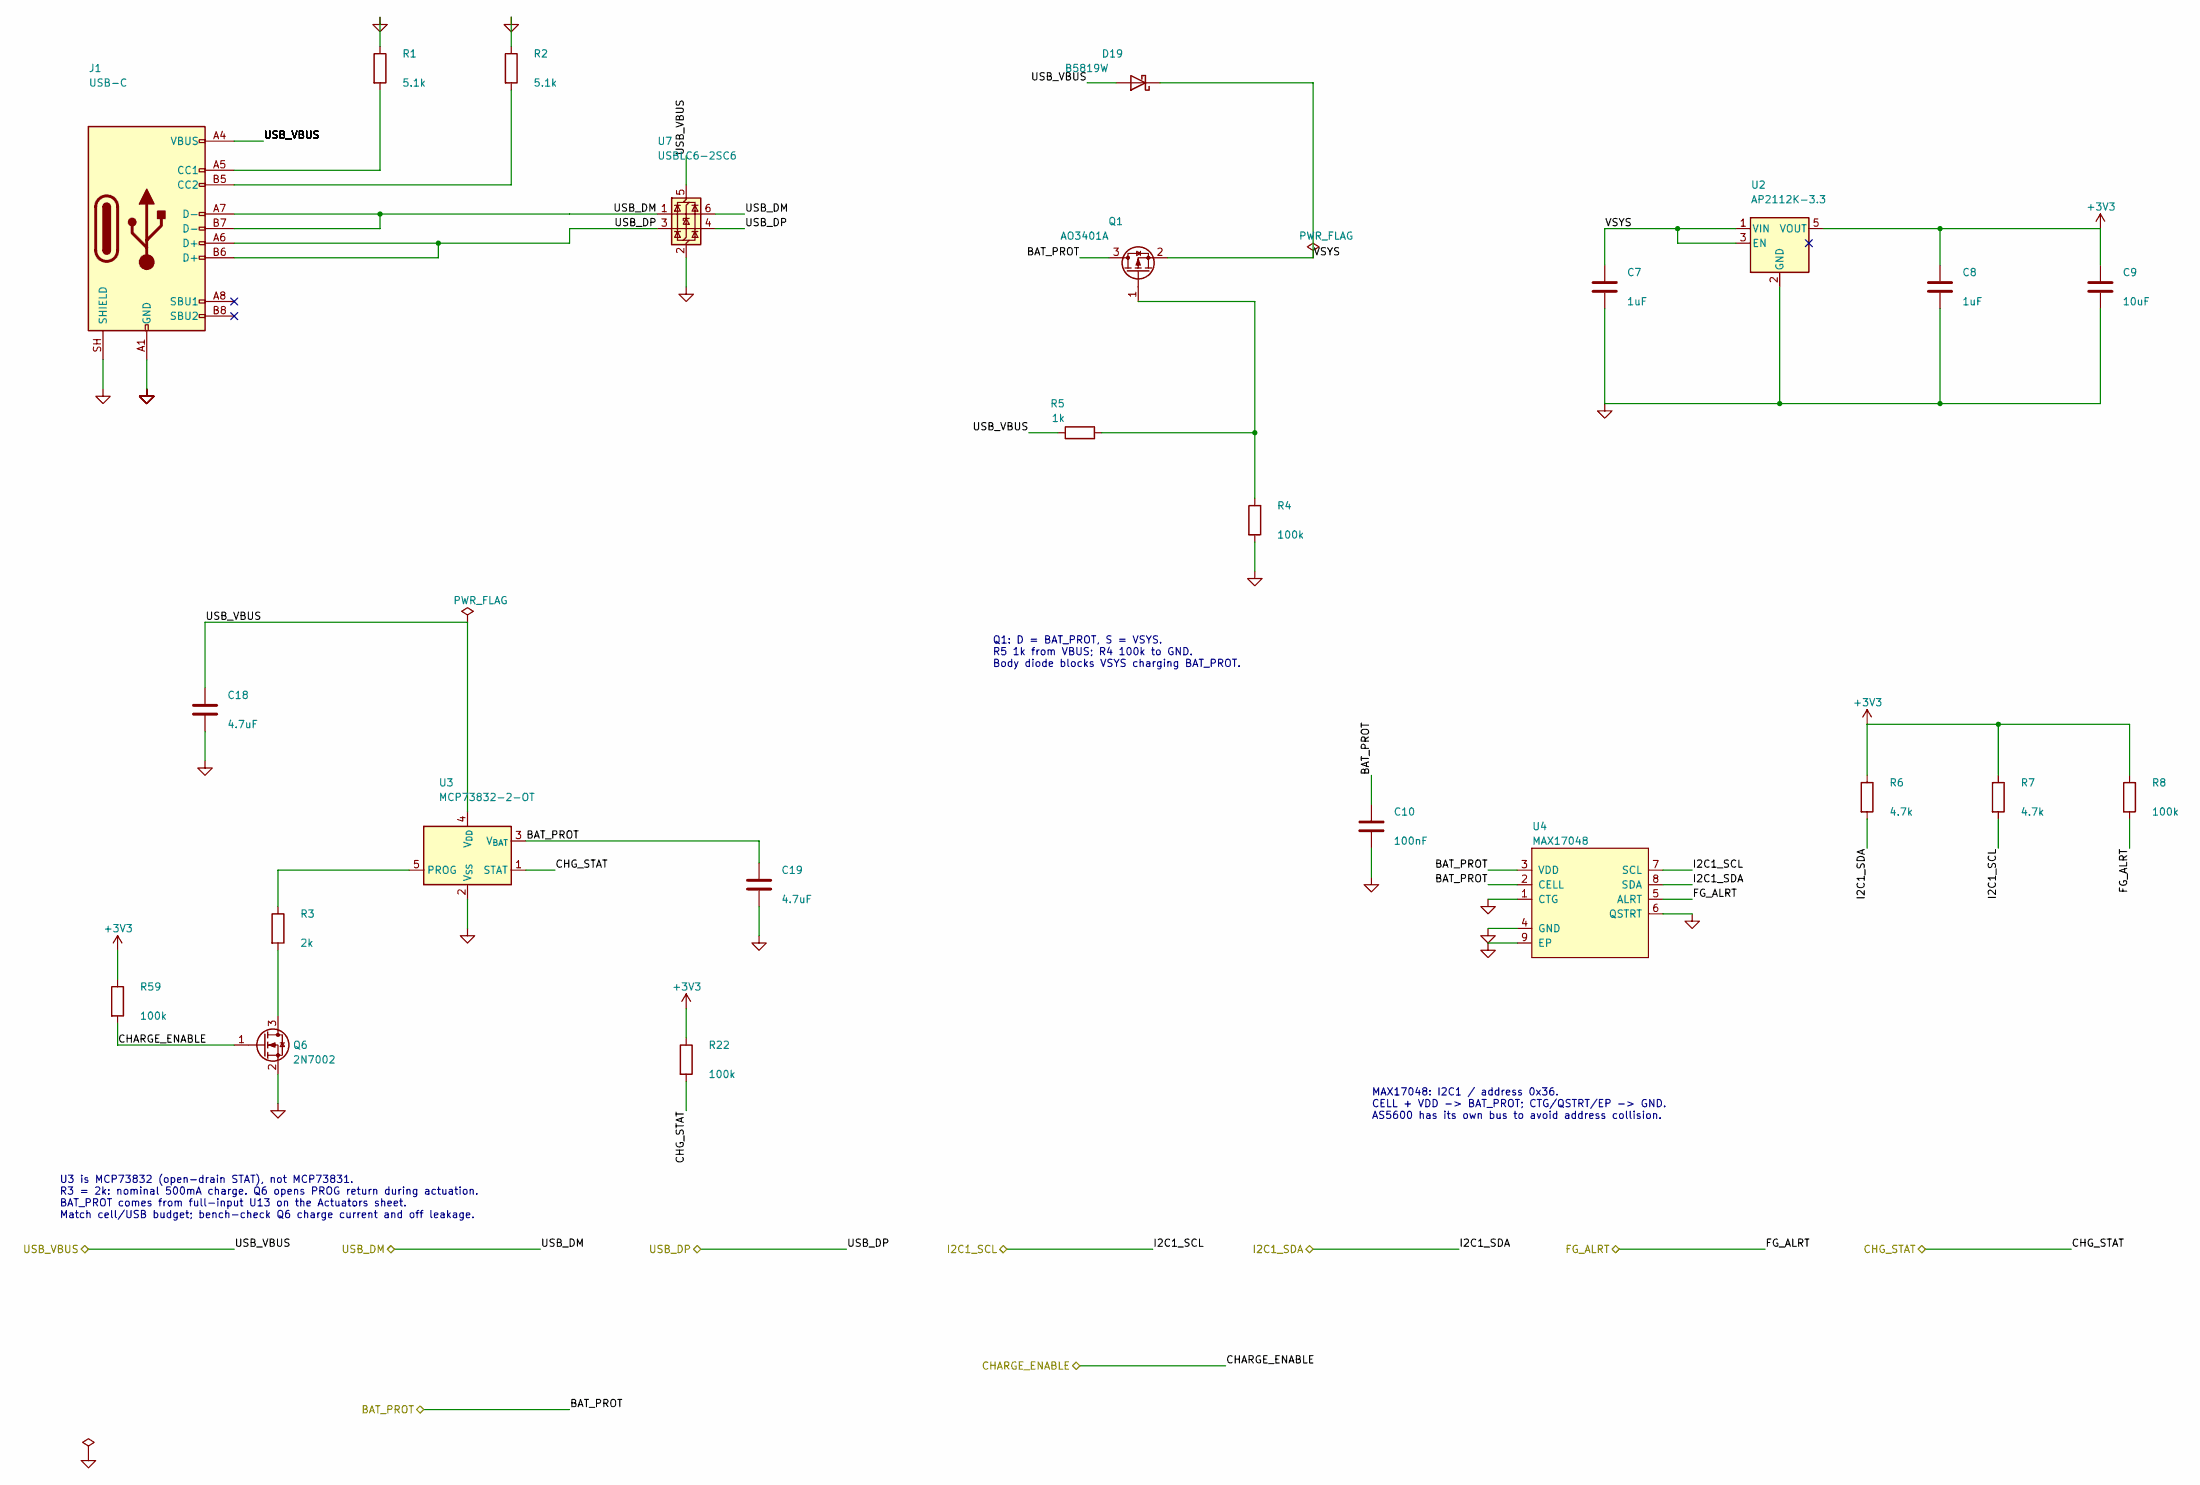
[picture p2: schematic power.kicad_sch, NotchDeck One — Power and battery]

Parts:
C7, C8: 1uF; C_0402_1005Metric; MPN CL05A105KA5NQNC; LCSC C52923
C9: 10uF; C_0805_2012Metric; MPN CL21A106KAYNNNE; LCSC C15850
C10: 100nF; C_0402_1005Metric; MPN CL05B104KO5NNNC; LCSC C1525
C18, C19: 4.7uF; C_0805_2012Metric; MPN CL21A475KAQNNNE; LCSC C1779
D19: B5819W; D_SOD-123; MPN B5819W SL; LCSC C8598
J1: USB-C; USB_C_Receptacle_HRO_TYPE-C-31-M-12; MPN TYPE-C-31-M-12; LCSC C165948
Q1: AO3401A; SOT-23; MPN AO3401A; LCSC C15127
Q6: 2N7002; SOT-23; MPN 2N7002; LCSC C8545
R1, R2: 5.1k; R_0402_1005Metric; MPN 0402WGF5101TCE; LCSC C25905
R3: 2k; R_0402_1005Metric; MPN 0402WGF2001TCE; LCSC C4109
R4, R8, R22, R59: 100k; R_0402_1005Metric; MPN 0402WGF1003TCE; LCSC C25741
R5: 1k; R_0402_1005Metric; MPN 0402WGF1001TCE; LCSC C11702
R6, R7: 4.7k; R_0402_1005Metric; MPN 0402WGF4701TCE; LCSC C25900
U2: AP2112K-3.3; SOT-23-5; MPN AP2112K-3.3TRG1; LCSC C51118
U3: MCP73832-2-OT; SOT-23-5; MPN MCP73832T-2ACI/OT; LCSC C38066
U4: MAX17048; TDFN-8-1EP_2x2mm_P0.5mm_EP0.8x1.2mm; MPN MAX17048G+T10; LCSC C2682616
U7: USBLC6-2SC6; SOT-23-6; MPN USBLC6-2SC6; LCSC C7519

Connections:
+3V3: C8.1, C9.1, R6.1, R7.1, R8.1, R22.1, R59.1, U2.5 (VOUT); also elsewhere on the board
/BAT_PROT: C10.1, C19.1, Q1.3 (D), U3.3 (V_{BAT}), U4.2 (CELL), U4.3 (VDD); also elsewhere on the board
/CHARGE_ENABLE: Q6.1 (G), R59.2; also elsewhere on the board
/CHG_STAT: R22.2, U3.1 (STAT); also elsewhere on the board
/FG_ALRT: R8.2, U4.5 (ALRT); also elsewhere on the board
/I2C1_SCL: R7.2, U4.7 (SCL); also elsewhere on the board
/I2C1_SDA: R6.2, U4.8 (SDA); also elsewhere on the board
/USB_DM: J1.A7 (D-), J1.B7 (D-), U7.1 (I/O1), U7.6 (I/O1); also elsewhere on the board
/USB_DP: J1.A6 (D+), J1.B6 (D+), U7.3 (I/O2), U7.4 (I/O2); also elsewhere on the board
unnamed: J1.A5 (CC1), R1.2
unnamed: J1.B5 (CC2), R2.2
unnamed: Q1.1 (G), R4.1, R5.2
unnamed: Q6.3 (D), R3.2
unnamed: R3.1, U3.5 (PROG)

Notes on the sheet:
Q1: D = BAT_PROT, S = VSYS. R5 1k from VBUS; R4 100k to GND. Body diode blocks VSYS charging BAT_PROT.
U3 is MCP73832 (open-drain STAT), not MCP73831. R3 = 2k: nominal 500mA charge. Q6 opens PROG return during actuation. BAT_PROT comes from full-input U13 on the Actuators sheet. Match cell/USB budget; bench-check Q6 charge current and off leakage.
MAX17048: I2C1 / address 0x36. CELL + VDD -> BAT_PROT; CTG/QSTRT/EP -> GND. AS5600 has its own bus to avoid address collision.

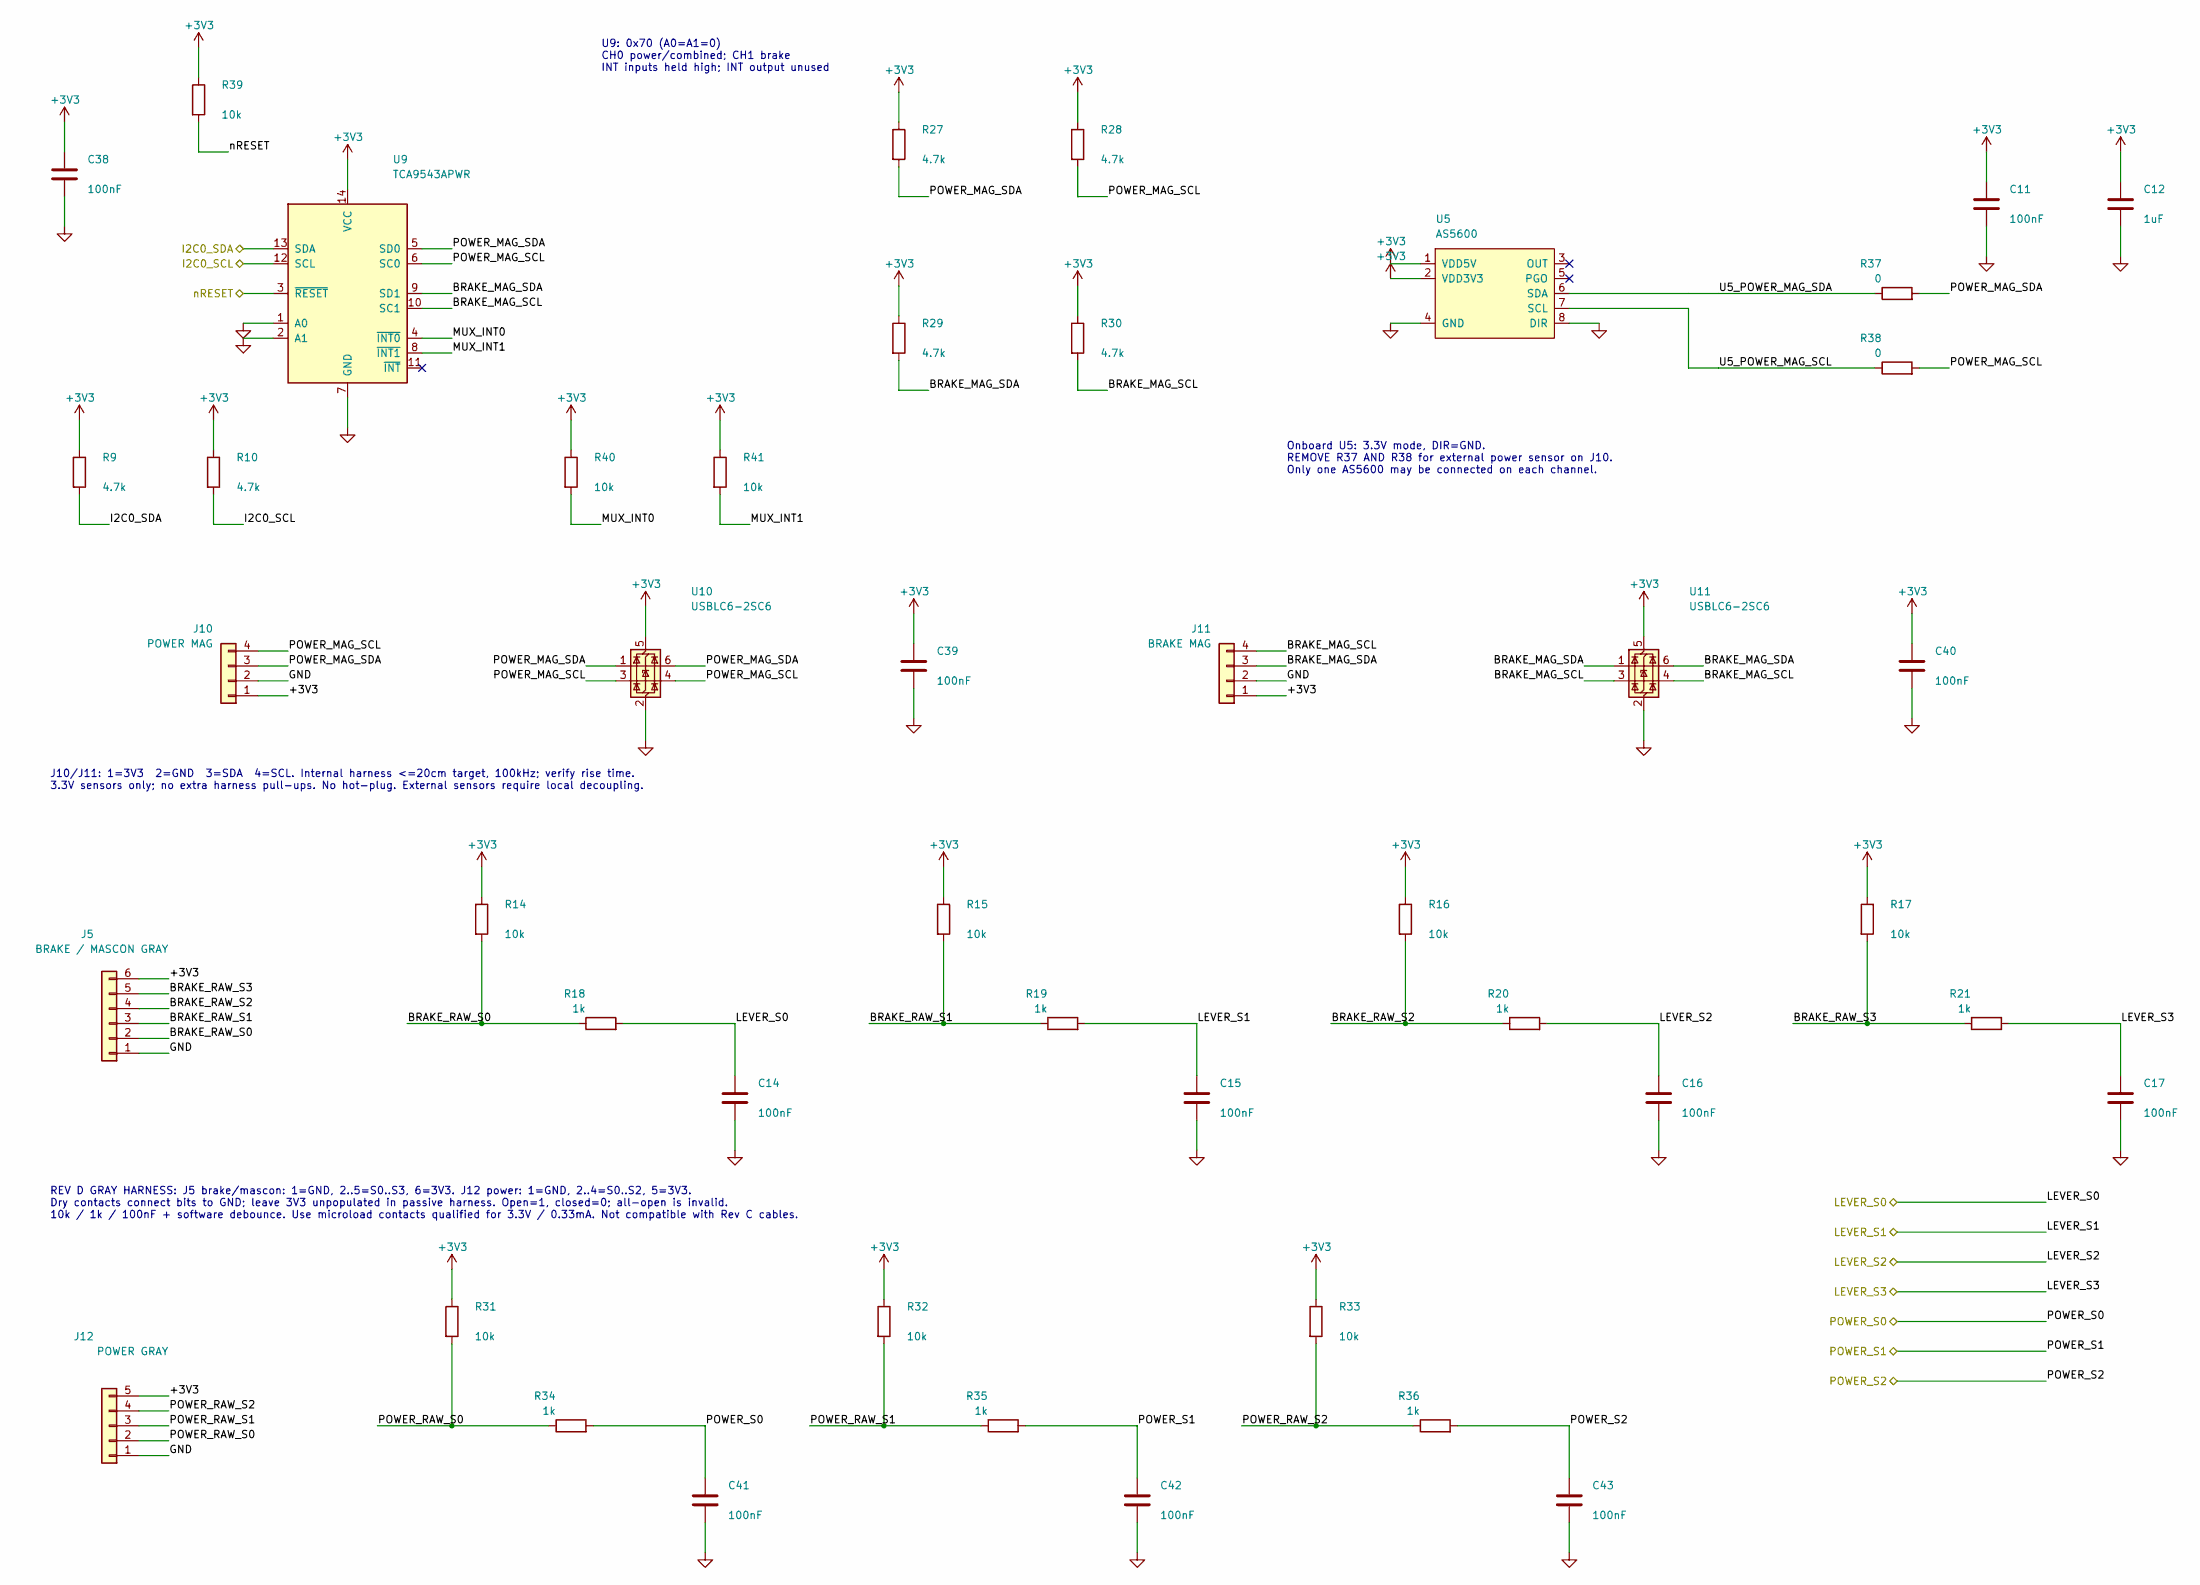
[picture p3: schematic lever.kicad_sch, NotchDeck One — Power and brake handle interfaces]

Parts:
C11, C14, C15, C16, C17, C38, C39, C40, C41, C42, C43: 100nF; C_0402_1005Metric; MPN CL05B104KO5NNNC; LCSC C1525
C12: 1uF; C_0402_1005Metric; MPN CL05A105KA5NQNC; LCSC C52923
J5: BRAKE / MASCON GRAY; JST_PH_S6B-PH-SM4-TB_1x06-1MP_P2.00mm_Horizontal; MPN S6B-PH-SM4-TB(LF)(SN); LCSC C265405
J10: POWER MAG; JST_PH_S4B-PH-SM4-TB_1x04-1MP_P2.00mm_Horizontal; MPN S4B-PH-SM4-TB(LF)(SN); LCSC C265102
J11: BRAKE MAG; JST_PH_S4B-PH-SM4-TB_1x04-1MP_P2.00mm_Horizontal; MPN S4B-PH-SM4-TB(LF)(SN); LCSC C265102
J12: POWER GRAY; JST_PH_S5B-PH-SM4-TB_1x05-1MP_P2.00mm_Horizontal; MPN S5B-PH-SM4-TB(LF)(SN); LCSC C265104
R9, R10, R27, R28, R29, R30: 4.7k; R_0402_1005Metric; MPN 0402WGF4701TCE; LCSC C25900
R14, R15, R16, R17, R31, R32, R33, R39, R40, R41: 10k; R_0402_1005Metric; MPN 0402WGF1002TCE; LCSC C25744
R18, R19, R20, R21, R34, R35, R36: 1k; R_0402_1005Metric; MPN 0402WGF1001TCE; LCSC C11702
R37, R38: 0; R_0603_1608Metric; MPN 0603WAF0000T5E; LCSC C21189
U5: AS5600; SOIC-8_3.9x4.9mm_P1.27mm; MPN AS5600-ASOT; LCSC C499458
U9: TCA9543APWR; TSSOP-14_4.4x5mm_P0.65mm; MPN TCA9543APWR; LCSC C2653307
U10, U11: USBLC6-2SC6; SOT-23-6; MPN USBLC6-2SC6; LCSC C7519

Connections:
+3V3: C11.1, C12.1, C38.1, C39.1, C40.1, J5.6, J10.1, J11.1, J12.5, R9.1, R10.1, R14.1, R15.1, R16.1, R17.1, R27.1, R28.1, R29.1, R30.1, R31.1, R32.1, R33.1, R39.1, R40.1, R41.1, U5.1 (VDD5V), U5.2 (VDD3V3), U9.14 (VCC), U10.5 (VBUS), U11.5 (VBUS); also elsewhere on the board
/I2C0_SCL: R10.2, U9.12 (SCL); also elsewhere on the board
/I2C0_SDA: R9.2, U9.13 (SDA); also elsewhere on the board
/LEVER_S0: C14.1, R18.2; also elsewhere on the board
/LEVER_S1: C15.1, R19.2; also elsewhere on the board
/LEVER_S2: C16.1, R20.2; also elsewhere on the board
/LEVER_S3: C17.1, R21.2; also elsewhere on the board
/Lever/BRAKE_MAG_SCL: J11.4, R30.2, U9.10 (SC1), U11.3 (I/O2), U11.4 (I/O2)
/Lever/BRAKE_MAG_SDA: J11.3, R29.2, U9.9 (SD1), U11.1 (I/O1), U11.6 (I/O1)
/Lever/BRAKE_RAW_S0: J5.2, R14.2, R18.1
/Lever/BRAKE_RAW_S1: J5.3, R15.2, R19.1
/Lever/BRAKE_RAW_S2: J5.4, R16.2, R20.1
/Lever/BRAKE_RAW_S3: J5.5, R17.2, R21.1
/Lever/MUX_INT0: R40.2, U9.4 (~INT0)
/Lever/MUX_INT1: R41.2, U9.8 (~INT1)
/Lever/POWER_MAG_SCL: J10.4, R28.2, R38.2, U9.6 (SC0), U10.3 (I/O2), U10.4 (I/O2)
/Lever/POWER_MAG_SDA: J10.3, R27.2, R37.2, U9.5 (SD0), U10.1 (I/O1), U10.6 (I/O1)
/Lever/POWER_RAW_S0: J12.2, R31.2, R34.1
/Lever/POWER_RAW_S1: J12.3, R32.2, R35.1
/Lever/POWER_RAW_S2: J12.4, R33.2, R36.1
/Lever/U5_POWER_MAG_SCL: R38.1, U5.7 (SCL)
/Lever/U5_POWER_MAG_SDA: R37.1, U5.6 (SDA)
/POWER_S0: C41.1, R34.2; also elsewhere on the board
/POWER_S1: C42.1, R35.2; also elsewhere on the board
/POWER_S2: C43.1, R36.2; also elsewhere on the board
/nRESET: R39.2, U9.3 (~RESET); also elsewhere on the board

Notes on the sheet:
U9: 0x70 (A0=A1=0) CH0 power/combined; CH1 brake INT inputs held high; INT output unused
Onboard U5: 3.3V mode, DIR=GND. REMOVE R37 AND R38 for external power sensor on J10. Only one AS5600 may be connected on each channel.
J10/J11: 1=3V3 2=GND 3=SDA 4=SCL. Internal harness <=20cm target, 100kHz; verify rise time. 3.3V sensors only; no extra harness pull-ups. No hot-plug. External sensors require local decoupling.
REV D GRAY HARNESS: J5 brake/mascon: 1=GND, 2..5=S0..S3, 6=3V3. J12 power: 1=GND, 2..4=S0..S2, 5=3V3. Dry contacts connect bits to GND; leave 3V3 unpopulated in passive harness. Open=1, closed=0; all-open is invalid. 10k / 1k / 100nF + software debounce. Use microload contacts qualified for 3.3V / 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

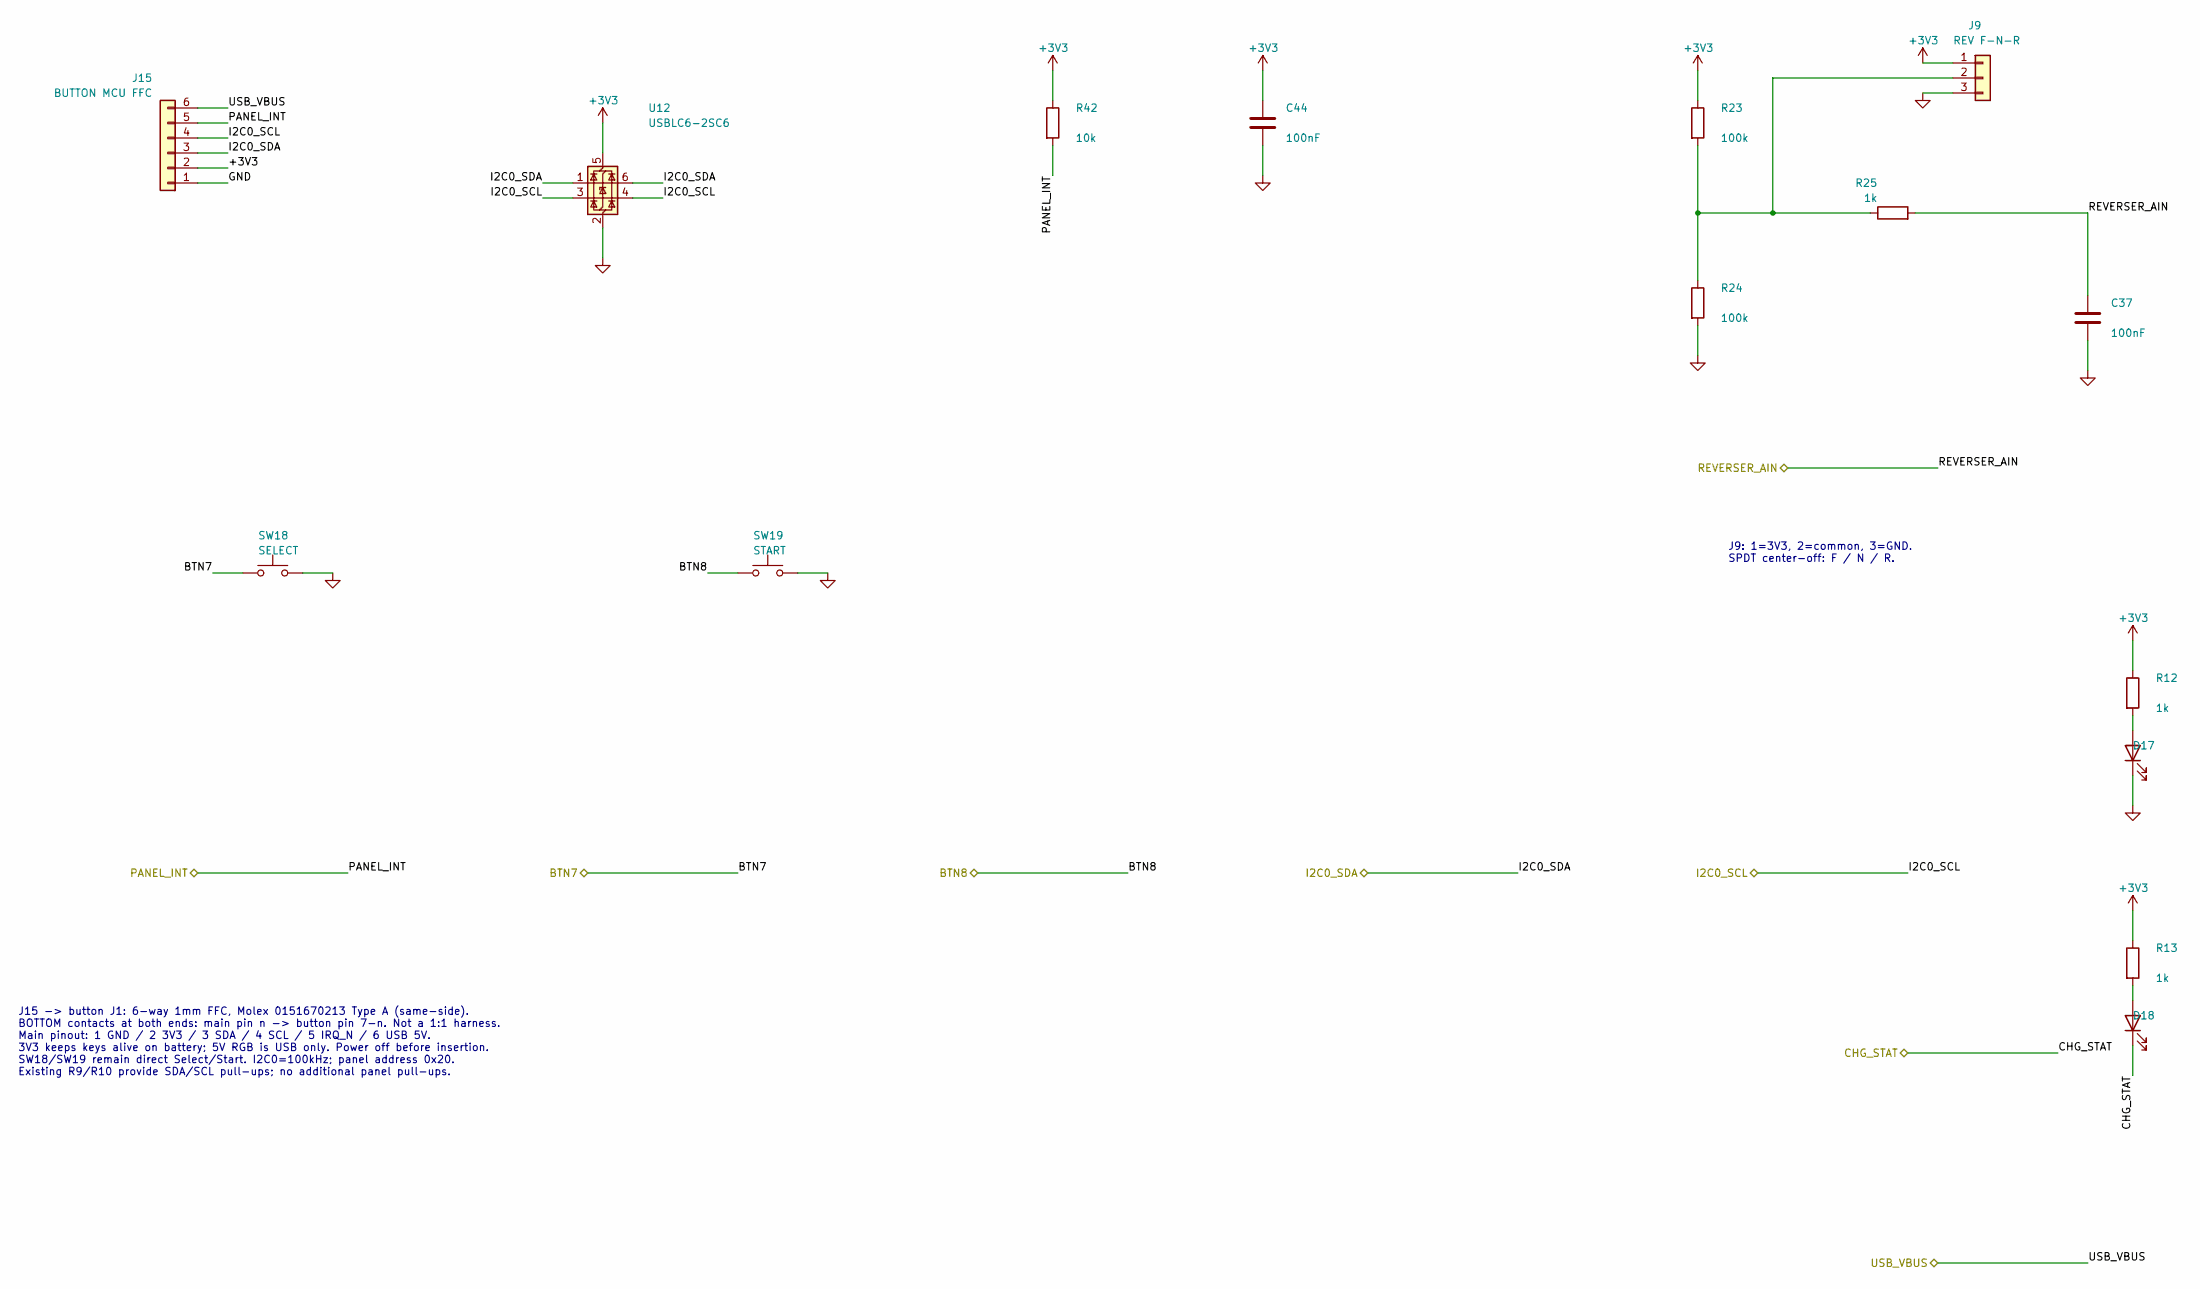
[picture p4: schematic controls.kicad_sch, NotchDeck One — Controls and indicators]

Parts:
C37, C44: 100nF; C_0402_1005Metric; MPN CL05B104KO5NNNC; LCSC C1525
D17: LED; LED_0603_1608Metric; MPN XL-1608SYGC-06; LCSC C965805
D18: LED; LED_0603_1608Metric; MPN KT-0603R; LCSC C2286
J9: REV F-N-R; JST_PH_S3B-PH-SM4-TB_1x03-1MP_P2.00mm_Horizontal; MPN S3B-PH-SM4-TB(LF)(SN); LCSC C265101
J15: BUTTON MCU FFC; JUSHUO_AFA07-S06FCA-00_1x6-1MP_P1.0mm_Horizontal; MPN AFA07-S06FCA-00; LCSC C262712
R12, R13, R25: 1k; R_0402_1005Metric; MPN 0402WGF1001TCE; LCSC C11702
R23, R24: 100k; R_0402_1005Metric; MPN 0402WGF1003TCE; LCSC C25741
R42: 10k; R_0402_1005Metric; MPN 0402WGF1002TCE; LCSC C25744
SW18: SELECT; SW_Push_1P1T_XKB_TS-1187A; MPN TS-1187A-B-A-B; LCSC C318884
SW19: START; SW_Push_1P1T_XKB_TS-1187A; MPN TS-1187A-B-A-B; LCSC C318884
U12: USBLC6-2SC6; SOT-23-6; MPN USBLC6-2SC6; LCSC C7519

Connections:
+3V3: C44.1, J9.1, J15.2, R12.1, R13.1, R23.1, R42.1, U12.5 (VBUS); also elsewhere on the board
/BTN7: SW18.1; also elsewhere on the board
/BTN8: SW19.1; also elsewhere on the board
/CHG_STAT: D18.1 (K); also elsewhere on the board
/I2C0_SCL: J15.4, U12.3 (I/O2), U12.4 (I/O2); also elsewhere on the board
/I2C0_SDA: J15.3, U12.1 (I/O1), U12.6 (I/O1); also elsewhere on the board
/PANEL_INT: J15.5, R42.2; also elsewhere on the board
/REVERSER_AIN: C37.1, R25.2; also elsewhere on the board
unnamed: D17.2 (A), R12.2
unnamed: D18.2 (A), R13.2
unnamed: J9.2, R23.2, R24.1, R25.1

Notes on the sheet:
J15 -> button J1: 6-way 1mm FFC, Molex 0151670213 Type A (same-side). BOTTOM contacts at both ends: main pin n -> button pin 7-n. Not a 1:1 harness. Main pinout: 1 GND / 2 3V3 / 3 SDA / 4 SCL / 5 IRQ_N / 6 USB 5V. 3V3 keeps keys alive on battery; 5V RGB is USB only. Power off before insertion. SW18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
J9: 1=3V3, 2=common, 3=GND. SPDT center-off: F / N / R.

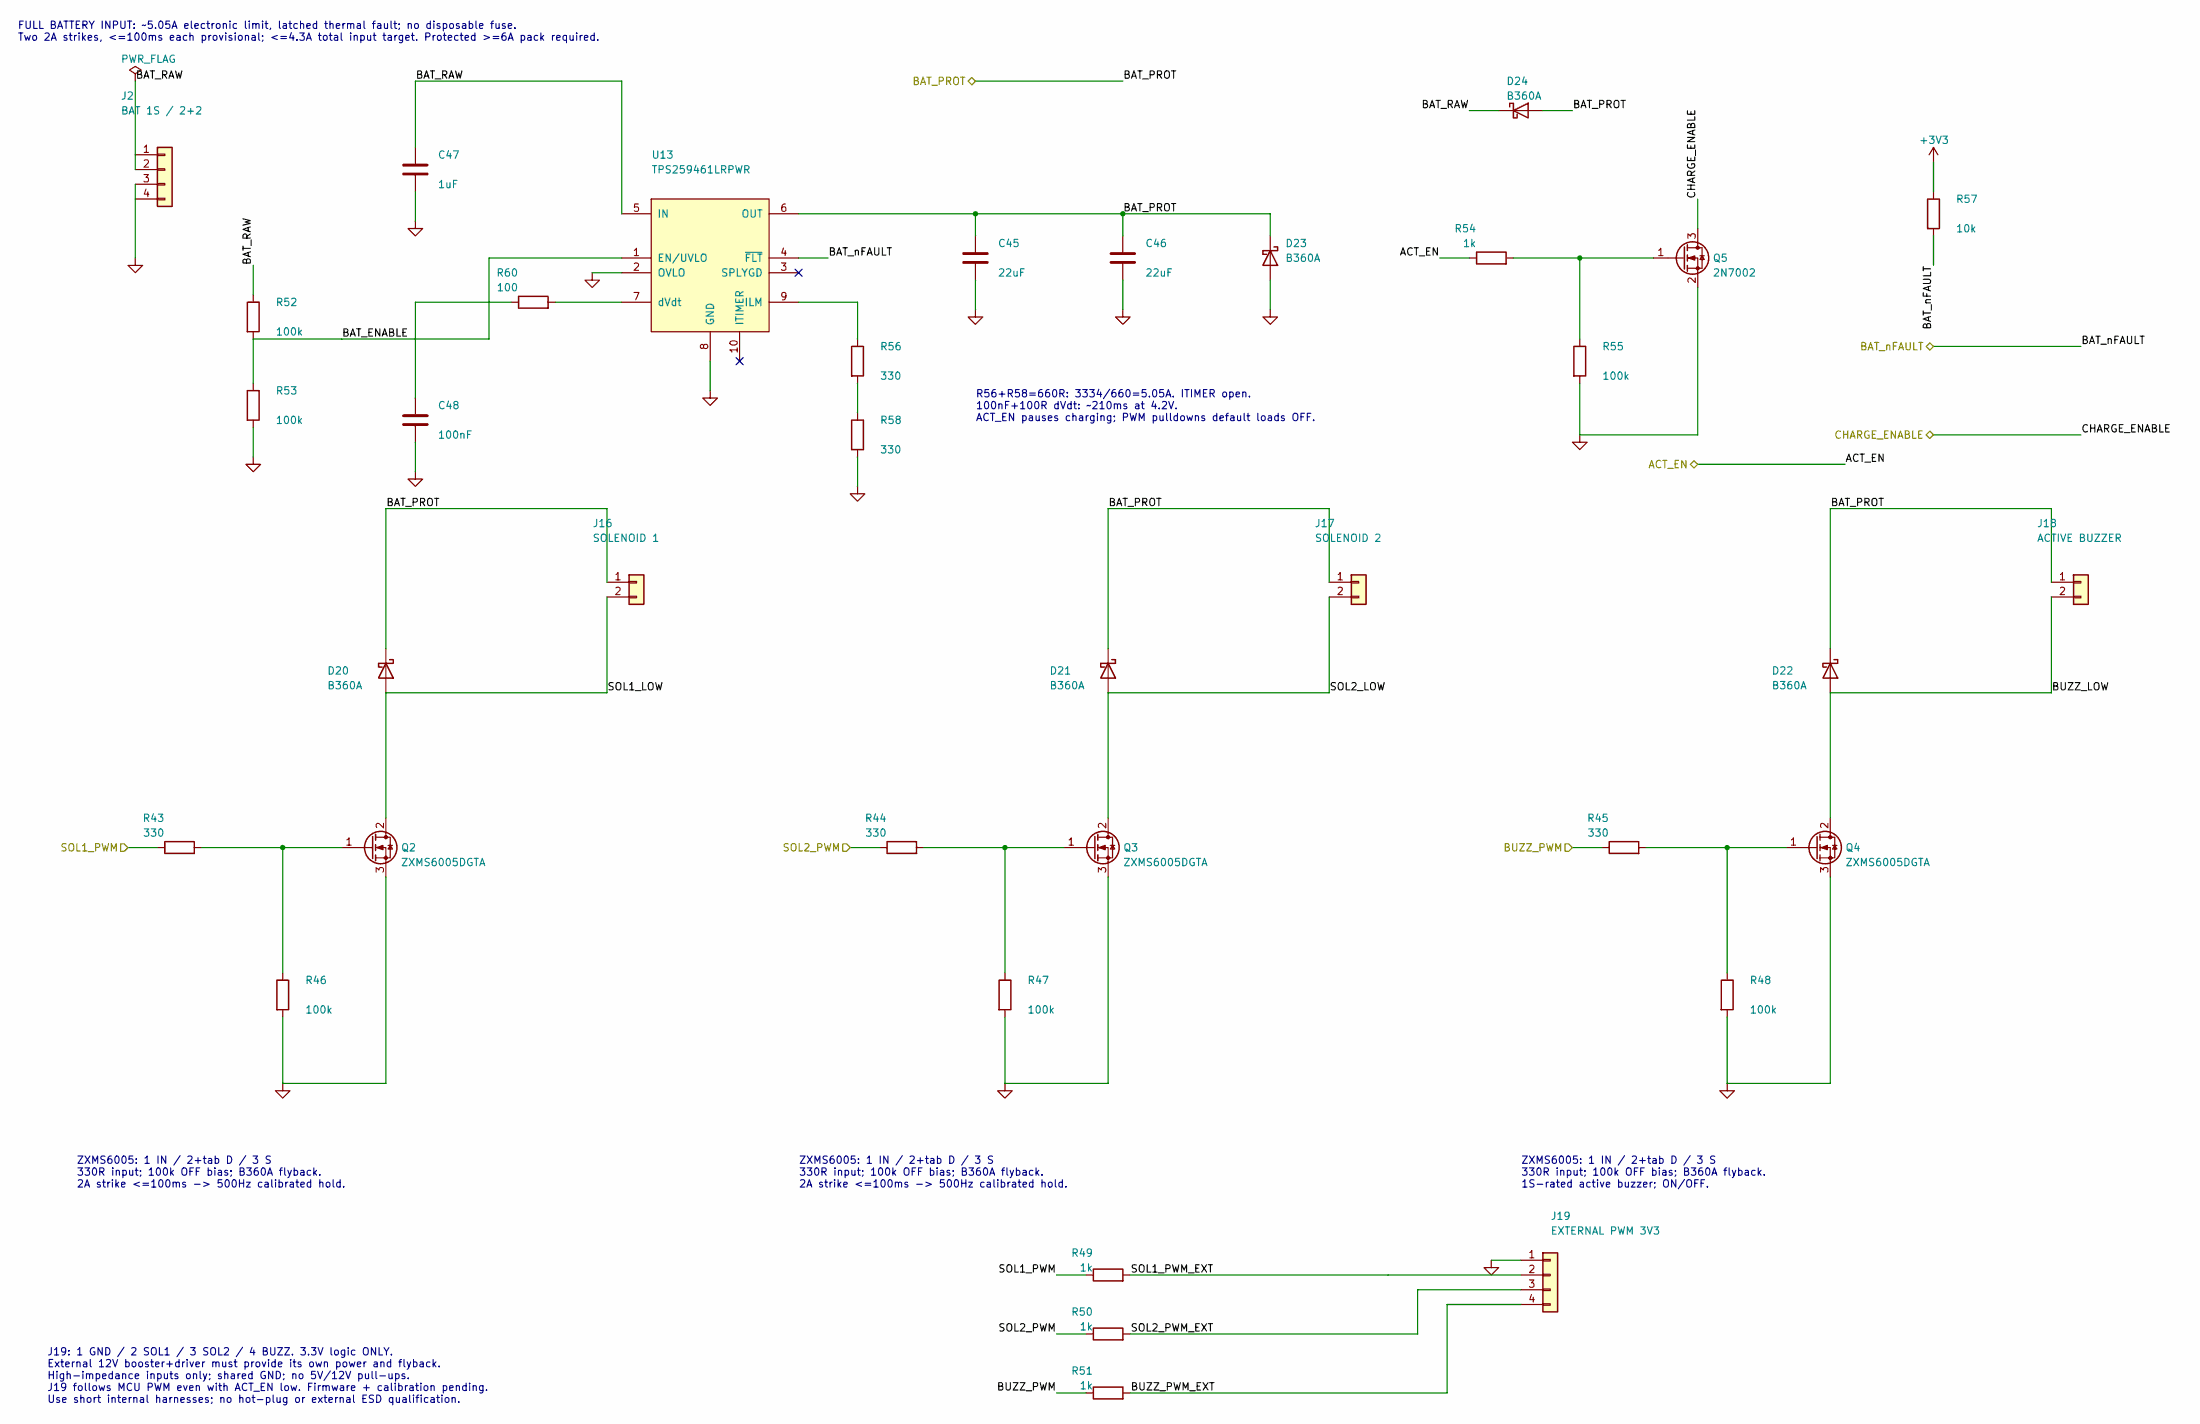
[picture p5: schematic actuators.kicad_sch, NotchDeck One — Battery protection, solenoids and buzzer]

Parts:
C45, C46: 22uF; C_1210_3225Metric; MPN CL32B226KAJNNNE; LCSC C309062
C47: 1uF; C_0402_1005Metric; MPN CL05A105KA5NQNC; LCSC C52923
C48: 100nF; C_0402_1005Metric; MPN CL05B104KO5NNNC; LCSC C1525
D20, D21, D22, D23, D24: B360A; D_SMA; MPN B360A; LCSC C6807778
J2: BAT 1S / 2+2; Molex_Micro-Fit_3.0_43045-0400_2x02_P3.00mm_Horizontal; MPN 430450401; LCSC C585880
J16: SOLENOID 1; JST_PH_S2B-PH-SM4-TB_1x02-1MP_P2.00mm_Horizontal; MPN S2B-PH-SM4-TB(LF)(SN); LCSC C295747
J17: SOLENOID 2; JST_PH_S2B-PH-SM4-TB_1x02-1MP_P2.00mm_Horizontal; MPN S2B-PH-SM4-TB(LF)(SN); LCSC C295747
J18: ACTIVE BUZZER; JST_PH_S2B-PH-SM4-TB_1x02-1MP_P2.00mm_Horizontal; MPN S2B-PH-SM4-TB(LF)(SN); LCSC C295747
J19: EXTERNAL PWM 3V3; JST_PH_S4B-PH-SM4-TB_1x04-1MP_P2.00mm_Horizontal; MPN S4B-PH-SM4-TB(LF)(SN); LCSC C265102
Q2, Q3, Q4: ZXMS6005DGTA; SOT-223-3_TabPin2; MPN ZXMS6005DGTA; LCSC C174045
Q5: 2N7002; SOT-23; MPN 2N7002; LCSC C8545
R43, R44, R45, R56, R58: 330; R_0402_1005Metric; MPN 0402WGF3300TCE; LCSC C25104
R46, R47, R48, R52, R53, R55: 100k; R_0402_1005Metric; MPN 0402WGF1003TCE; LCSC C25741
R49, R50, R51, R54: 1k; R_0402_1005Metric; MPN 0402WGF1001TCE; LCSC C11702
R57: 10k; R_0402_1005Metric; MPN 0402WGF1002TCE; LCSC C25744
R60: 100; R_0603_1608Metric; MPN 0603WAF1000T5E; LCSC C22775
U13: TPS259461LRPWR; TI_RPW0010A; MPN TPS259461LRPWR; LCSC C3662776

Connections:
+3V3: R57.1; also elsewhere on the board
/ACT_EN: R54.1; also elsewhere on the board
/Actuators/BAT_ENABLE: R52.2, R53.1, U13.1 (EN/UVLO)
/Actuators/BAT_RAW: C47.1, D24.1 (K), J2.1, J2.2, R52.1, U13.5 (IN)
/Actuators/BUZZ_LOW: D22.2 (A), J18.2, Q4.2 (D)
/Actuators/BUZZ_PWM_EXT: J19.4, R51.2
/Actuators/SOL1_LOW: D20.2 (A), J16.2, Q2.2 (D)
/Actuators/SOL1_PWM_EXT: J19.2, R49.2
/Actuators/SOL2_LOW: D21.2 (A), J17.2, Q3.2 (D)
/Actuators/SOL2_PWM_EXT: J19.3, R50.2
/BAT_PROT: C45.1, C46.1, D20.1 (K), D21.1 (K), D22.1 (K), D23.1 (K), D24.2 (A), J16.1, J17.1, J18.1, U13.6 (OUT); also elsewhere on the board
/BAT_nFAULT: R57.2, U13.4 (~FLT); also elsewhere on the board
/BUZZ_PWM: R45.1, R51.1; also elsewhere on the board
/CHARGE_ENABLE: Q5.3 (D); also elsewhere on the board
/SOL1_PWM: R43.1, R49.1; also elsewhere on the board
/SOL2_PWM: R44.1, R50.1; also elsewhere on the board
unnamed: C48.1, R60.1
unnamed: Q2.1 (G), R43.2, R46.1
unnamed: Q3.1 (G), R44.2, R47.1
unnamed: Q4.1 (G), R45.2, R48.1
unnamed: Q5.1 (G), R54.2, R55.1
unnamed: R56.2, R58.1
unnamed: R56.1, U13.9 (ILM)
unnamed: R60.2, U13.7 (dVdt)

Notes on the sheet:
FULL BATTERY INPUT: ~5.05A electronic limit, latched thermal fault; no disposable fuse. Two 2A strikes, <=100ms each provisional; <=4.3A total input target. Protected >=6A pack required.
R56+R58=660R: 3334/660=5.05A. ITIMER open. 100nF+100R dVdt: ~210ms at 4.2V. ACT_EN pauses charging; PWM pulldowns default loads OFF.
ZXMS6005: 1 IN / 2+tab D / 3 S 330R input; 100k OFF bias; B360A flyback. 2A strike <=100ms -> 500Hz calibrated hold.
ZXMS6005: 1 IN / 2+tab D / 3 S 330R input; 100k OFF bias; B360A flyback. 1S-rated active buzzer; ON/OFF.
J19: 1 GND / 2 SOL1 / 3 SOL2 / 4 BUZZ. 3.3V logic ONLY. External 12V booster+driver must provide its own power and flyback. High-impedance inputs only; shared GND; no 5V/12V pull-ups. J19 follows MCU PWM even with ACT_EN low. Firmware + calibration pending. Use short internal harnesses; no hot-plug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

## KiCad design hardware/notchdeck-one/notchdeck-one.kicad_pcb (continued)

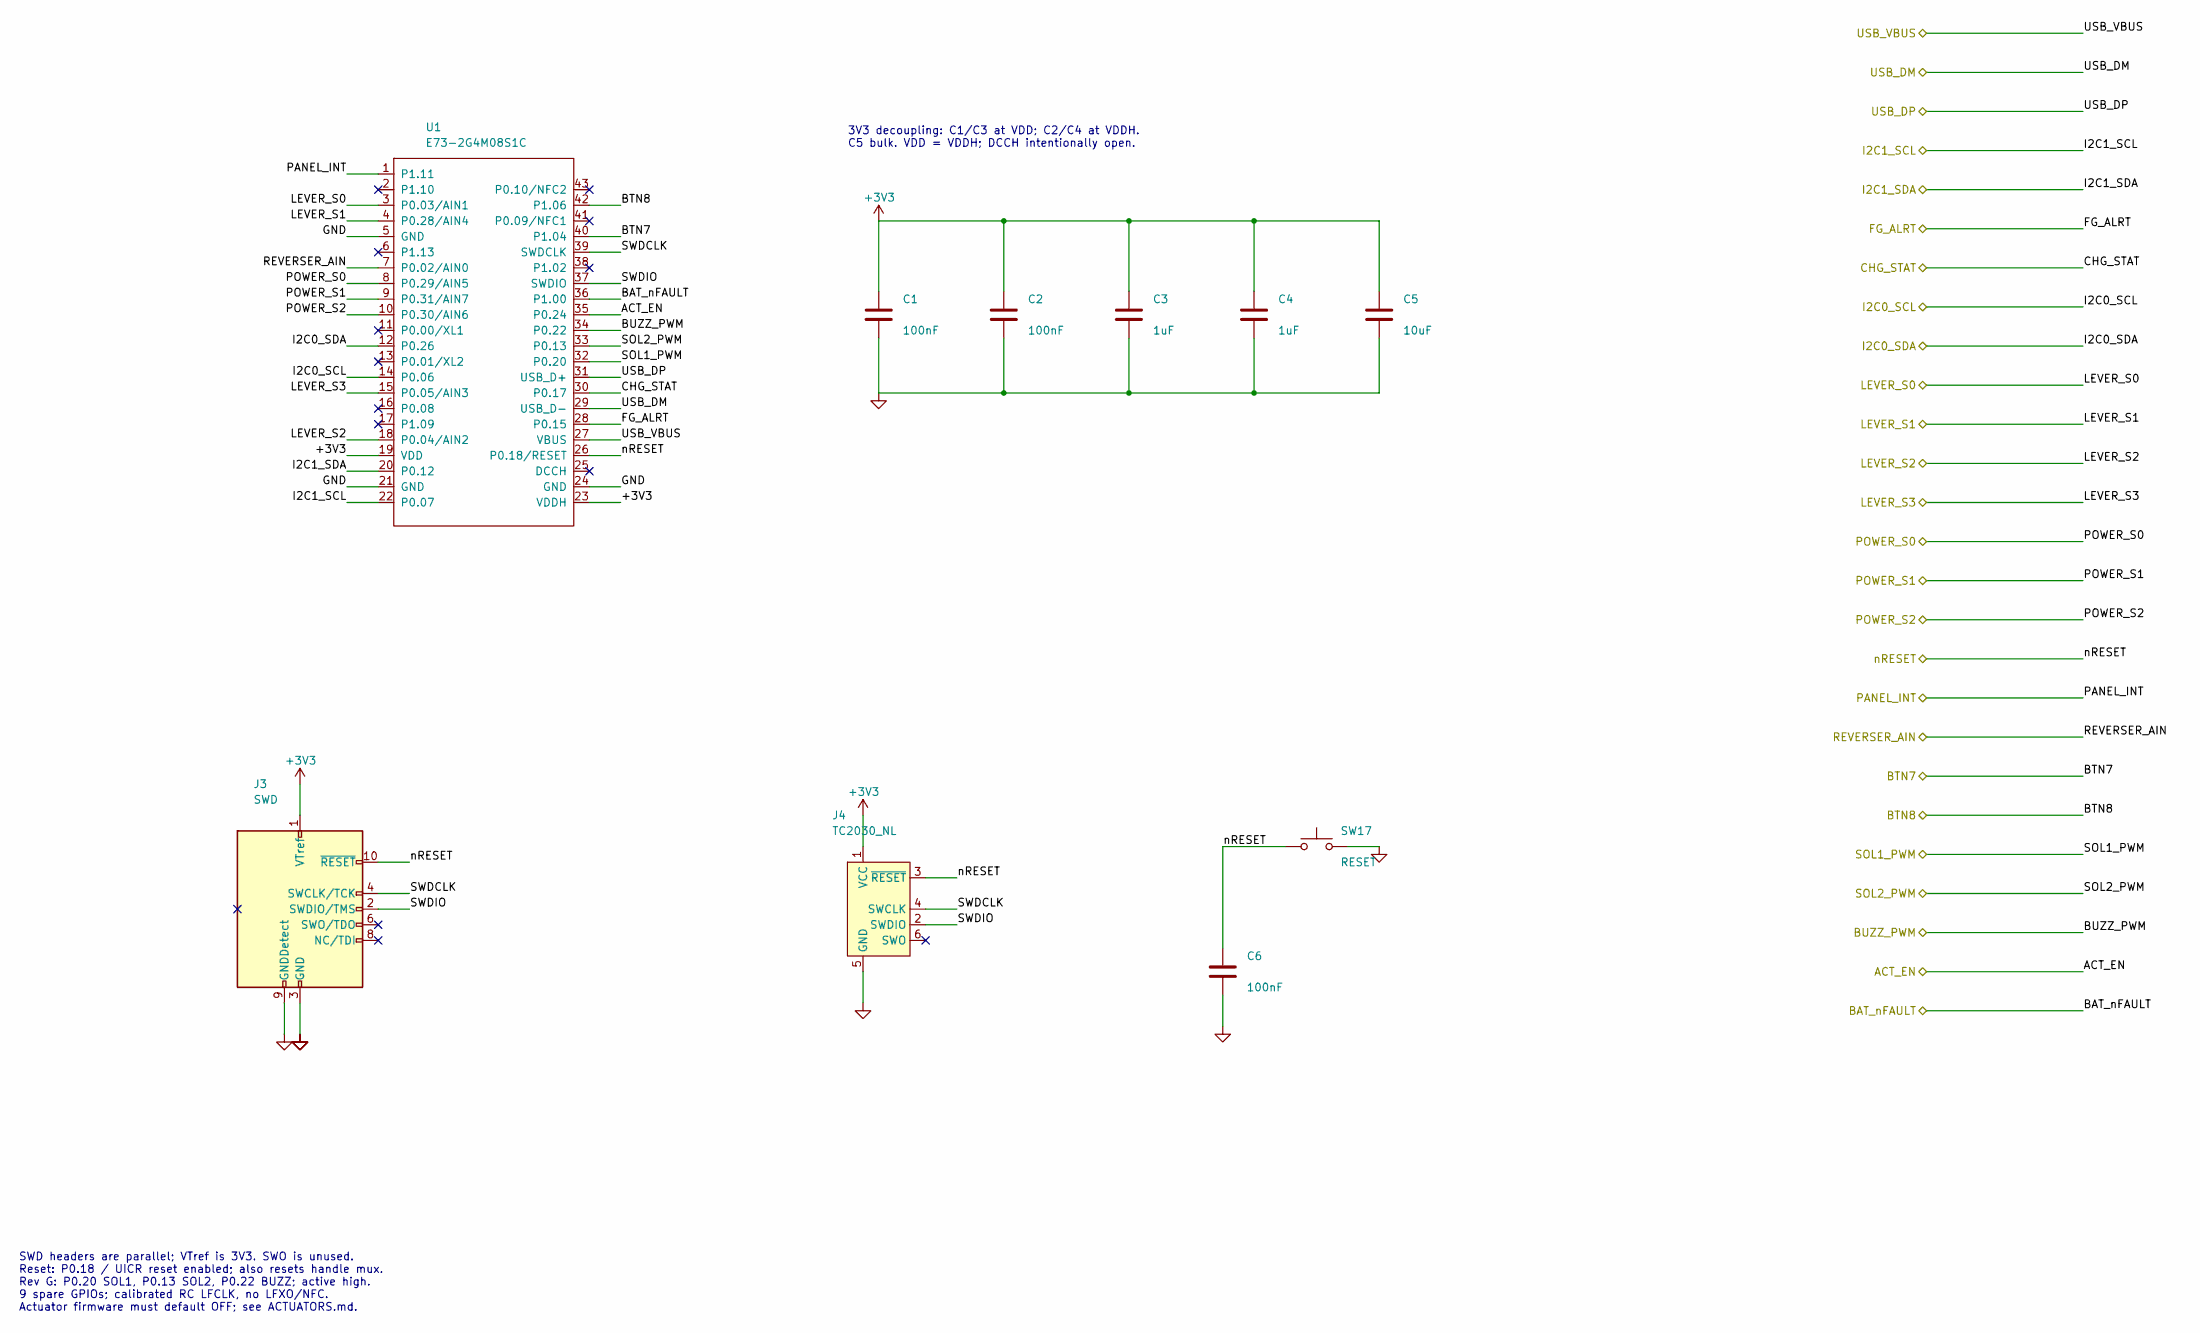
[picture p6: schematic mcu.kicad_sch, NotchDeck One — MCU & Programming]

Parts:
C1, C2, C6: 100nF; C_0402_1005Metric; MPN CL05B104KO5NNNC; LCSC C1525
C3, C4: 1uF; C_0402_1005Metric; MPN CL05A105KA5NQNC; LCSC C52923
C5: 10uF; C_0805_2012Metric; MPN CL21A106KAYNNNE; LCSC C15850
J3: SWD; Samtec_FTSH-105-01-L-DV-K; MPN FTSH-105-01-L-DV-K-TR; LCSC C448647
J4: TC2030_NL; Tag-Connect_TC2030-IDC-NL_2x03_P1.27mm_Vertical
SW17: RESET; SW_Push_1P1T_XKB_TS-1187A; MPN TS-1187A-B-A-B; LCSC C318884
U1: E73-2G4M08S1C; EBYTE_E73-2G4M08S1C; MPN E73-2G4M08S1C; LCSC C356849

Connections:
+3V3: C1.1, C2.1, C3.1, C4.1, C5.1, J3.1 (VTref), J4.1 (VCC), U1.19 (VDD), U1.23 (VDDH); also elsewhere on the board
/ACT_EN: U1.35 (P0.24); also elsewhere on the board
/BAT_nFAULT: U1.36 (P1.00); also elsewhere on the board
/BTN7: U1.40 (P1.04); also elsewhere on the board
/BTN8: U1.42 (P1.06); also elsewhere on the board
/BUZZ_PWM: U1.34 (P0.22); also elsewhere on the board
/CHG_STAT: U1.30 (P0.17); also elsewhere on the board
/FG_ALRT: U1.28 (P0.15); also elsewhere on the board
/I2C0_SCL: U1.14 (P0.06); also elsewhere on the board
/I2C0_SDA: U1.12 (P0.26); also elsewhere on the board
/I2C1_SCL: U1.22 (P0.07); also elsewhere on the board
/I2C1_SDA: U1.20 (P0.12); also elsewhere on the board
/LEVER_S0: U1.3 (P0.03/AIN1); also elsewhere on the board
/LEVER_S1: U1.4 (P0.28/AIN4); also elsewhere on the board
/LEVER_S2: U1.18 (P0.04/AIN2); also elsewhere on the board
/LEVER_S3: U1.15 (P0.05/AIN3); also elsewhere on the board
/MCU/SWDCLK: J3.4 (SWCLK/TCK), J4.4 (SWCLK), U1.39 (SWDCLK)
/MCU/SWDIO: J3.2 (SWDIO/TMS), J4.2 (SWDIO), U1.37 (SWDIO)
/PANEL_INT: U1.1 (P1.11); also elsewhere on the board
/POWER_S0: U1.8 (P0.29/AIN5); also elsewhere on the board
/POWER_S1: U1.9 (P0.31/AIN7); also elsewhere on the board
/POWER_S2: U1.10 (P0.30/AIN6); also elsewhere on the board
/REVERSER_AIN: U1.7 (P0.02/AIN0); also elsewhere on the board
/SOL1_PWM: U1.32 (P0.20); also elsewhere on the board
/SOL2_PWM: U1.33 (P0.13); also elsewhere on the board
/USB_DM: U1.29 (USB_D-); also elsewhere on the board
/USB_DP: U1.31 (USB_D+); also elsewhere on the board
/nRESET: C6.1, J3.10 (~RESET), J4.3 (~RESET), SW17.1, U1.26 (P0.18/RESET); also elsewhere on the board

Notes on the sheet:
3V3 decoupling: C1/C3 at VDD; C2/C4 at VDDH. C5 bulk. VDD = VDDH; DCCH intentionally open.
SWD headers are parallel; VTref is 3V3. SWO is unused. Reset: P0.18 / UICR reset enabled; also resets handle mux. Rev G: P0.20 SOL1, P0.13 SOL2, P0.22 BUZZ; active high. 9 spare GPIOs; calibrated RC LFCLK, no LFXO/NFC. Actuator firmware must default OFF; see ACTUATORS.md.

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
Board: 4 copper layers, 134 parts (0 on the bottom side), 72 nets, no tracks yet.

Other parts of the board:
H1, H2, H3, H4: M3 provisional; MountingHole_3.2mm_M3

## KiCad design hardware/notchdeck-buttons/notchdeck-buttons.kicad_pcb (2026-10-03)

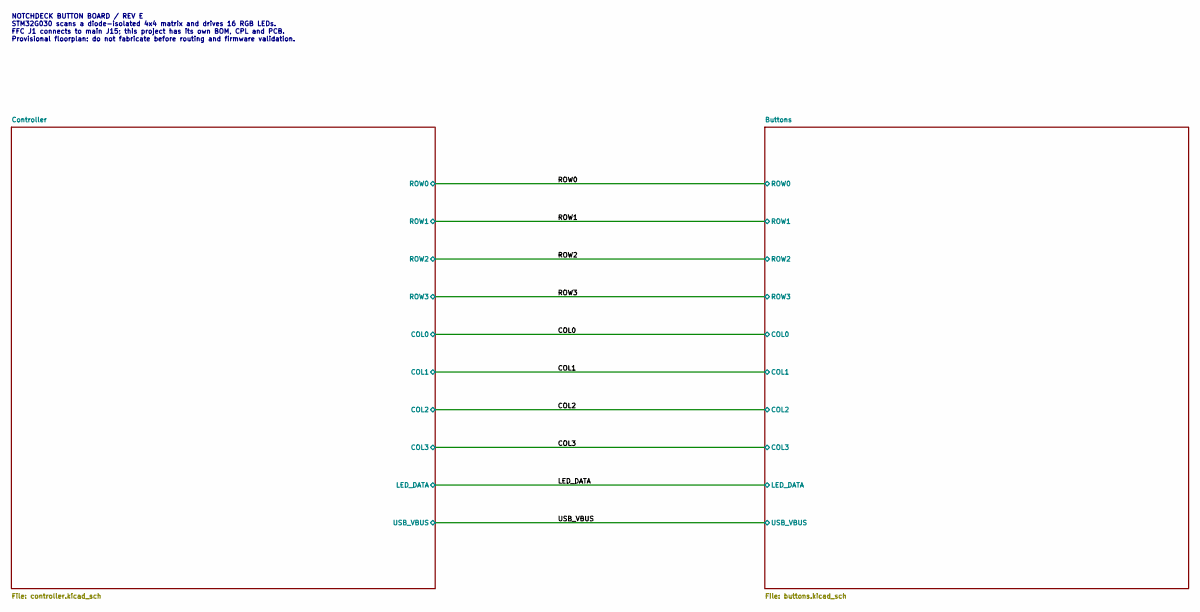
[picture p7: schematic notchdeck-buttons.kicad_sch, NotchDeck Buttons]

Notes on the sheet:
NOTCHDECK BUTTON BOARD / REV E STM32G030 scans a diode-isolated 4x4 matrix and drives 16 RGB LEDs. FFC J1 connects to main J15; this project has its own BOM, CPL and PCB. Provisional floorplan: do not fabricate before routing and firmware validation.

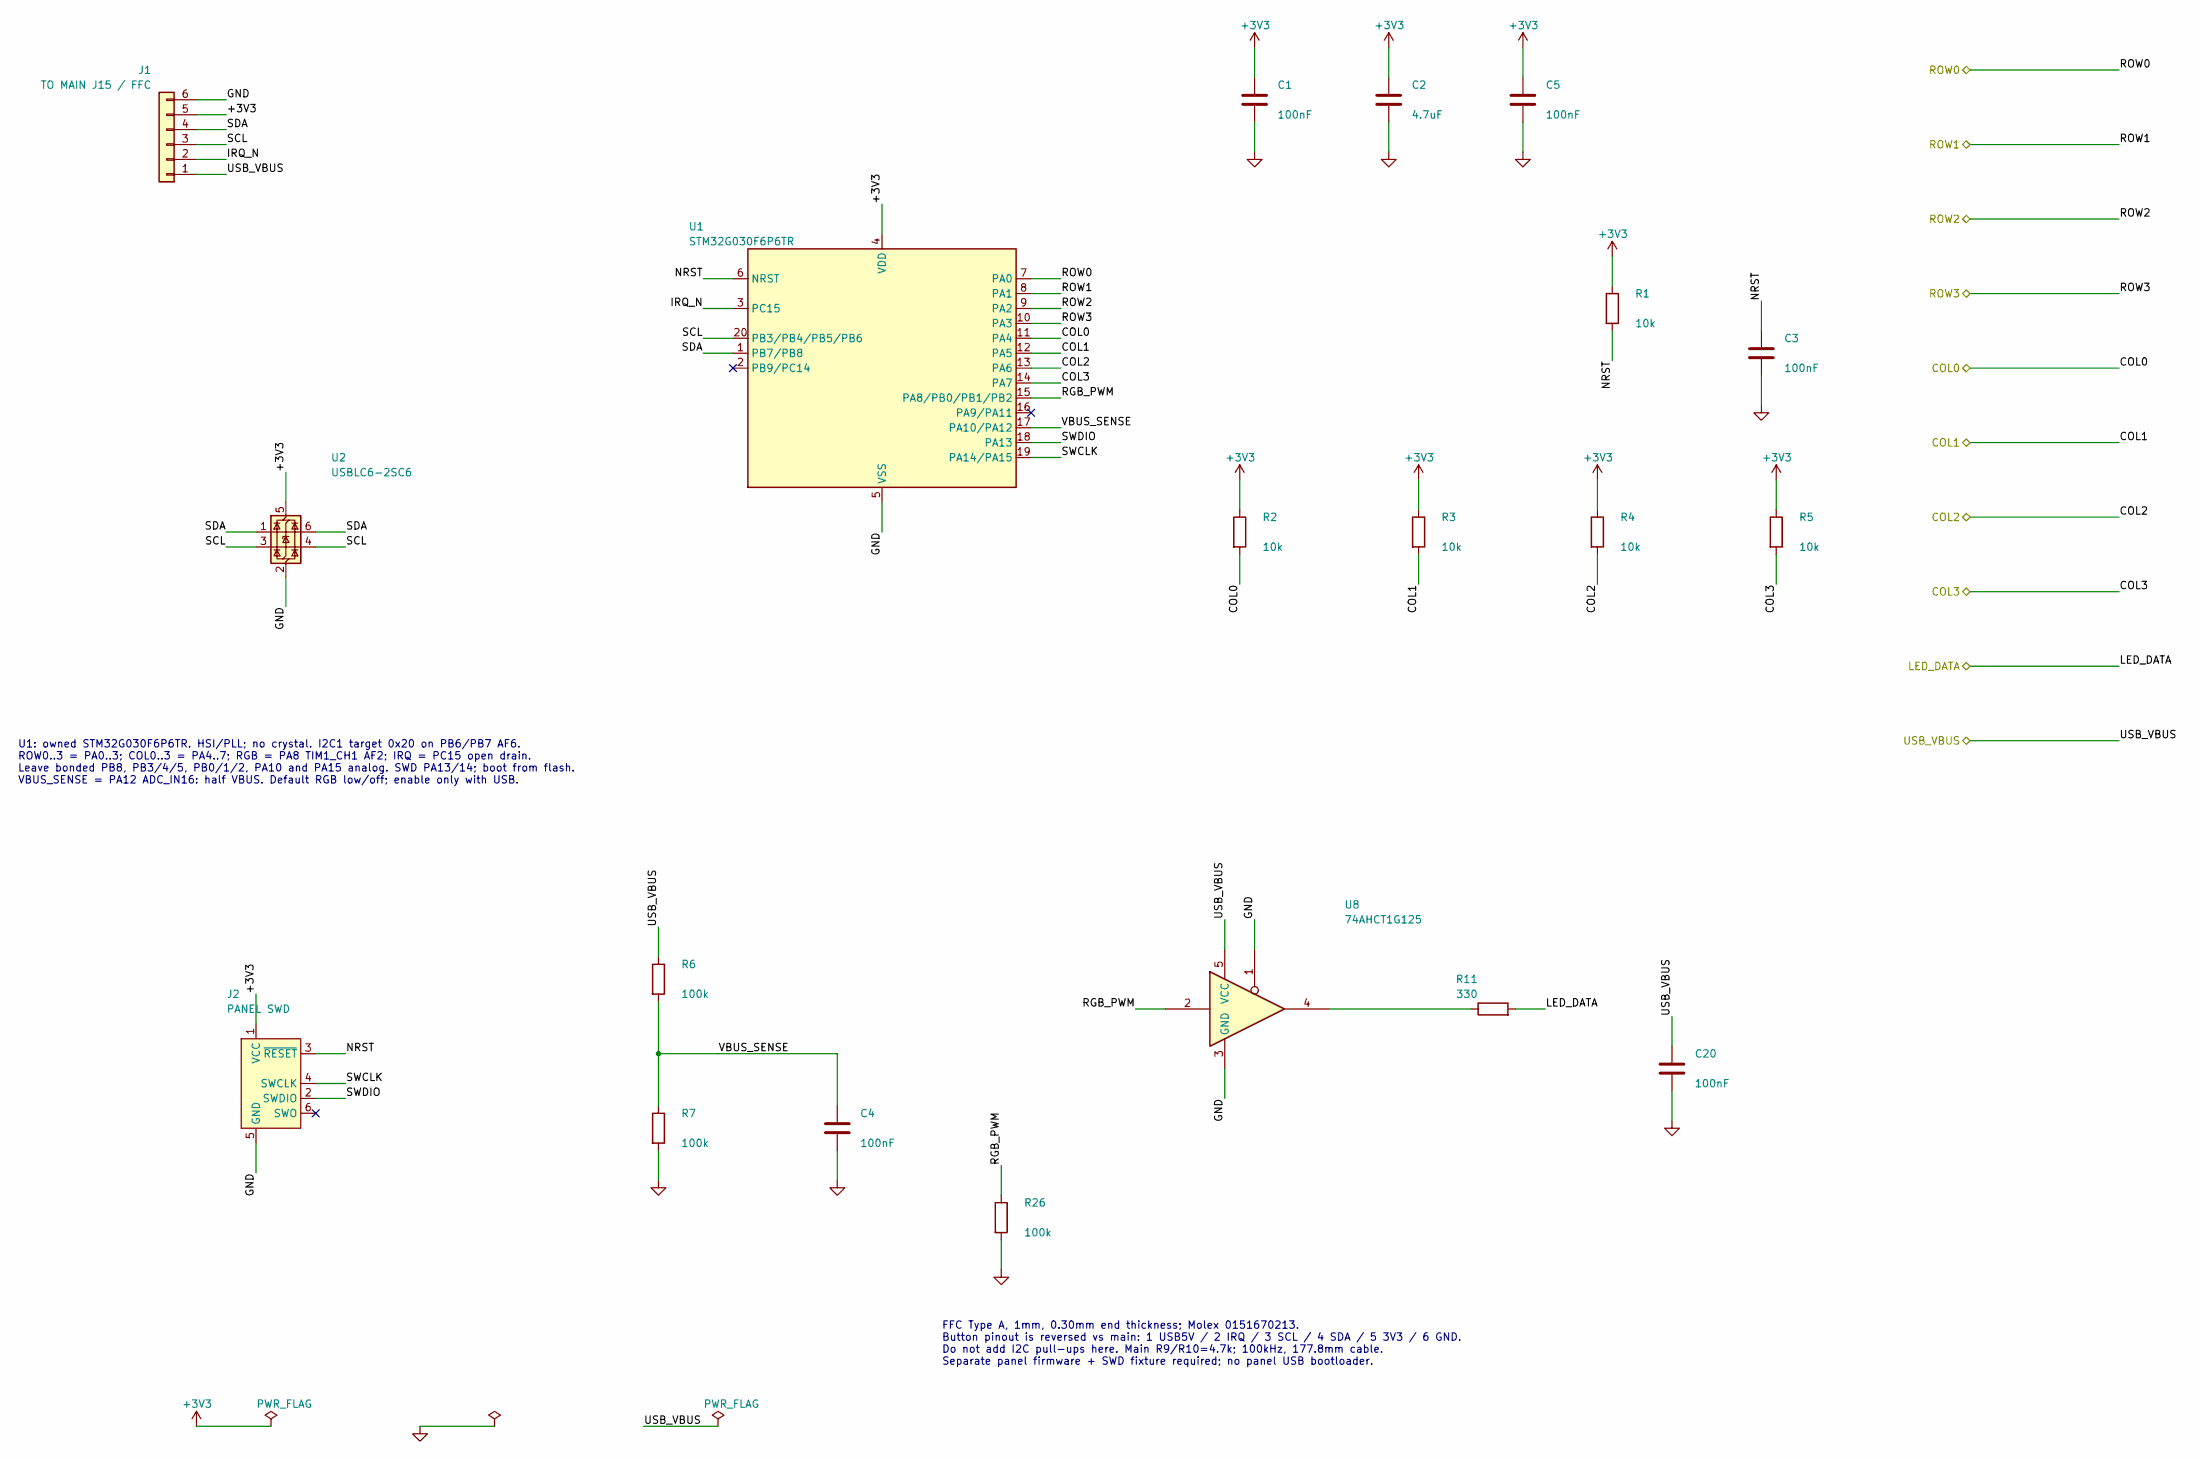
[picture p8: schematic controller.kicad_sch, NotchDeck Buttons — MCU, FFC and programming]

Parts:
C1, C3, C4, C5, C20: 100nF; C_0402_1005Metric; MPN CL05B104KO5NNNC; LCSC C1525
C2: 4.7uF; C_0805_2012Metric; MPN CL21A475KAQNNNE; LCSC C1779
J1: TO MAIN J15 / FFC; JUSHUO_AFA07-S06FCA-00_1x6-1MP_P1.0mm_Horizontal; MPN AFA07-S06FCA-00; LCSC C262712
J2: PANEL SWD; Tag-Connect_TC2030-IDC-NL_2x03_P1.27mm_Vertical
R1, R2, R3, R4, R5: 10k; R_0402_1005Metric; MPN 0402WGF1002TCE; LCSC C25744
R6, R7, R26: 100k; R_0402_1005Metric; MPN 0402WGF1003TCE; LCSC C25741
R11: 330; R_0402_1005Metric; MPN 0402WGF3300TCE; LCSC C25104
U1: STM32G030F6P6TR; TSSOP-20_4.4x6.5mm_P0.65mm; MPN STM32G030F6P6TR; LCSC C529330
U2: USBLC6-2SC6; SOT-23-6; MPN USBLC6-2SC6; LCSC C7519
U8: 74AHCT1G125; SOT-23-5; MPN SN74AHCT1G125DBVR; LCSC C7484

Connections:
/COL0: R2.2, U1.11 (PA4); also elsewhere on the board
/COL1: R3.2, U1.12 (PA5); also elsewhere on the board
/COL2: R4.2, U1.13 (PA6); also elsewhere on the board
/COL3: R5.2, U1.14 (PA7); also elsewhere on the board
/Controller/IRQ_N: J1.2, U1.3 (PC15)
/Controller/NRST: C3.1, J2.3 (~RESET), R1.2, U1.6 (NRST)
/Controller/RGB_PWM: R26.1, U1.15 (PA8/PB0/PB1/PB2), U8.2
/Controller/SCL: J1.3, U1.20 (PB3/PB4/PB5/PB6), U2.3 (I/O2), U2.4 (I/O2)
/Controller/SDA: J1.4, U1.1 (PB7/PB8), U2.1 (I/O1), U2.6 (I/O1)
/Controller/SWCLK: J2.4 (SWCLK), U1.19 (PA14/PA15)
/Controller/SWDIO: J2.2 (SWDIO), U1.18 (PA13)
/Controller/VBUS_SENSE: C4.1, R6.2, R7.1, U1.17 (PA10/PA12)
/LED_DATA: R11.2; also elsewhere on the board
/ROW0: U1.7 (PA0); also elsewhere on the board
/ROW1: U1.8 (PA1); also elsewhere on the board
/ROW2: U1.9 (PA2); also elsewhere on the board
/ROW3: U1.10 (PA3); also elsewhere on the board
unnamed: R11.1, U8.4

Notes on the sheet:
U1: owned STM32G030F6P6TR. HSI/PLL; no crystal. I2C1 target 0x20 on PB6/PB7 AF6. ROW0..3 = PA0..3; COL0..3 = PA4..7; RGB = PA8 TIM1_CH1 AF2; IRQ = PC15 open drain. Leave bonded PB8, PB3/4/5, PB0/1/2, PA10 and PA15 analog. SWD PA13/14; boot from flash. VBUS_SENSE = PA12 ADC_IN16: half VBUS. Default 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
FFC Type A, 1mm, 0.30mm end thickness; Molex 0151670213. Button pinout is reversed vs main: 1 USB5V / 2 IRQ / 3 SCL / 4 SDA / 5 3V3 / 6 GND. Do not add I2C pull-ups here. Main R9/R10=4.7k; 100kHz, 177.8mm cable. Separate panel firmware + SWD fixture required; no panel USB bootloader.

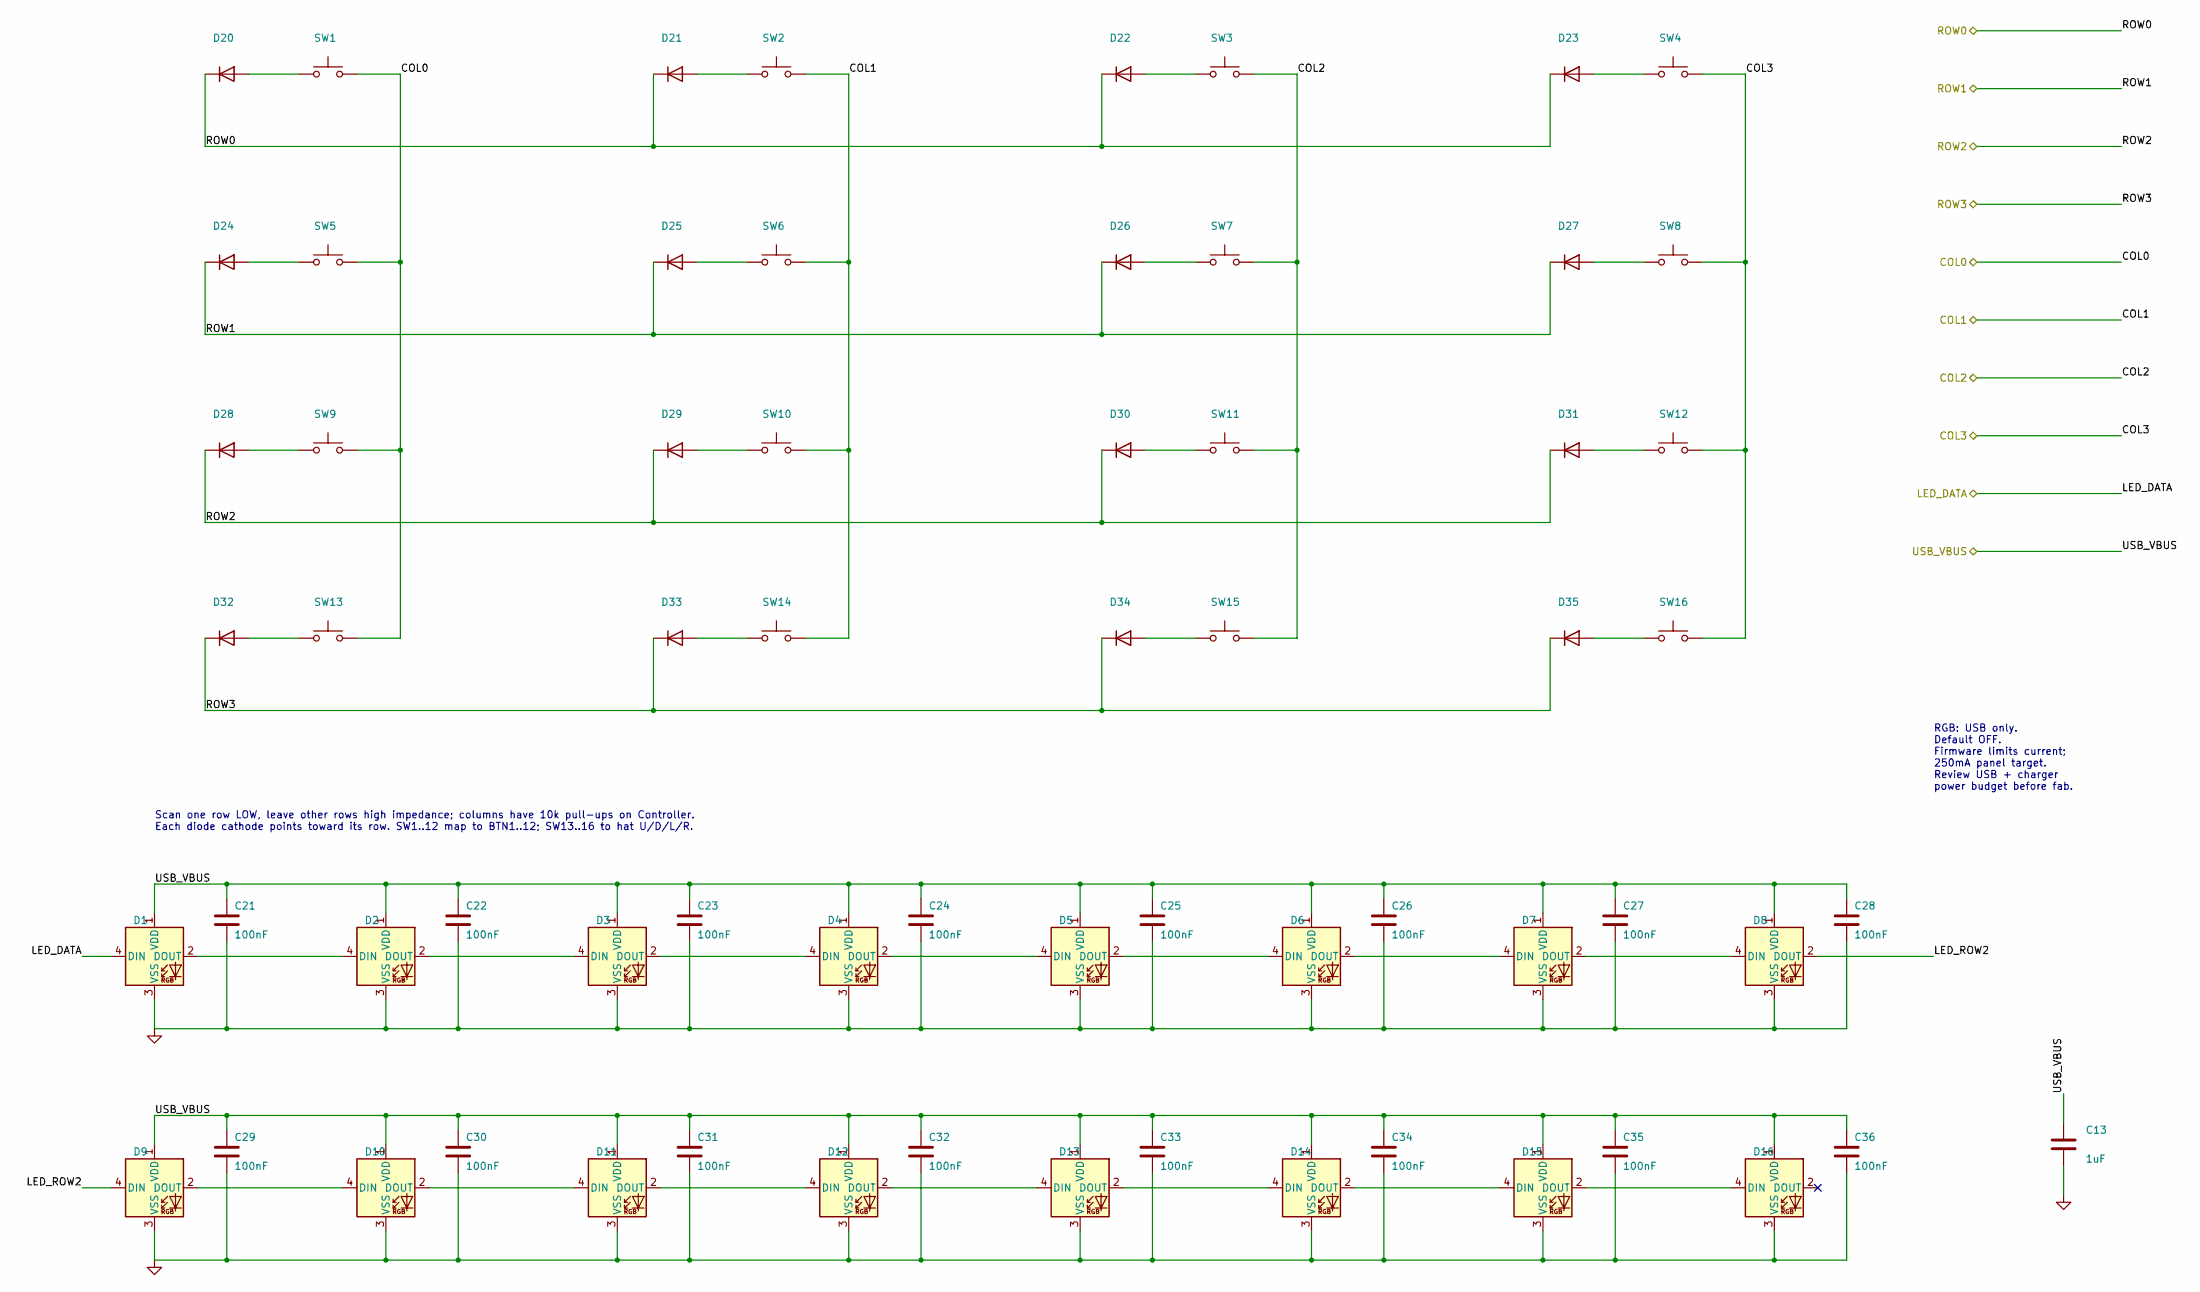
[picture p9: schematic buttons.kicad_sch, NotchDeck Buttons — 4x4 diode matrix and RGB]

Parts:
C13: 1uF; C_0805_2012Metric; MPN CL21B105KBFNNNE; LCSC C28323
C21, C22, C23, C24, C25, C26, C27, C28, C29, C30, C31, C32, C33, C34, C35, C36: 100nF; C_0402_1005Metric; MPN CL05B104KO5NNNC; LCSC C1525
D1, D2, D3, D4, D5, D6, D7, D8, D9, D10, D11, D12, D13, D14, D15, D16: WS2812B; LED_XINGLIGHT_XL-5050RGBC-2812B; MPN XL-5050RGBC-2812B; LCSC C2843785
D20, D21, D22, D23, D24, D25, D26, D27, D28, D29, D30, D31, D32, D33, D34, D35: 1N4148W; D_SOD-123; MPN 1N4148W; LCSC C81598
SW1, SW2, SW3, SW4, SW5, SW6, SW7, SW8, SW9, SW10, SW11, SW12, SW13, SW14, SW15, SW16: SW_Push; SW_Push_1P1T_XKB_TS-1187A; MPN TS-1187A-B-A-B; LCSC C318884

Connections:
/Buttons/LED_ROW2: D8.2 (DOUT), D9.4 (DIN)
/COL0: SW1.2, SW5.2, SW9.2, SW13.2; also elsewhere on the board
/COL1: SW2.2, SW6.2, SW10.2, SW14.2; also elsewhere on the board
/COL2: SW3.2, SW7.2, SW11.2, SW15.2; also elsewhere on the board
/COL3: SW4.2, SW8.2, SW12.2, SW16.2; also elsewhere on the board
/LED_DATA: D1.4 (DIN); also elsewhere on the board
/ROW0: D20.1 (K), D21.1 (K), D22.1 (K), D23.1 (K); also elsewhere on the board
/ROW1: D24.1 (K), D25.1 (K), D26.1 (K), D27.1 (K); also elsewhere on the board
/ROW2: D28.1 (K), D29.1 (K), D30.1 (K), D31.1 (K); also elsewhere on the board
/ROW3: D32.1 (K), D33.1 (K), D34.1 (K), D35.1 (K); also elsewhere on the board
unnamed: D1.2 (DOUT), D2.4 (DIN)
unnamed: D2.2 (DOUT), D3.4 (DIN)
unnamed: D3.2 (DOUT), D4.4 (DIN)
unnamed: D4.2 (DOUT), D5.4 (DIN)
unnamed: D5.2 (DOUT), D6.4 (DIN)
unnamed: D6.2 (DOUT), D7.4 (DIN)
unnamed: D7.2 (DOUT), D8.4 (DIN)
unnamed: D9.2 (DOUT), D10.4 (DIN)
unnamed: D10.2 (DOUT), D11.4 (DIN)
unnamed: D11.2 (DOUT), D12.4 (DIN)
unnamed: D12.2 (DOUT), D13.4 (DIN)
unnamed: D13.2 (DOUT), D14.4 (DIN)
unnamed: D14.2 (DOUT), D15.4 (DIN)
unnamed: D15.2 (DOUT), D16.4 (DIN)
unnamed: D20.2 (A), SW1.1
unnamed: D21.2 (A), SW2.1
unnamed: D22.2 (A), SW3.1
unnamed: D23.2 (A), SW4.1
unnamed: D24.2 (A), SW5.1
unnamed: D25.2 (A), SW6.1
unnamed: D26.2 (A), SW7.1
unnamed: D27.2 (A), SW8.1
unnamed: D28.2 (A), SW9.1
unnamed: D29.2 (A), SW10.1
unnamed: D30.2 (A), SW11.1
unnamed: D31.2 (A), SW12.1
unnamed: D32.2 (A), SW13.1
unnamed: D33.2 (A), SW14.1
unnamed: D34.2 (A), SW15.1
unnamed: D35.2 (A), SW16.1

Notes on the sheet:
Scan one row LOW, leave other rows high impedance; columns have 10k pull-ups on Controller. Each diode cathode points toward its row. SW1..12 map to BTN1..12; SW13..16 to hat U/D/L/R.
RGB: USB only. Default OFF. Firmware limits current; 250mA panel target. Review USB + charger power budget before fab.

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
Board: 2 copper layers, 89 parts (0 on the bottom side), 52 nets, no tracks yet.

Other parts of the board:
H1, H2, H3, H4: M3 provisional; MountingHole_3.2mm_M3

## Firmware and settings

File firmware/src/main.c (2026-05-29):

/*
 * NotchDeck One — application entry / transport arbitration.
 * SKELETON. Picks USB when VBUS is present, otherwise BLE HOGP (spec policy:
 * "USB takes priority when connected"). Then runs the report loop at ~125 Hz.
 *
 * TODO: handle live VBUS plug/unplug to switch transports at runtime (this
 *       skeleton chooses once at boot); add battery (BAS) updates.
 */
#include "report.h"
#include "report_engine.h"
#include "transport.h"
#include "leds.h"
#include "lever.h"
#include "dfu.h"

#include <zephyr/kernel.h>
#include <zephyr/logging/log.h>
#include <hal/nrf_power.h>

LOG_MODULE_REGISTER(main, LOG_LEVEL_INF);

#define REPORT_PERIOD_MS  8   /* ~125 Hz */

enum { MODE_USB, MODE_BLE } mode;

static void on_output_report(const struct notchdeck_out_report *out)
{
	report_engine_apply_output(out);
}

static bool vbus_present(void)
{
	return nrf_power_usbregstatus_vbusdet_get(NRF_POWER);
}

int main(void)
{
	LOG_INF("NotchDeck One starting");

	leds_init();
	report_engine_init();

	/* Hold Select + Start (HID buttons 7 & 8) at power-on to drop into the
	 * USB UF2 update drive — the no-physical-reset path to firmware update. */
	{
		struct notchdeck_in_report boot;

		report_engine_build(&boot);
		if ((boot.buttons & (BIT(6) | BIT(7))) == (BIT(6) | BIT(7))) {
			notchdeck_enter_dfu();   /* does not return */
		}
	}

	if (vbus_present()) {
		mode = MODE_USB;
		transport_usb_init(on_output_report);
		leds_set_link_state(LINK_USB);
		LOG_INF("transport: USB");
	} else {
		mode = MODE_BLE;
		transport_ble_init(on_output_report);
		leds_set_link_state(LINK_BLE_ADV);
		LOG_INF("transport: BLE");
	}

	struct notchdeck_in_report rep;
	enum notchdeck_notch last_notch = NOTCH_COUNT;   /* force first paint */

	while (1) {
		report_engine_build(&rep);

		if (mode == MODE_USB) {
			if (transport_usb_ready()) {
				transport_usb_send(&rep);
			}
		} else {
			if (transport_ble_connected()) {
				transport_ble_send(&rep);
				leds_set_link_state(LINK_BLE_CONNECTED);
			}
		}

		enum notchdeck_notch n = lever_get_notch();

		if (n != last_notch) {
			leds_show_notch(n);
			last_notch = n;
		}

		k_msleep(REPORT_PERIOD_MS);
	}
	return 0;
}

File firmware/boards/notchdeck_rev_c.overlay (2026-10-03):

/* Rev C/D E73 module mapping. Apply as DTC_OVERLAY_FILE, replacing the DK overlay.
 * Board platform remains DK for SDK bring-up; bootloader/USB IDs still provisional. */
#include <zephyr/dt-bindings/gpio/gpio.h>
#include <zephyr/dt-bindings/pinctrl/nrf-pinctrl.h>
#include <zephyr/dt-bindings/i2c/i2c.h>

&pinctrl {
    notchdeck_i2c0_default: notchdeck_i2c0_default {
        group1 { psels = <NRF_PSEL(TWIM_SDA, 0, 26)>, <NRF_PSEL(TWIM_SCL, 0, 6)>; };
    };
    notchdeck_i2c0_sleep: notchdeck_i2c0_sleep {
        group1 { psels = <NRF_PSEL(TWIM_SDA, 0, 26)>, <NRF_PSEL(TWIM_SCL, 0, 6)>; low-power-enable; };
    };
    notchdeck_i2c1_default: notchdeck_i2c1_default {
        group1 { psels = <NRF_PSEL(TWIM_SDA, 0, 12)>, <NRF_PSEL(TWIM_SCL, 0, 7)>; };
    };
    notchdeck_i2c1_sleep: notchdeck_i2c1_sleep {
        group1 { psels = <NRF_PSEL(TWIM_SDA, 0, 12)>, <NRF_PSEL(TWIM_SCL, 0, 7)>; low-power-enable; };
    };
};
&i2c0 {
    compatible = "nordic,nrf-twim";
    status = "okay";
    clock-frequency = <I2C_BITRATE_STANDARD>;
    pinctrl-0 = <&notchdeck_i2c0_default>;
    pinctrl-1 = <&notchdeck_i2c0_sleep>;
    pinctrl-names = "default", "sleep";
};
&i2c1 {
    compatible = "nordic,nrf-twim";
    status = "okay";
    clock-frequency = <I2C_BITRATE_STANDARD>;
    pinctrl-0 = <&notchdeck_i2c1_default>;
    pinctrl-1 = <&notchdeck_i2c1_sleep>;
    pinctrl-names = "default", "sleep";
};
/* TWIM1 and SPIM1 share hardware: reserve instance 1 for the fuel gauge.
 * Future RGB SPI pinctrl must use instance 2/3. Disable DK UART pin conflicts. */
&spi0 { status = "disabled"; };
&spi1 { status = "disabled"; };
&uart0 { status = "disabled"; };
&uart1 { status = "disabled"; };
&spi3 { status = "disabled"; };
&pwm0 { status = "disabled"; };
&qspi { status = "disabled"; };
&nfct { status = "disabled"; };
&uicr { gpio-as-nreset; nfct-pins-as-gpios; };
&gpio0 {
    gpio-reserved-ranges = <18 1>;
    /delete-property/ gpio-line-names;
};
&gpio1 { /delete-property/ gpio-line-names; };
/ {
    /delete-node/ buttons;
    /delete-node/ leds;
    /delete-node/ pwmleds;
    aliases {
        /delete-property/ led0;
        /delete-property/ led1;
        /delete-property/ led2;
        /delete-property/ led3;
        /delete-property/ pwm-led0;
        /delete-property/ sw0;
        /delete-property/ sw1;
        /delete-property/ sw2;
        /delete-property/ sw3;
        /delete-property/ mcuboot-button0;
        /delete-property/ mcuboot-led0;
    };
    buttons: buttons {
        compatible = "gpio-keys";
        btn1 { gpios = <&gpio1 11 (GPIO_ACTIVE_LOW | GPIO_PULL_UP)>; };
        btn2 { gpios = <&gpio1 10 (GPIO_ACTIVE_LOW | GPIO_PULL_UP)>; };
        btn3 { gpios = <&gpio1 13 (GPIO_ACTIVE_LOW | GPIO_PULL_UP)>; };
        btn4 { gpios = <&gpio1 9 (GPIO_ACTIVE_LOW | GPIO_PULL_UP)>; };
        btn5 { gpios = <&gpio0 20 (GPIO_ACTIVE_LOW | GPIO_PULL_UP)>; };
        btn6 { gpios = <&gpio0 13 (GPIO_ACTIVE_LOW | GPIO_PULL_UP)>; };
        btn7 { gpios = <&gpio1 4 (GPIO_ACTIVE_LOW | GPIO_PULL_UP)>; };
        btn8 { gpios = <&gpio1 6 (GPIO_ACTIVE_LOW | GPIO_PULL_UP)>; };
        btn9 { gpios = <&gpio0 9 (GPIO_ACTIVE_LOW | GPIO_PULL_UP)>; };
        btn10 { gpios = <&gpio0 10 (GPIO_ACTIVE_LOW | GPIO_PULL_UP)>; };
        btn11 { gpios = <&gpio0 0 (GPIO_ACTIVE_LOW | GPIO_PULL_UP)>; };
        btn12 { gpios = <&gpio0 1 (GPIO_ACTIVE_LOW | GPIO_PULL_UP)>; };
    };
    handle_inputs {
        compatible = "gpio-keys";
        brake_s0: brake_s0 { gpios = <&gpio0 3 GPIO_ACTIVE_HIGH>; };
        brake_s1: brake_s1 { gpios = <&gpio0 28 GPIO_ACTIVE_HIGH>; };
        brake_s2: brake_s2 { gpios = <&gpio0 4 GPIO_ACTIVE_HIGH>; };
        brake_s3: brake_s3 { gpios = <&gpio0 5 GPIO_ACTIVE_HIGH>; };
        power_s0: power_s0 { gpios = <&gpio0 29 GPIO_ACTIVE_HIGH>; };
        power_s1: power_s1 { gpios = <&gpio0 31 GPIO_ACTIVE_HIGH>; };
        power_s2: power_s2 { gpios = <&gpio0 30 GPIO_ACTIVE_HIGH>; };
    };
};

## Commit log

2026-05-29 Initial research + dual-mode (USB/BLE) HID emulation spec
    Document the Zuiki Mascon / MasconPro and Densha de GO! lineage findings,
    and frame a driverless dual-transport master-controller on nRF52840:
    unified HID report descriptor, notch-axis encoding, button/hat map,
    LED/lamp output reports, and firmware/hardware architecture.
2026-05-29 Add JLCPCB/LCSC sourcing for nRF SoC options
    nRF52840-QIAA (C190794, ~1.2k stock, $3.80, Extended) is assemblable;
    Ebyte E73-2G4M08S1C module (C2764963) recommended for prototype to avoid
    RF/antenna/cert work; nRF52833-QDAA (QFN-40) noted as easier fallback.
2026-05-29 Add BOM sourcing doc; clarify E73 antenna variants
    - New docs/04-bom-sourcing.md: JLCPCB availability for power path, USB-C,
    lever sensor, LEDs, with part numbers/stock and discrete-power fallback.
    - Correct E73 variants: C356849 = onboard ceramic antenna (integrated),
    C2764963 = ...CX u.FL external. Recommend C356849 for prototype.
    - Note Raytac MDBT50Q / Insight ISP1807 as pre-cert modules not in JLCPCB.
2026-05-29 Name the project: NotchDeck (device: NotchDeck One)
    - Rebrand docs from 'BenchBits Master Controller' working title to NotchDeck,
    a BenchBits product; this one-handle unit is 'NotchDeck One'.
    - USB/BLE product string -> 'NotchDeck One'.
    - Add NAMING.md: rationale, trademark posture, domains (notchdeck.com/.io
    available), and pocket alternatives (NotchBits/NotchCab/NotchRail).
    Note: repo working directory renamed benchbits-master-controller -> notchdeck.
2026-05-29 Scaffold firmware (Zephyr) and hardware (KiCad) projects
    Firmware (nRF Connect SDK / Zephyr) — SKELETON, not yet built:
    - Shared HID report descriptor (hid_descriptor.h) used by both transports
    - lever.c: AS5600 angle -> canonical notch byte (spec §4) with hysteresis
    - report_engine, USB HID + BLE HOGP transports, WS2812 LED subsystem, main
    - prj.conf / CMakeLists / nRF52840 DK overlay
    Hardware (KiCad 10) — patterned on tsumikoro/pulsarfab:
    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
    [notchdeck-one.kicad_pcb, notchdeck-one.kicad_sch]
2026-05-29 Verify E73 exposes USB (pads 27/29/31) — dual-mode confirmed
    Ebyte's pin-definition table confirms the E73-2G4M08S1C breaks out the
    nRF52840 USB lines: pad 27 VBS (VBUS), 29 D-, 31 D+. Clears the blocking
    item; no parts change, bare-chip fallback unneeded. Updated PARTS.md and
    hardware/README accordingly.
2026-05-29 Vendor non-stdlib parts: E73 symbol/footprint/3D + AS5600/MAX17048 symbols
    - E73-2G4M08S1C: footprint (43 pads) + STEP vendored from joric/nrfmicro
    (public domain), upgraded to KiCad 10, 3D relinked; symbol extracted from
    nrfmicro schematic, repointed to notchdeck:EBYTE_E73-2G4M08S1C, BOM props.
    - AS5600: symbol authored from ams datasheet pinout (1 VDD5V,2 VDD3V3,3 OUT,
    4 GND,5 PGO,6 SDA,7 SCL,8 DIR); stdlib SOIC-8 footprint + shipped 3D.
    - MAX17048: symbol authored from ADI datasheet (1 CTG,2 CELL,3 VDD,4 GND,
    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
2026-05-29 Add E73 net plan + firmware-update (USB programmability) strategy
    - hardware/NETPLAN.md: full 43-pad E73 -> peripheral assignment. Resolves the
    AS5600/MAX17048 0x36 I2C address collision via two TWIM buses; documents the
    nRF power tree (VDD=VDDH=3V3, DCCH NC, VBUS for USB+detect), USB-C wiring,
    buttons/hat, WS2812, reverser, charger/fuel-gauge, SWD/reset, decoupling,
    and flags not-yet-BOM'd parts (power-path P-FET, USB TVS).
    - docs/05-firmware-update.md: user upgrades via UF2 drag-and-drop bootloader
    (primary, double-tap reset), BLE OTA DFU (secondary), SWD (factory/recovery);
    build artifacts (.uf2 family 0xADA52840), Adafruit-UF2 vs MCUboot decision,
    and the signed-image secur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
2026-05-29 Set up firmware updates + host test + CI
    Updates (docs/05): CONFIG_BUILD_OUTPUT_UF2 emits .uf2; dfu.c enters the UF2
    bootloader via GPREGRET magic (0x57); main.c boot-combo (Select+Start) drops
    into the update drive; VERSION file + BLE DIS firmware-revision; firmware
    Makefile (build/flash/uf2/release/test).
    Test: test/host_report_test.c compiles with a plain host cc (no Zephyr) and
    asserts the wire contract (7-byte reports, lever on byte 4, report IDs, DFU
    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
2026-05-29 Pin NCS to v3.3.0 (latest stable) for builds/CI
2026-05-29 Firmware builds on NCS v3.3 (nrf52840dk): dual USB+BLE + UF2
    First successful west build. Fixes from the real toolchain:
    - prj.conf: BT_HIDS needs CONFIG_BT_CONN_CTX=y (root of the conn_ctx.h
    compile error) + INPUT/OUTPUT_REP_MAX, ATTR_MAX, GATT pool sizes; drop
    the undefined WS2812_STRIP symbol; fix BT_DEVICE_APPEARANCE inline comment.
    - transport_ble.c: BT_LE_ADV_CONN (removed in Zephyr 4.x) -> BT_LE_ADV_CONN_FAST_2;
    add settings.h include.
    - DK overlay: disable WS2812/SPI node + led-strip alias (no pinctrl on DK);
    leds.c uses its no-strip fallback. Re-enabled on the custom board.
    Result: FLASH 20.7% / RAM 17.5% of nRF52840; emits zephyr.uf2.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
2026-05-29 CI: fix hardware-checks (run kicad container as root; kicad-cli direct; checkout v5)
    The kicad image runs as a non-root user, so actions/checkout couldn't write
    the runner temp (EACCES). Run that container with --user root, call kicad-cli
    directly instead of make (image may lack make), and bump checkout to v5.
2026-05-29 CI: make empty-scaffold ERC/BOM non-fatal (KiCad image vs authoring version skew)
    Container KiCad 10.0.0 can't load the scaffold .kicad_sch authored by 10.0.3
    (format 20260306). Library validation (sym/fp upgrade) stays fatal; ERC/BOM on
    the empty schematic now emit a warning instead of failing. Re-tighten once real
    schematic capture lands on a matching KiCad.
2026-05-30 Document lever-sensor trade-off + cam/Gray-code switch alternative
    - NETPLAN: 'Lever sensing — two front-ends'. AS5600 (default) with the
    drift analysis (ratiometric angle, notch spacing >> error, detent parks
    at band center); plus Option 2 cam + 4 Gray-coded switches (DRV5032 Hall
    or SS-5GL snap), incl. the 15-notch 4-bit Gray map and GPIO assignment.
    - PARTS: alternative lever front-end parts (DRV5032FB / SS-5GL), stock checked.
    - lever.c: note the sensor choice is contained in this file (swap = rewrite
    lever_get_notch() only).
    [lever.c]
2026-06-22 Add schgen schematic workflow + flatten extends symbols
    Brings notchdeck onto the data-manifest schematic workflow (scripts/kschgen.py
    + notchdeck-one.schgen.py, Makefile gen/check/render targets, project skills,
    CLAUDE.md) and commits the generated hierarchical child sheets (mcu/power/
    lever/controls), which were previously untracked.
    kschgen fix: flatten extends-based symbols. kicad-cli's SVG/PDF exporters don't
    resolve (extends ...), so derived symbols (e.g. the TC2030-NL SWD connector)
    rendered blank. _flattened_block() now inlines the parent's graphics/pins,
    renamed to the child, dropping the extends — so generated sheets render
    correctly outside eeschema. (Same fix landed in ephemer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
    [controls.kicad_sch, lever.kicad_sch, mcu.kicad_sch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]
2026-07-01 jlcpcb-package: fix BOM/CPL matching + support THT assembly
    Ported from ephemerkey after a JLCPCB order flagged mismatched parts:
    - BOM: export individual designators (--ref-range-delimiter "") — JLCPCB does not
    expand ranges like R18-R20, so grouped SMD parts were silently NOT placed.
    - CPL: --exclude-dnp (match the BOM) and drop mounting holes/fiducials (H*/MH/FID).
    - Include through-hole footprints so JST/THT connectors can be JLC-assembled
    (JLCPCB Economic handles THT). Opt specific parts out of BOM+CPL via an optional
    <name>-handsolder.txt (e.g. bare pin headers you hand-solder).
2026-07-02 jlcpcb-package: drop exclude_from_bom footprints from the CPL
    Footprints flagged (attr ... exclude_from_bom) in the PCB — solder jumpers,
    Tag-Connect programming pads, test points — carry no LCSC part number, so
    JLCPCB can't assemble them. They were already absent from the BOM but still
    emitted to the CPL, which makes JLCPCB reject the order with '<ref>
    designators don't exist in the BOM file'. Parse the PCB's footprint (attr)
    blocks and exclude those refs from the CPL too, alongside the existing
    mounting-hole/fiducial and hand-solder drops.
    Ported from the confirmed-good fix in tsumikoro.
2026-07-06 Add schematic wiring notes support
    [controls.kicad_sch, lever.kicad_sch, mcu.kicad_sch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]
2026-07-06 Harden schematic render script
2026-07-06 Apply shared schematic note placement tweak
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2026-07-06 kschgen: add multi-channel wiring extensions (fleet sync)
    Merge the wiring/multi-channel emitters (pin_geom, pin_at/pin_named,
    w_wire/w_junction/w_label/w_hlabel/w_glabel, net_pin, w_symbol, w_sheet,
    write_wired_child, write_root) into the shared engine so kschgen.py is
    identical across all sibling repos. Placement + _flattened_block behaviour
    here is unchanged; the extensions are additive (used by wired boards such
    as the calcumaker display).
2026-10-03 Wire and verify NotchDeck controller schematics
    [controls.kicad_sch, lever.kicad_sch, mcu.kicad_sch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]
2026-10-03 Add verified provisional controller PCB floorplan
    [controls.kicad_sch, lever.kicad_sch, mcu.kicad_sch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]
2026-10-03 Source controller BOM from JLCPCB and align selected footprints
    [bom.csv, controls.kicad_sch, jlcpcb-bom.csv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]
2026-10-03 Verify public JLCPCB stock for all controller BOM parts
    [jlcpcb-stock.csv]
2026-10-03 Record five-board stock coverage and shared inventory location
    [jlcpcb-stock.csv]
2026-10-03 Normalize stock CSV line endings
    [jlcpcb-stock.csv]
2026-10-03 Support independent magnetic and Gray-coded power and brake handles
    [bom.csv, controls.kicad_sch, jlcpcb-bom.csv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]
2026-10-03 Pin compatible KiCad CI image and separate root sheet labels
    [controls.kicad_sch, lever.kicad_sch, mcu.kicad_sch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]
2026-10-03 Initialize KiCad library tables for strict headless checks
2026-10-03 Add keyed harnesses and build plan for Japanese-style dual and mascon handles
    [bom.csv, controls.kicad_sch, detents-and-cams.csv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]
2026-10-03 Split controller buttons onto stocked STM32G030 panel PCB
    [bom.csv, buttons.kicad_sch, controller.kicad_sch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]
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2026-10-05 Add protected PWM actuator outputs and charger interlock
    [actuators.kicad_sch, bom.csv, controls.kicad_sch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]
2026-10-05 Protect full battery input and size dual 2A impulse outputs
    [actuators.kicad_sch, bom.csv, controls.kicad_sch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]
